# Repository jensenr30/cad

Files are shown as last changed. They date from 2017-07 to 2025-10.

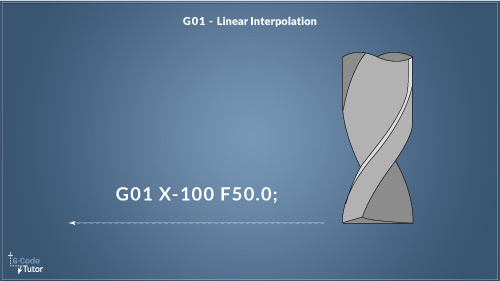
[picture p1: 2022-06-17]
cheatsheets/CNC G Codes_files/g01-gcode.jpg

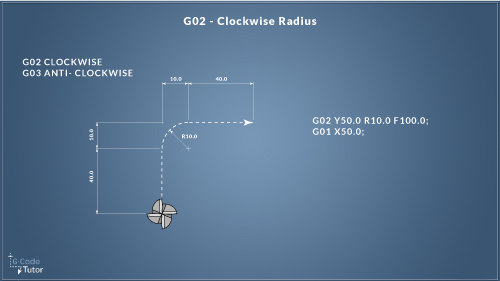
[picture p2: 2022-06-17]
cheatsheets/CNC G Codes_files/g02-g03-gcode.jpg

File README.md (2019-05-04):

# Ryan's CAD Files (Schematics, PCBs, Simulations)

## kicad5
I started using KiCad 5.1.2 to draw schematics and lay out PCBs in May 2019.

## kicad4
I used KiCad 4.0.6 for 3 weeks in September 2017. The two projects I completed are:
* [Shift-Register Break-Out-Board](/kicad4/SRBOB) - A modular daisy-chain-able serial-in-parallel-out 74hc595-based shift register circuit board.
* [XPhone Input Board](/kicad4/XPhone/Input_Board) - A quad transducer amplifier and glockenspiel-key-hit-detection circuit board.

## eagle6
Eagle was the first CAD program I ever used. I started using Eagle (on version 5.11.0) sometime in early 2011. I stopped on version 6.6.0 in mid 2017.  Some of the more interesting projects I completed using Eagle are:
* [Analog Synth](eagle6/Analog%20Synth) - a bunch of analog (and digital) DIY synth modules.  Designed, built, and tested by your truly.  This includes VCOs, VCFs, VCAs, sequencers, front-panel designs, digital delay, manual oscillators, and power-distribution interconnect PCBs.
* [Stroboscope](eagle6/Stroboscope) - a device that can turn on and off LEDs very fast (at audio frequencies) in order to produce interesting/useful/helpful visual effects.  A stroboscope can be used to enable a human to monitor the rotation of things in real time, e.g. fans, drills, wheels, motors, spinning objects, guitar strings, and any other object engaged in cyclic motion.
* [VU Meter](eagle6/VU%20meter) - a circuit that represents audio amplitude vertically on several bargraphs (each bargraph displays the amplitude of a given section of the audio spectrum).  The device can be used to build a real-time visual audio spectrum analyzer.
* [FreqCount84](eagle6/FreqCount84) - Atmel microcontroller-based design for precise measurement of frequency of square waves.  I believe the hwardware & firmware achieved an accuracy of ± a few ppm with the help of a 1.5 pm TCXO.
* [9x9 LED Matrix](eagle6/9x9%20LED%20Matrix) - a 2D array of LEDs (9 LEDs wide, 9 LEDs tall).  I remember wanting to build an array that had an odd number of pixels because it would allow me to make symetric visual displays.  I programmed a game of pong for this 9x9 LED Matrix.  That code exists in [my repo for Arduino programs](https://github.com/jensenr30/Arduino/tree/master/_DISPLAY/9x9_LED_Matrix).
* [Prototype Boards](eagle6/Prototype%20Boards) - three PCBs that enable DIY circuit construction.  0.1"-arrays of SMD pads, 0.1"-arrays of through-holes, SOT-to-DIP break-out-boards, SOIC-to-DIP break-out-boards, etc...

## LTspice IV
I have used [LTspice](https://en.wikipedia.org/wiki/LTspice) version IV to simulate some of my circuits.

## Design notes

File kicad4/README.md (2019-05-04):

# Jensen's KiCAD Projects
I Use KiCad 4 to view/edit my schematics, PCBs, symbols, and footprints.

I Use [gerbv](http://gerbv.geda-project.org/) to view the Gerber files.

I usually generate .pdf files for all my schematics and Gerber files once they are finished, so I can often view my schematics and layouts without having to install KiCad or gerbv.

## library
A collection of KiCad 4 schematic symbols.

## modules
A collection of KiCad 4 PCB footprints.

## XPhone
This is a collection of schematics and PCBs that are used as components of an electric xylophone (technically a glockenspiel).

### Input_Board
This is a module that will do process the input signals. The input signals are transduced by "pickup" coils mounted beneath each xylophone key. The input board:
- Amplifies the signal generated by the xylophone key
- detects the amplitude of the key hit (envelope detector circuit: a "super-diode" and a cap and a bleeder-resistor)
- outputs a pulse when the key is hit (hit detection pulse for a microcontroller to record what is being played by the user)

## SRBOB
This is a shift-register break-out-board. It is a modular, easily expandable shift register board. Each PCB has 4 SRBOB modules that must be cut apart. Each module can be populated with up to 4 74HC595 logic chips. The modules can be "daisy-chained" together to create

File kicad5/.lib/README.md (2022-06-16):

# Ryan Jensen's Custom KiCad 5 Library

Resist the temptation to rename files.

## Directories

| Directory  | Description of Directory |
| --- | --- |
| library | schematic symbols |
| modules | PCB footprints |
| packages3d | 3D models |

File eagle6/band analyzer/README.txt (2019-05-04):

I did not create this schematic, nor do I own this schematic.

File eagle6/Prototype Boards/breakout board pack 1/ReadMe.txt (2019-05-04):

I don't like how I routed the wires on the bottom for the SOIC-16.
That really sucks. I did not look close enough the first time.

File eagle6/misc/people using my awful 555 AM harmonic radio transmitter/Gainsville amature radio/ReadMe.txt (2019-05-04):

holy shit these people actually put my piece of shit circuit into their newsletter.
That is really pathetic.
The circuit was garbage.

But then again, it was fun.

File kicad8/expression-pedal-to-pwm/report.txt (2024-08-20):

Update symbol J5 from 'Connector:Screw_Terminal_01x06' to 'Connector:Screw_Terminal_01x06': OK

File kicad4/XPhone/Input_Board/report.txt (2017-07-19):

Info: Reading netlist file "A:\Engineering\kicad\XPhone\Input_Board\Input Board.net".

Info: Using references to match components and footprints.

Info: Checking netlist component footprint "C1:/5960E627:Capacitors_SMD:C_0603_HandSoldering".

Changing component "C1:/5960E627" pin "2" net name from "+12V" to "-12V".

Info: Checking netlist component footprint "C2:/5960E62D:Capacitors_SMD:C_0603_HandSoldering".

Changing component "C2:/5960E62D" pin "2" net name from "+12V" to "-12V".

Info: Checking netlist component footprint "C3:/593C8C44:Capacitors_SMD:C_0603_HandSoldering".

Info: Checking netlist component footprint "C4:/595F20F1:Capacitors_SMD:C_0603_HandSoldering".

Info: Checking netlist component footprint "C5:/5960E633:Capacitors_SMD:C_0603_HandSoldering".

Changing component "C5:/5960E633" pin "2" net name from "+12V" to "-12V".

Info: Checking netlist component footprint "C6:/5960E639:Capacitors_SMD:C_0603_HandSoldering".

Changing component "C6:/5960E639" pin "2" net name from "+12V" to "-12V".

Info: Checking netlist component footprint "C7:/593C8FC2:Capacitors_SMD:C_0603_HandSoldering".

Info: Checking netlist component footprint "C8:/595F20F7:Capacitors_SMD:C_0603_HandSoldering".

Info: Checking netlist component footprint "C9:/5960E64D:Capacitors_SMD:C_0603_HandSoldering".

Changing component "C9:/5960E64D" pin "2" net name from "+12V" to "-12V".

Info: Checking netlist component footprint "C10:/5960E653:Capacitors_SMD:C_0603_HandSoldering".

Changing component "C10:/5960E653" pin "2" net name from "+12V" to "-12V".

Info: Checking netlist component footprint "C11:/593CE812:Capacitors_SMD:C_0603_HandSoldering".

Info: Checking netlist component footprint "C12:/595F95F5:Capacitors_SMD:C_0603_HandSoldering".

Changing component "C12:/595F95F5" pin "2" net name from "+12V" to "-12V".

Info: Checking netlist component footprint "C13:/593CA10D:Capacitors_SMD:C_0603_HandSoldering".

Info: Checking netlist component footprint "C14:/595F2134:Capacitors_SMD:C_0603_HandSoldering".

Info: Checking netlist component footprint "C15:/593CA537:Capacitors_SMD:C_0603_HandSoldering".

Info: Checking netlist component footprint "C16:/595F2140:Capacitors_SMD:C_0603_HandSoldering".

Info: Checking netlist component footprint "C17:/595F675C:Capacitors_SMD:C_0603_HandSoldering".

Info: Checking netlist component footprint "C18:/595F7369:Capacitors_Tantalum_SMD:CP_Tantalum_Case-B_EIA-3528-21_Wave".

Info: Checking netlist component footprint "C19:/595F1A5B:Capacitors_SMD:C_0603_HandSoldering".

Info: Checking netlist component footprint "C20:/595F3A33:Capacitors_SMD:C_0603_HandSoldering".

Info: Checking netlist component footprint "C21:/595F1A61:Capacitors_SMD:C_0603_HandSoldering".

Info: Checking netlist component footprint "C22:/595F3A39:Capacitors_SMD:C_0603_HandSoldering".

Info: Checking netlist component footprint "C23:/595F1A9E:Capacitors_SMD:C_0603_HandSoldering".

Info: Checking netlist component footprint "C24:/595F3A76:Capacitors_SMD:C_0603_HandSoldering".

Info: Checking netlist component footprint "C25:/595F1AAA:Capacitors_SMD:C_0603_HandSoldering".

Info: Checking netlist component footprint "C26:/595F3A82:Capacitors_SMD:C_0603_HandSoldering".

Info: Checking netlist component footprint "J1:/593CBF86:Pin_Headers:Pin_Header_Straight_1x01_Pitch2.54mm".

Info: Checking netlist component footprint "J2:/595F21A5:Pin_Headers:Pin_Header_Straight_1x01_Pitch2.54mm".

Info: Checking netlist component footprint "J3:/593CC2F3:Pin_Headers:Pin_Header_Straight_1x01_Pitch2.54mm".

Info: Checking netlist component footprint "J4:/595F21B2:Pin_Headers:Pin_Header_Straight_1x01_Pitch2.54mm".

Info: Checking netlist component footprint "J5:/593CC6F7:Pin_Headers:Pin_Header_Straight_1x01_Pitch2.54mm".

Info: Checking netlist component footprint "J6:/595F21B8:Pin_Headers:Pin_Header_Straight_1x01_Pitch2.54mm".

Info: Checking netlist component footprint "J7:/595F1B0F:Pin_Headers:Pin_Header_Straight_1x01_Pitch2.54mm".

Info: Checking netlist component footprint "J8:/595F3AE7:Pin_Headers:Pin_Header_Straight_1x01_Pitch2.54mm".

Info: Checking netlist component footprint "J9:/595F1B1C:Pin_Headers:Pin_Header_Straight_1x01_Pitch2.54mm".

Info: Checking netlist component footprint "J10:/595F3AF4:Pin_Headers:Pin_Header_Straight_1x01_Pitch2.54mm".

Info: Checking netlist component footprint "J11:/595F1B22:Pin_Headers:Pin_Header_Straight_1x01_Pitch2.54mm".

Info: Checking netlist component footprint "J12:/595F3AFA:Pin_Headers:Pin_Header_Straight_1x01_Pitch2.54mm".

Info: Checking netlist component footprint "J13:/5969566C:Pin_Headers:Pin_Header_Straight_1x03_Pitch2.54mm".

Changing component "J13:/5969566C" pin "3" net name from "+12V" to "-12V".

Info: Checking netlist component footprint "J14:/59698210:Pin_Headers:Pin_Header_Straight_1x03_Pitch2.54mm".

Changing component "J14:/59698210" pin "3" net name from "+12V" to "-12V".

Info: Checking netlist component footprint "L1:/593C96E8:Pin_Headers:Pin_Header_Straight_1x02_Pitch2.54mm".

Info: Checking netlist component footprint "L2:/595F210F:Pin_Headers:Pin_Header_Straight_1x02_Pitch2.54mm".

Info: Checking netlist component footprint "L3:/595F1A79:Pin_Headers:Pin_Header_Straight_1x02_Pitch2.54mm".

Info: Checking netlist component footprint "L4:/595F3A51:Pin_Headers:Pin_Header_Straight_1x02_Pitch2.54mm".

Info: Checking netlist component footprint "Q1:/593C7DD5:TO_SOT_Packages_SMD:SOT-323_SC-70_Handsoldering".

Info: Checking netlist component footprint "Q2:/595F20EB:TO_SOT_Packages_SMD:SOT-323_SC-70_Handsoldering".

Info: Checking netlist component footprint "Q3:/593CA6EF:TO_SOT_Packages_SMD:SOT-323_SC-70_Handsoldering".

Info: Checking netlist component footprint "Q4:/595F2152:TO_SOT_Packages_SMD:SOT-323_SC-70_Handsoldering".

Info: Checking netlist component footprint "Q5:/595F1A55:TO_SOT_Packages_SMD:SOT-323_SC-70_Handsoldering".

Info: Checking netlist component footprint "Q6:/595F3A2D:TO_SOT_Packages_SMD:SOT-323_SC-70_Handsoldering".

Info: Checking netlist component footprint "Q7:/595F1ABC:TO_SOT_Packages_SMD:SOT-323_SC-70_Handsoldering".

Info: Checking netlist component footprint "Q8:/595F3A94:TO_SOT_Packages_SMD:SOT-323_SC-70_Handsoldering".

Info: Checking netlist component footprint "R1:/593C94A2:Resistors_SMD:R_0603_HandSoldering".

Info: Checking netlist component footprint "R2:/595F2103:Resistors_SMD:R_0603_HandSoldering".

Info: Checking netlist component footprint "R3:/593CC107:Resistors_SMD:R_0603_HandSoldering".

Info: Checking netlist component footprint "R4:/595F21AB:Resistors_SMD:R_0603_HandSoldering".

Info: Checking netlist component footprint "R5:/593C930A:Resistors_SMD:R_0603_HandSoldering".

Info: Checking netlist component footprint "R6:/595F20FD:Resistors_SMD:R_0603_HandSoldering".

Info: Checking netlist component footprint "R7:/595FC853:Resistors_SMD:R_0603_HandSoldering".

Info: Checking netlist component footprint "R8:/593CA5BF:Resistors_SMD:R_0603_HandSoldering".

Info: Checking netlist component footprint "R9:/595F2146:Resistors_SMD:R_0603_HandSoldering".

Info: Checking netlist component footprint "R10:/593CA779:Resistors_SMD:R_0603_HandSoldering".

Info: Checking netlist component footprint "R11:/593CA670:Resistors_SMD:R_0603_HandSoldering".

Info: Checking netlist component footprint "R12:/595F2158:Resistors_SMD:R_0603_HandSoldering".

Info: Checking netlist component footprint "R13:/595F214C:Resistors_SMD:R_0603_HandSoldering".

Info: Checking netlist component footprint "R14:/593CA7ED:Resistors_SMD:R_0603_HandSoldering".

Info: Checking netlist component footprint "R15:/595F215E:Resistors_SMD:R_0603_HandSoldering".

Info: Checking netlist component footprint "R16:/593CB19A:Resistors_SMD:R_0603_HandSoldering".

Info: Checking netlist component footprint "R17:/595F2196:Resistors_SMD:R_0603_HandSoldering".

Info: Checking netlist component footprint "R18:/595F1A6D:Resistors_SMD:R_0603_HandSoldering".

Info: Checking netlist component footprint "R19:/595F3A45:Resistors_SMD:R_0603_HandSoldering".

Info: Checking netlist component footprint "R20:/595F1B15:Resistors_SMD:R_0603_HandSoldering".

Info: Checking netlist component footprint "R21:/595F3AED:Resistors_SMD:R_0603_HandSoldering".

Info: Checking netlist component footprint "R22:/595F1A67:Resistors_SMD:R_0603_HandSoldering".

Info: Checking netlist component footprint "R23:/595F3A3F:Resistors_SMD:R_0603_HandSoldering".

Info: Checking netlist component footprint "R24:/595F1AB0:Resistors_SMD:R_0603_HandSoldering".

Info: Checking netlist component footprint "R25:/595F3A88:Resistors_SMD:R_0603_HandSoldering".

Info: Checking netlist component footprint "R26:/595F1AC2:Resistors_SMD:R_0603_HandSoldering".

Info: Checking netlist component footprint "R27:/595F1AB6:Resistors_SMD:R_0603_HandSoldering".

Info: Checking netlist component footprint "R28:/595F3A9A:Resistors_SMD:R_0603_HandSoldering".

Info: Checking netlist component footprint "R29:/595F3A8E:Resistors_SMD:R_0603_HandSoldering".

Info: Checking netlist component footprint "R30:/595F1AC8:Resistors_SMD:R_0603_HandSoldering".

Info: Checking netlist component footprint "R31:/595F3AA0:Resistors_SMD:R_0603_HandSoldering".

Info: Checking netlist component footprint "R32:/595F1B00:Resistors_SMD:R_0603_HandSoldering".

Info: Checking netlist component footprint "R33:/595F3AD8:Resistors_SMD:R_0603_HandSoldering".

Info: Checking netlist component footprint "RV1:/593C956D:Potentiometers:Potentiometer_Trimmer_Bourns_3296W".

Info: Checking netlist component footprint "RV2:/595F212D:Potentiometers:Potentiometer_Trimmer_Bourns_3296W".

Info: Checking netlist component footprint "RV3:/595F1A97:Potentiometers:Potentiometer_Trimmer_Bourns_3296W".

Info: Checking netlist component footprint "RV4:/595F3A6F:Potentiometers:Potentiometer_Trimmer_Bourns_3296W".

Info: Checking netlist component footprint "U1:/593C797A:Housings_DIP:DIP-8_W7.62mm".

Changing component "U1:/593C797A" pin "4" net name from "+12V" to "-12V".

Info: Checking netlist component footprint "U2:/59620FB2:TO_SOT_Packages_THT:TO-92_Inline_Narrow_Oval".

Info: Checking netlist component footprint "U3:/593CCBBC:SMD_Packages:SOIC-14_N".

Changing component "U3:/593CCBBC" pin "11" net name from "+12V" to "-12V".

Info: Checking netlist component footprint "U4:/593CBADD:Housings_DIP:DIP-14_W7.62mm".

Info: Checking netlist component footprint "U5:/595F1A4F:Housings_DIP:DIP-8_W7.62mm".

Changing component "U5:/595F1A4F" pin "4" net name from "+12V" to "-12V".

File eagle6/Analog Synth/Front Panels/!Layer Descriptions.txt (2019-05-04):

 44	Drills
 
100	FrontPanel
		This is an outline that shows how large the panel will be
		
101	PartProfile
		This is the layer that shows the size of the components behind the panel.
		It helps to see how close components can be packed together without hitting each other.
		
102	PanelSupportRails
		(the boards that the front panels connect to )
		
103	MiscProfile

104 PanelText
		this has all of the text that will show up on the finished front panel

105 Artwork
		This is the layer that contains all panel artwork

110 hole_size
		This layer contains a bunch of text that indicates what diameter the holes are.

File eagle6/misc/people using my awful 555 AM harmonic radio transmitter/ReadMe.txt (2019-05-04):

2018-06-11
Ryan Jensen

I have so much less respect for these organizations/websites now.
I see they will post articles about articles about electronics radios that are not designed properly.
Just goes to show that the internet is a echo chamber of people reposting other people's bullshit.
You really have to be skeptical.
Because people will write with authority about stuff that doesn't fucking work.

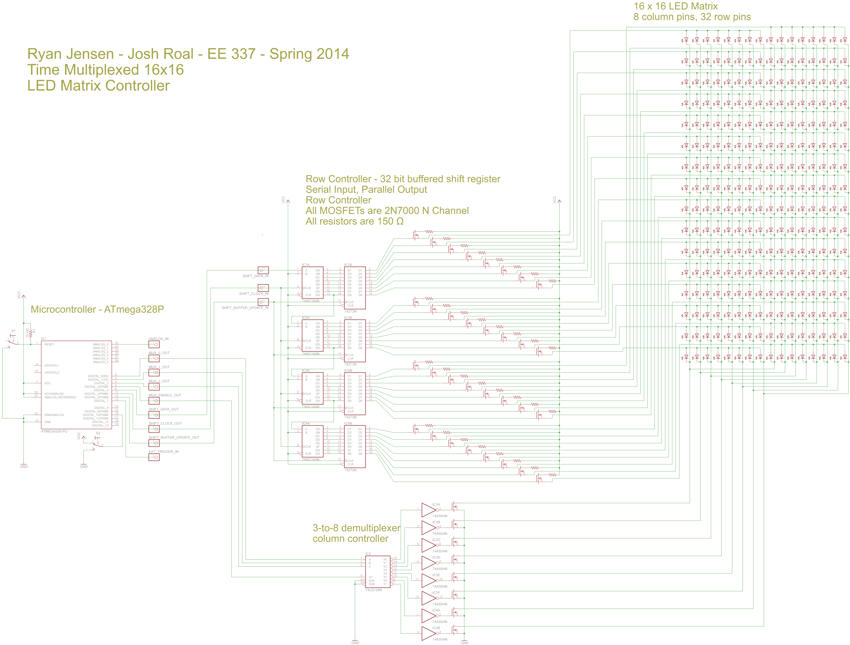
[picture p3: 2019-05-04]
eagle6/Digital Oscilloscope - EE 337 - Junior Design Project/ScreenshotSmall.png

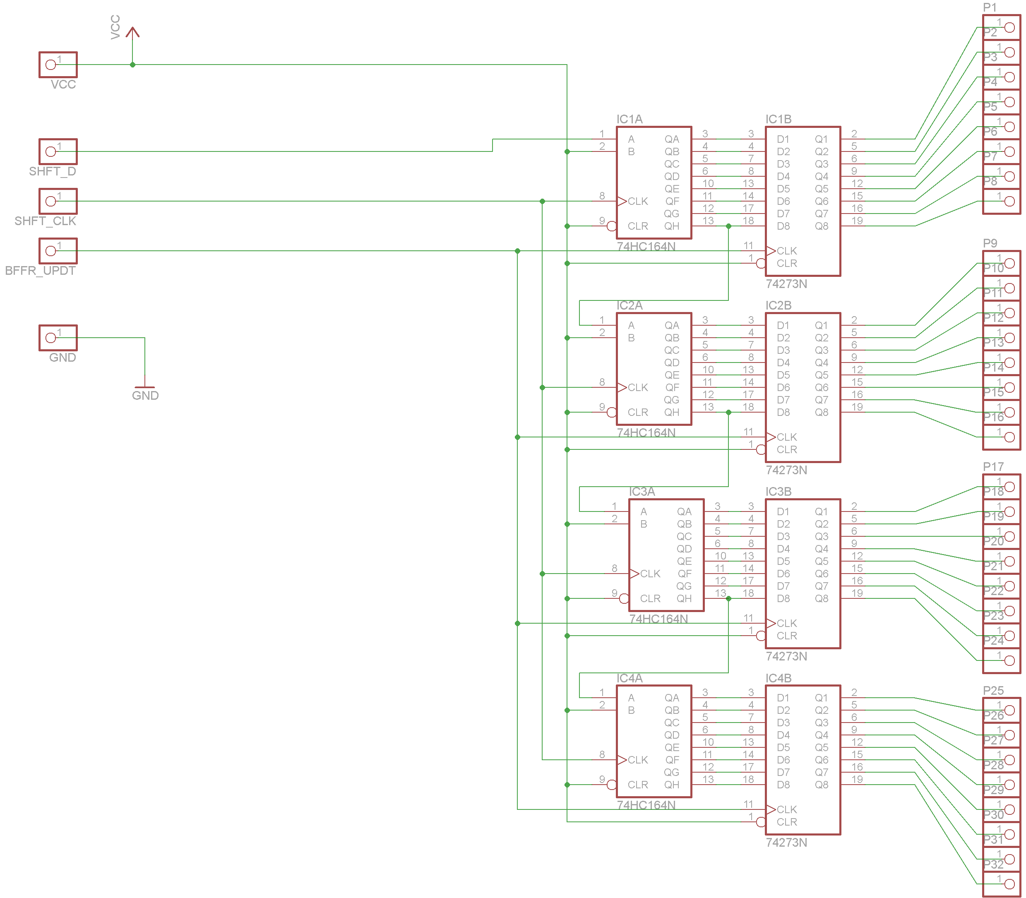
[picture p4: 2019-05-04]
eagle6/32 bit buffered shift register/Schematic.png

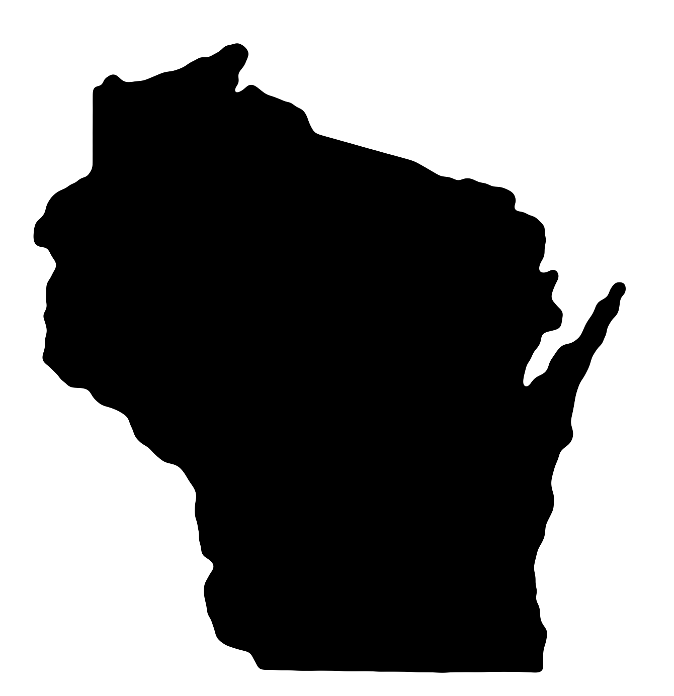
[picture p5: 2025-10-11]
src/geography/u.s. states/wisconsin/wisconsin-silhouette-smooth-2.png

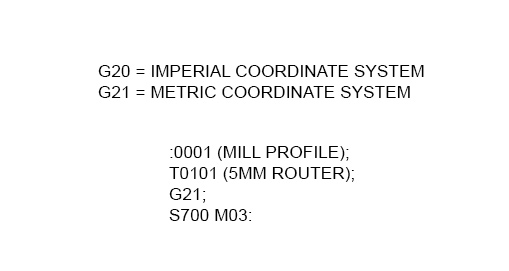
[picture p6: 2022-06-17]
cheatsheets/CNC G Codes_files/g20-g21-gcode.jpg

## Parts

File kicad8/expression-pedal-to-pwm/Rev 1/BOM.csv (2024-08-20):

Reference | Value | Datasheet | Footprint | Qty | DNP
C1 C3 C9 | 10u | ~ | Capacitor_THT:CP_Radial_D5.0mm_P2.50mm | 3
C2 C4 C6 C7 C10 | 100n | ~ | Capacitor_SMD:C_0603_1608Metric_Pad1.08x0.95mm_HandSolder | 5
C5 | 10n | ~ | Capacitor_SMD:C_0603_1608Metric_Pad1.08x0.95mm_HandSolder | 1
C8 | 47n | ~ | Capacitor_SMD:C_0603_1608Metric_Pad1.08x0.95mm_HandSolder | 1
C11 | 1000u | ~ | Capacitor_THT:CP_Radial_D10.0mm_P5.00mm | 1
D1 | RB088LAM-60TR | ~ | Diode_SMD:D_SOD-128 | 1
D2 D3 D4 D5 D6 D7 | SK18 | https://diotec.com/request/datasheet/sk12.pdf | Diode_SMD:D_SMA | 6
D8 D9 | LED | ~ | LED_THT:LED_D3.0mm_Horizontal_O3.81mm_Z6.0mm | 2
HS1 | Heatsink | https://www.mouser.com/datasheet/2/433/board-level-heatsink-wakefield-275537.pdf | Heatsink:Heatsink_Fischer_SK104-STCB_35x13mm__2xDrill3.5mm_ScrewM3 | 1
J4 | NMJ6HHD2 | https://www.neutrik.com/en/product/nmj6hhd2 | Connector_Audio:Jack_6.35mm_Neutrik_NMJ6HHD2_Horizontal | 1
J5 | Screw_Terminal_01x06 | ~ | TerminalBlock_MetzConnect:TerminalBlock_MetzConnect_Type086_RT03406HBLC_1x06_P3.81mm_Horizontal | 1
Q1 | STP100N8F6 | https://www.mouser.com/datasheet/2/389/stp100n8f6-1851325.pdf | Package_TO_SOT_THT:TO-220-3_Vertical | 1
R1 R2 | 100K | ~ | Resistor_SMD:R_0603_1608Metric_Pad0.98x0.95mm_HandSolder | 2
R3 | 1K | ~ | Resistor_SMD:R_0603_1608Metric_Pad0.98x0.95mm_HandSolder | 1
R4 R5 R8 R9 | 1k | ~ | Resistor_SMD:R_0603_1608Metric_Pad0.98x0.95mm_HandSolder | 4
R6 | 100 | ~ | Resistor_SMD:R_0603_1608Metric_Pad0.98x0.95mm_HandSolder | 1
R7 | 1M | ~ | Resistor_SMD:R_0603_1608Metric_Pad0.98x0.95mm_HandSolder | 1
RV1 RV2 RV3 | 100k | ~ | -- mixed values -- | 3
SW1 SW2 | SW_Push_DPDT | ~ | Button_Switch_THT:SW_E-Switch_EG2219_DPDT_Angled | 2
U1 | TLV2374 | ~ | Package_SO:SOIC-14_3.9x8.7mm_P1.27mm | 1
U2 | LM7805_TO220 | https://www.onsemi.cn/PowerSolutions/document/MC7800-D.PDF | Package_TO_SOT_THT:TO-220-3_Vertical | 1

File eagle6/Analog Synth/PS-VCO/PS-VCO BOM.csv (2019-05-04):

Qty | Value | Device | Package | Parts | Description
1 | EURORACK-POWER | EURORACK-POWER | EURORACK-POWER | U$3
1 | I/O | MONO_JACK | MONO_JACK | SQUARE
1 | 180k | R-US_R0603 | R0603 | R8 | RESISTOR, American symbol
1 | 1.8k | R-US_R0603 | R0603 | R7 | RESISTOR, American symbol
5 | 100k | R-US_R0603 | R0603 | R6, R9, R10, R13, R15 | RESISTOR, American symbol
1 | 120k | R-US_R0603 | R0603 | R5 | RESISTOR, American symbol
1 | 27k | R-US_R0603 | R0603 | R4 | RESISTOR, American symbol
1 | 33k | R-US_R0603 | R0603 | R22 | RESISTOR, American symbol
1 | 3.3k | R-US_R0603 | R0603 | R20 | RESISTOR, American symbol
1 | 4.7k | R-US_R0603 | R0603 | R19 | RESISTOR, American symbol
3 | 2.2k | R-US_R0603 | R0603 | R16, R17, R18 | RESISTOR, American symbol
1 | 68k | R-US_R0603 | R0603 | R14 | RESISTOR, American symbol
2 | 4.7 | R-US_R0603 | R0603 | R11, R12 | RESISTOR, American symbol
4 | 47k | R-US_R0603 | R0603 | R1, R2, R3, R21 | RESISTOR, American symbol
1 | 2N7000 | 2N7000 | 2N7000 | Q5
2 | 2N3904 | 2N3904 | TO92 | Q3, Q4 | NPN TRANSISTOR
1 | 2N3906 | 2N3906 | TO92 | Q2 | PNP Transistor
1 | BC847BS | BC847BS | SOT363_PHILIPS | Q1 | NPN general purpose double transistor
2 |  | LED_ELD260 | LED_LD260 | LED1, LED2 | LED
1 |  | PINHD-2X5 | 2X05 | JP2 | PIN HEADER
1 | TL084D | TL084D | SO14 | IC1 | OP AMP
1 | 100k lin | TRIM_US-B64Y | B64Y | FREQ | POTENTIOMETER
1 | CV | MONO_JACK | MONO_JACK | CV
1 | 10n | C-EUC0603 | C0603 | C6 | CAPACITOR, European symbol
2 | 100u | CPOL-USE2.5-7 | E2,5-7 | C4, C7 | POLARIZED CAPACITOR, American symbol
1 | 100p | C-EUC0603 | C0603 | C3 | CAPACITOR, European symbol
5 | 100n | C-EUC0603 | C0603 | C1, C2, C5, C8, C9 | CAPACITOR, European symbol

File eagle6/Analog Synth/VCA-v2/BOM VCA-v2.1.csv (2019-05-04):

Qty | Value | Device | Package | Parts | Description
2 | 0.01µ | C-EUC0603 | C0603 | C6, C7 | CAPACITOR, European symbol
5 | 100k | R-US_R0603 | R0603 | R5, R13, R21, R22, R23 | RESISTOR, American symbol
2 | 100k Log | TRIM_US-B64Y | B64Y | AUDIO-LVL, CV-LVL | POTENTIOMETER
2 | 100µ | C-US025-050X050 | C025-050X050 | C2, C3 | CAPACITOR, American symbol
2 | 10K | R-US_R0603 | R0603 | R17, R19 | RESISTOR, American symbol
2 | 10k | R-US_R0603 | R0603 | R8, R12 | RESISTOR, American symbol
1 | 10k Lin | TRIM_US-B64Y | B64Y | CV-MAN | POTENTIOMETER
1 | 10k TRIM | TRIM_US-B64Y | B64Y | BALANCE | POTENTIOMETER
1 | 10µ | C-US025-050X050 | C025-050X050 | C1 | CAPACITOR, American symbol
2 | 1K | R-US_R0603 | R0603 | R15, R16 | RESISTOR, American symbol
1 | 2.2K | R-US_R0603 | R0603 | R14 | RESISTOR, American symbol
1 | 2.2k | R-US_R0603 | R0603 | R4 | RESISTOR, American symbol
2 | 3.3k | R-US_R0603 | R0603 | R20, R24 | RESISTOR, American symbol
5 | 47k | R-US_R0603 | R0603 | R2, R9, R10, R11, R18 | RESISTOR, American symbol
2 | 6.8k | R-US_R0603 | R0603 | R1, R3 | RESISTOR, American symbol
2 | 7.5 | R-US_R0603 | R0603 | R6, R7 | RESISTOR, American symbol
1 | DMMT3904W | DMMT3904W | SOT363 | T1
1 | EURORACK-POWER | EURORACK-POWER | EURORACK-POWER | U$1
3 | I/O | MONO_JACK | MONO_JACK | AUDIO-IN, AUDIO-OUT, CV-IN
1 | DSC2001 | DSC2001 | SOT23-BEC | T2 | NPN Transistror
1 | TL084D | TL084D | SO14 | IC2 | OP AMP
3 | TLLG4400 | TLLG4400 | LED3MM | LED-AUDIO-IN, LED-AUDIO-OUT, LED-CV | Low Current (2mA) LED 3 mm Tinted Diffused Package color GREEN

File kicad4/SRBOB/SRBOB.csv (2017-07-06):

Reference | Value | Footprint | Datasheet
U1 | 74HC595 | Housings_DIP:DIP-16_W7.62mm
U2 | 74LS595 | Housings_DIP:DIP-16_W7.62mm
U3 | 74LS595 | Housings_DIP:DIP-16_W7.62mm
U4 | 74LS595 | Housings_DIP:DIP-16_W7.62mm
J3 | CONN_01X08 | Pin_Headers:Pin_Header_Straight_1x08_Pitch2.54mm
J4 | CONN_01X08 | Pin_Headers:Pin_Header_Straight_1x08_Pitch2.54mm
J5 | CONN_01X08 | Pin_Headers:Pin_Header_Straight_1x08_Pitch2.54mm
J6 | CONN_01X08 | Pin_Headers:Pin_Header_Straight_1x08_Pitch2.54mm
J1 | CONN_01X08 | Pin_Headers:Pin_Header_Straight_1x08_Pitch2.54mm
J2 | CONN_01X08 | Pin_Headers:Pin_Header_Straight_1x08_Pitch2.54mm

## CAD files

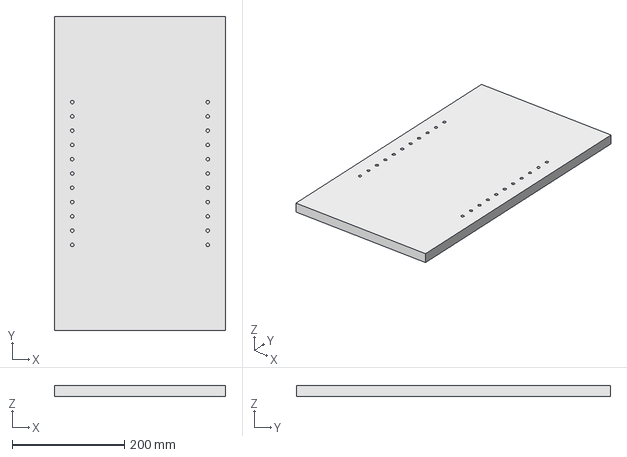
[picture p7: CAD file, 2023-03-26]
FreeCad/woodworking/cabinet-side-holes/cabinet-side-holes.FCStd
304.8 x 558.8 x 19.0 mm

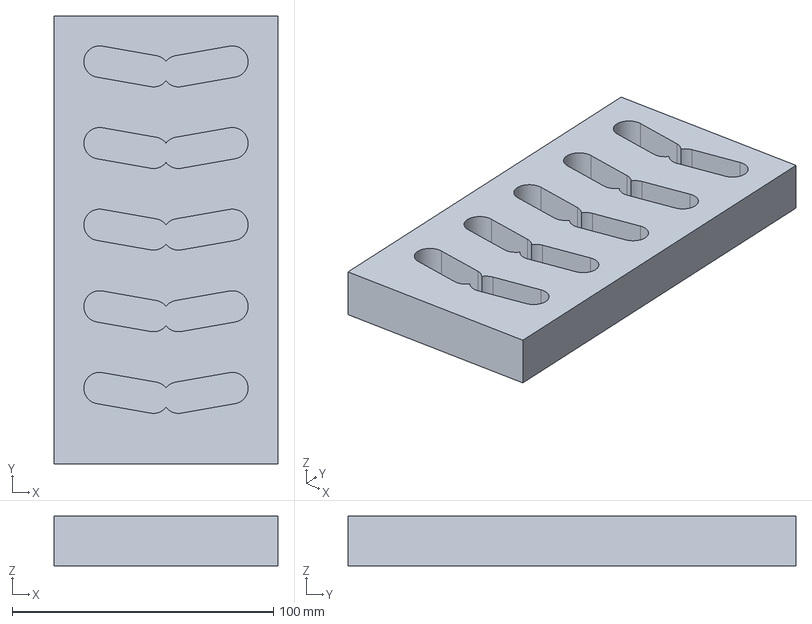
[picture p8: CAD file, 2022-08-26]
FreeCad/woodworking/napkin holder/napkin holder v2.2.FCStd
85.7 x 171.4 x 19.1 mm

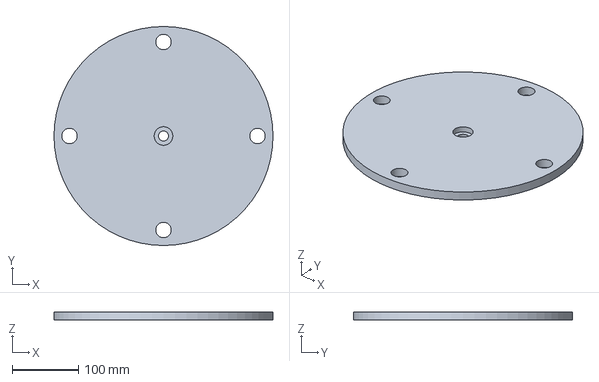
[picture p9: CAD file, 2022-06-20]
FreeCad/woodworking/silent susan/silent susan v6.FCStd
330.2 x 330.2 x 12.7 mm

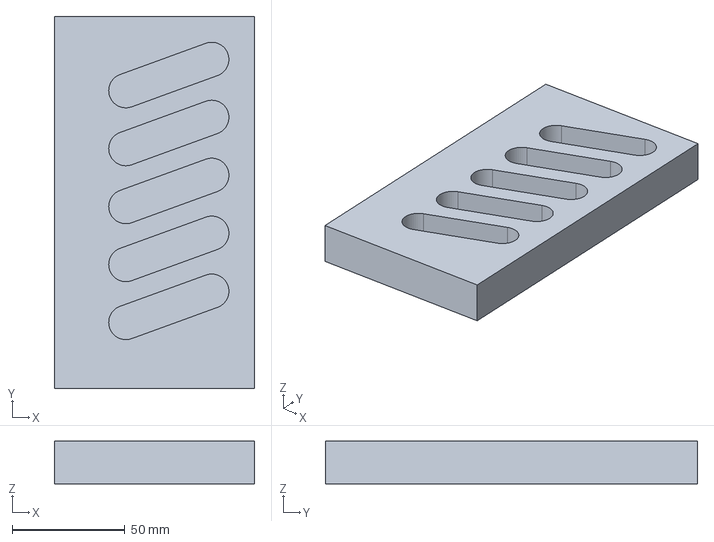
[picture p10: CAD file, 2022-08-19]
FreeCad/woodworking/napkin holder/napkin holder v3 right side.FCStd
88.9 x 165.1 x 19.1 mm

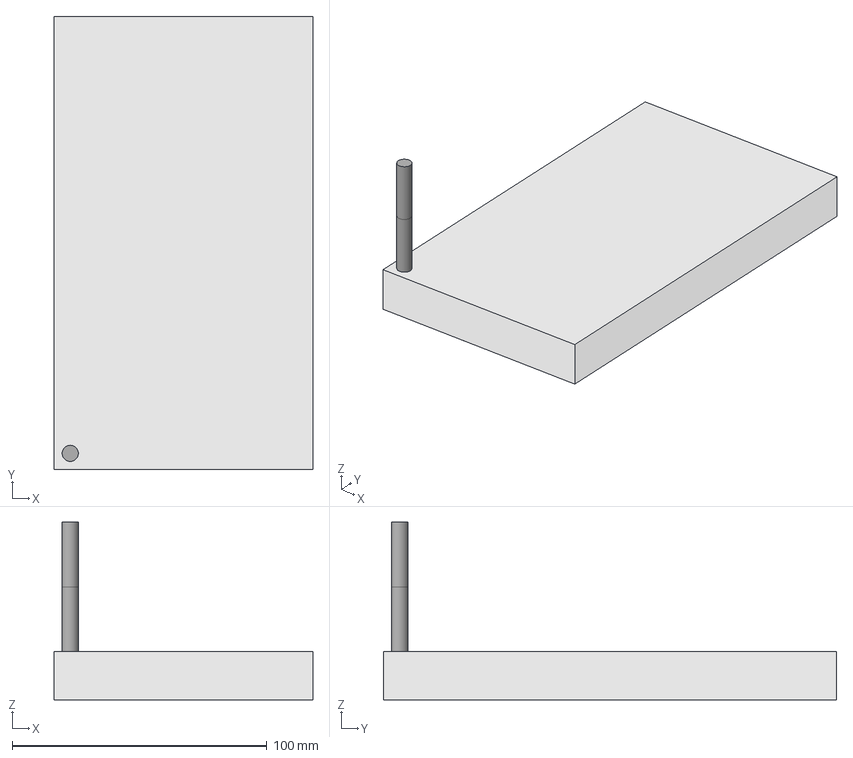
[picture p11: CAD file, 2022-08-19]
FreeCad/woodworking/napkin holder/napkin holder v3 left side.FCStd
101.6 x 177.8 x 69.8 mm
Model-napkin holder
Stock
Endmill
0.250 in Endmill

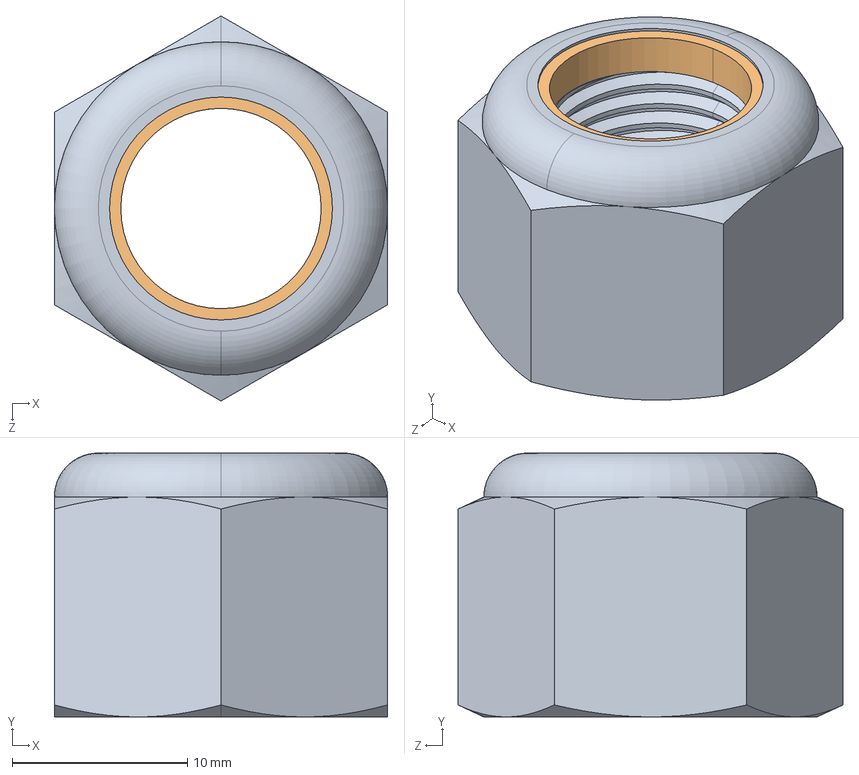
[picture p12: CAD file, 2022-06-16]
FreeCad/woodworking/silent susan/parts/95615A220_Medium-Strength Steel Nylon-Insert Locknut.STEP
19.1 x 15.1 x 22.0 mm

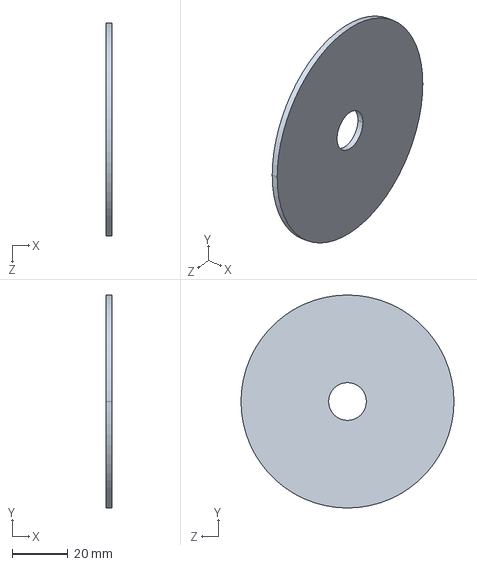
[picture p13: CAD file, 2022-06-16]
FreeCad/woodworking/silent susan/parts/98264A300_Zinc-Plated Steel Oversized Washer.STEP
2.03 x 76.2 x 76.2 mm

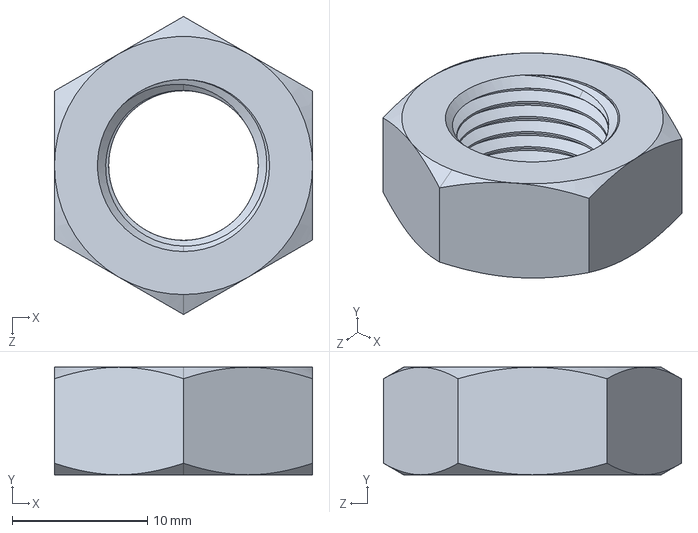
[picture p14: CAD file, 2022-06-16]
FreeCad/woodworking/silent susan/parts/92053A130_High-Strength Steel Thin Hex Nuts--Grade 8.STEP
19.1 x 7.94 x 22.0 mm

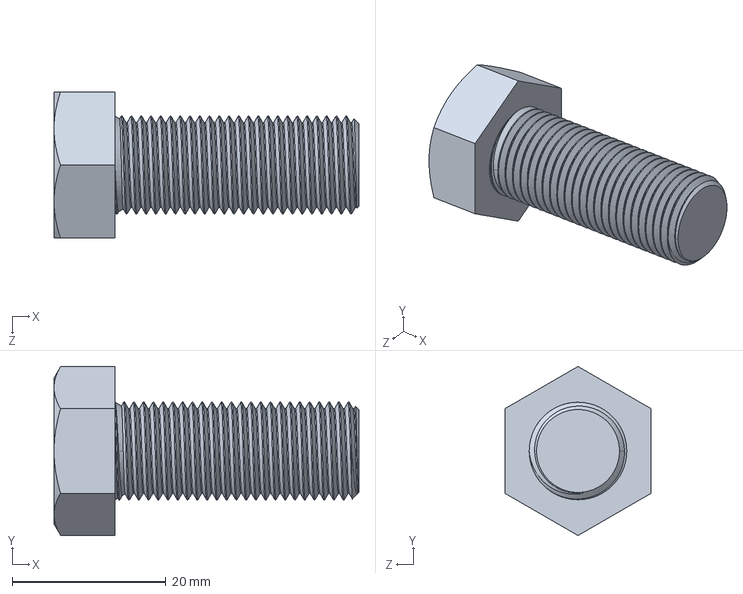
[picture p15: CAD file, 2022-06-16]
FreeCad/woodworking/silent susan/parts/91286A368_High-Strength Grade 8 Steel Hex Head Screw.STEP
39.7 x 22.0 x 19.1 mm

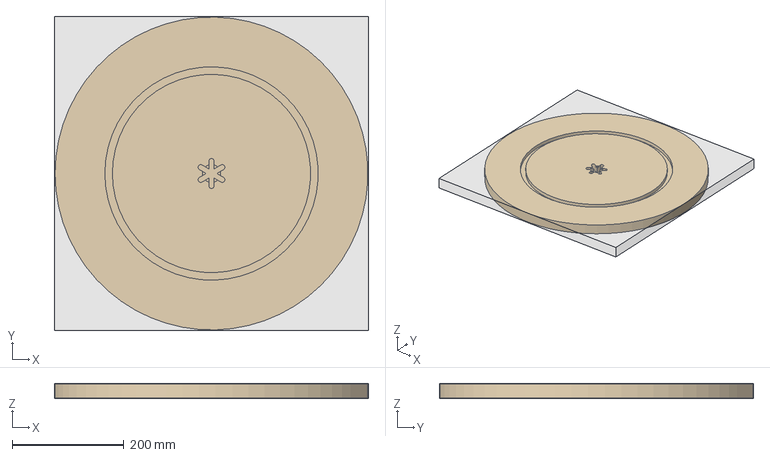
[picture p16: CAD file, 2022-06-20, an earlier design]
FreeCad/woodworking/silent susan/silent susan v5.FCStd
560.8 x 560.8 x 27.4 mm
Model-silent susan top
Stock

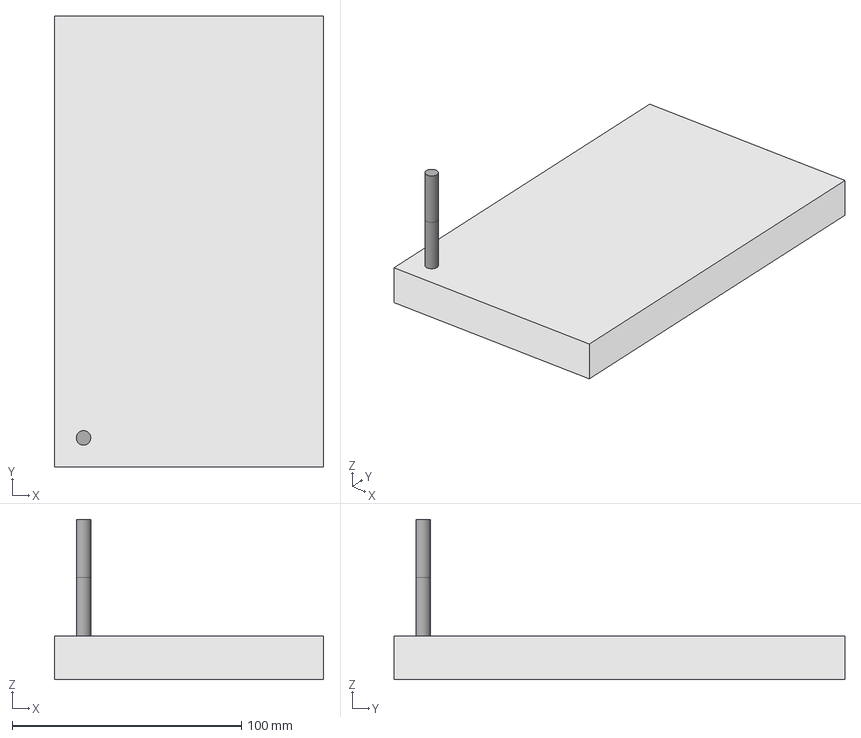
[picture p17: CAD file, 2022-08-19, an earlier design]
FreeCad/woodworking/napkin holder/napkin holder v2.FCStd
117.5 x 196.8 x 69.8 mm
Model-Body
Stock
Endmill
0.250 in Endmill

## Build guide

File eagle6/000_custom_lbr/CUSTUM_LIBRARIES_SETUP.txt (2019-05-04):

Ryan Jensen - 2014

T0 use these custom eagle libraries, just drag and drop them into your eagle libraries directory.

To find this directory,
	open Eagle.exe
	click "Option" at the top of the window
	click "Directories..."
	Then look at the box that says "Libraries"
	If the box has "$EAGLEDIR\lbr" in it, then it will be in your eagle install directory.
	Check C:\Program Files (x86)\EAGLE-x.x.x\lbr\
	
Then just copy the files into this folder.

ALTERNATIVELY,
You can make a shortcut to my 000_custom_lbr folder, and put the schortcut (.lnk) in the libraries folder of Eagle.
Doing this will make it impossible to "Open Symbol" when in schematic view.
Eagle will tell you it cannot find the library for the part you are using, but everything else will work just fine.

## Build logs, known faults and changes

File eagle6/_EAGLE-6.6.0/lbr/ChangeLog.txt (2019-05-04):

EAGLE Library ChangeLog
=======================

2014-05-23
  * microphon.lbr: Eagle 6.5.4
    added:
    TOM-1545P-R.PAC

2014-05-23
  * transistor-power.lbr: Eagle 6.5.4
    added:
    BTS5215L.DEV
    FDS6890A.DEV
    M08A.PAC
    PG-DSO-12-9.PAC

2014-05-23
  * speaker.lbr: Eagle 6.5.4
    added:
    SMS-1308MS-2-R.DEV
    SMS-1308MS-2-R.PAC

2014-05-23
  * pinhead.lbr: Eagle 6.5.4
    added:
    PINHD-1X70.DEV
    PINHD-1X100.DEV
    1X70.PAC
    1X100.PAC
    1_05X2MM.PAC

2014-05-16
  * con-phoenix-3.81.lbr: Eagle 6.5.4
    added:
    1803497.DEV
    1803549.DEV
    1803497.PAC

2013-10-07
  * marks.lbr: Eagle 6.5.1
    deleted:
    PASSER-SMD
    added:
    PASSER-CIRCLE.PAC

2013-09-17
  * memory-micron.lbr: Eagle 6.5.1
    renamed devices:
    MT48LC16M16A2 > MT48LC64M4A2
    MT48LC64M4A2 > MT48LC16M16A2

2013-08-27
  * con-conrad.lbr: Eagle 6.5.1
    package extended: 736880-49.DEV

2013-08-27
  * dc-dc-converter.lbr: Eagle 6.5.1
    corrected pin connection: VA-*D01.DEV

2013-07-02
  * display-lcd.lbr: Eagle 6.4.4
    added:
    EA_DIP.DEV
    EA_DIP.PAC

2013-06-25
  * zetex.lbr: Eagle 6.4.3
    corrected device: PN_MOSFET-.DEV, N-Channel

2013-05-07
  * optocoupler.lbr: Eagle 6.4.2
    corrected web adress of data sheet: MOC30*.DEV

2013-05-06
  * atmel.lbr: Eagle 6.4.2
    deleted: Package variant M at ATMEGA644.DEV, false package dimension.
    The correct package used in ATMEGA644*.DEV variant M.

2013-05-06
  * st-microelectronics.lbr: Eagle 6.4.2
    added:
    LSM303DLHC.DEV
    LGA-14.PAC

2013-04-24
  * aplus.lbr: Eagle 6.4.2
    added:
    APR9600_DIP-28.DEV
    APR9600_SOP-28.DEV
    DIP254P1525X550-28P.PAC
    SOP50P1030X264-28N.PAC

2013-04-23
  * opto-vishay.lbr: Eagle 6.4.2
    added:
    TSSP6P38.DEV
    TSSP6P38.PAC

2013-04-09
  * maxim.lbr: Eagle 6.4.2
    corrected description of devices: TRANSEIVER to TRANSCEIVER

2013-02-22
  * transistor.lbr: Eagle 6.4.1
    description corrected:
    SOT89-ECB.PAC
    SOT89-BCE.PAC

2013-02-05
  * con-ptr500.lbr: Eagle 6.4.1
    corrected package: AK500/6-H.DEV => AK500/-6H.PAC

2013-01-25
  * atmel.lbr: Eagle 6.4.0
    added:
    MLF20-4X4.PAC
    AT90S2313.DEV package variant V (MLF)

2013-01-21
  * frames.lbr: Eagle 6.4.0
    text deleted in packages: "Sheet:" ">SHEET"

2012-12-17
  * rcl.lbr: Eagle 6.3.2
    corrected package outlines:
    RTRIM3296P.PAC
    RTRIM3296W.PAC
    RTRIM3296X.PAC
    RTRIM3296Y.PAC

2012-11-28
  * relay.lbr: Eagle 6.3.2
    package contour corrected: DIL06.PAC

2012-11-28
  * zetex.lbr: Eagle 6.3.2
    changed symbols and corrected connection: *.DEV

2012-11-20
  * jumper.lbr: Eagle 6.3.1
    corrected pad coordinates: JP2Q.PAC

2012-11-12
  * con-coax.lbr: Eagle 6.3.1
    changed all devices with new connect option, multipin any/all: *.DEV

2012-11-08
  * e-schuetze-relais.lbr: Eagle 6.3.1
    corrected pad names:
    RELAIS_2-POL-UM.DEV
    RELAIS_4-POL-UM.DEV

2012-11-05
  * logo.lbr: Eagle 6.3.1
    added:
    CE-4MM.PAC
    C_TICK.PAC
    FCC_6.1X15MM.PAC
    FCC_10X4.175MM.PAC
    FCC_20X8.35MM.PAC

2012-11-05
  * inductors.lbr: Eagle 6.3.1
    renamed: BML15H.DEV to BLM15H.DEV

2012-10-30
  * eagle-ltspice.lbr: Eagle 6.3.1
    added: for beta version ltspice.ulp
    C.DEV
    DIODE_E-.DEV
    L.DEV
    LED_E.DEV
    R.DEV
    SCHOTTKY-DIODE.DEV

2012-10-01
  * texas.lbr: Eagle 6.2.3
    added:
    TLC4501.DEV
    TLC4502.DEV

2012-09-03
  * dc-dc-converter.lbr: Eagle 6.2.2
    added:
    R-78C*-1.0.DEV
    SIP3.PAC

2012-09-03
  * con-lumberg.lbr: Eagle 6.2.2
    corrected pads: KLBR4.PAC

2012-08-29
  * switch.lbr: Eagle 6.2.3
    added:
    3PDT.DEV
    3PDT.PAC

2012-08-28
  * relay.lbr: Eagle 6.2.2
    added:
    APF30212A.DEV
    APF30212C.DEV
    APF30212A.PAC
    APF30212C.PAC

2012-08-21
  * relay.lbr: Eagle 6.2.2
    corrected Set/Reset coil: DS2E-L-*.DEV

2012-08-10
  * switch-alps.lbr: Eagle 6.2.2
    corrected symbol coordinate: EC12E_SW.DEV

2012-08-09
  * allegro.lbr: Eagle 6.2.2
    Pads extended for Version 6:
    ACS75050.PAC
    CB-PFF.PAC
    ACS758*.DEV
    ACS750*CA-050.DEV

2012-07-09
  * 19inch.lbr: Eagle 6.2.2
    corrected package variant : VG96P -> VG64P

2012-07-09
  * ftdichip.lbr: Eagle 6.2.2
    added:
    FT230X.DEV
    QFN16.PAC
    SSOP16.PAC

2012-07-04
  * st-microelectronics.lbr: Eagle 6.2.2
    added:
    STGIPS10K60A.DEV
    SDIP-25L.PAC

2012-06-13
  * relay.lbr: Eagle 6.2.1
    added:
    JV*-KT.DEV
    JV-KT.PAC

2012-06-06
  * intersil-techwell.lbr: Eagle 6.2.1
    added:
    TW9920.DEV
    VFBGA100L-8X8.PAC

2012-06-05
  * relay.lbr: Eagle 6.2.1
    added:
    JW1A.DEV
    JW1C.DEV
    JW2A.DEV
    JW2C.DEV
    JW1A.PAC
    JW1C.PAC
    JW2A.PAC
    JW2C.PAC

2012-06-05
  * texas-sn55-sn75.lbr: Eagle 6.2.1
    added:
    SN75451B.DEV
    SN75452B.DEV
    SN75453B.DEV
    SN75454B.DEV
    DIL08.PAC
    D_R-PDSO-G8.PAC
    PS_R-PDSO-G8.PAC

2012-06-01
  * transistor-power.lbr: Eagle 6.2.1
    added:
    IRF8313P.DEV

2012-05-09
  * con-subd.lbr: Eagle 6.2.1
    added:
    M09SMT.PAC
    M15SMT.PAC
    M25SMT.PAC
    M37SMT.PAC

2012-04-25
  * philips-semiconductors.lbr: Eagle 6.2.1
    added:
    TDA1552Q.DEV
    MULTIWAT-SIL13.PAC

2012-04-19
  * trafo-hammondmfg.lbr: Eagle 6.2.0
    added:
    166.DEV
    C0H.PAC
    C1H.PAC
    C2H.PAC
    C3H.PAC
    C4H.PAC
    C5H.PAC
    C6H.PAC
    C7H.PAC
    C8H.PAC
    C9H.PAC
    C10H.PAC
    C11H.PAC
    C12H.PAC
    C13H.PAC
    C14H.PAC
    C15H.PAC
    C16H.PAC

2012-04-19
  * con-phoenix-350.lbr: Eagle 6.2.0
    added:
    MKKDS1/2-3,5.DEV
    MKKDS1/3-3,5.DEV
    MKKDS1/4-3,5.DEV
    MKKDS1/5-3,5.DEV
    MKKDS1/6-3,5.DEV
    MKKDS1/7-3,5.DEV
    MKKDS1/8-3,5.DEV
    MKKDS1/9-3,5.DEV
    MKKDS1/10-3,5.DEV
    MKKDS1/11-3,5.DEV
    MKKDS1/12-3,5.DEV
    MKKDS1/13-3,5.DEV
    MKKDS1/14-3,5.DEV
    MKKDS1/15-3,5.DEV
    MKKDS1/16-3,5.DEV
    MKKDS1/2-3,5.PAC
    MKKDS1/3-3,5.PAC
    MKKDS1/4-3,5.PAC
    MKKDS1/5-3,5.PAC
    MKKDS1/6-3,5.PAC
    MKKDS1/7-3,5.PAC
    MKKDS1/8-3,5.PAC
    MKKDS1/9-3,5.PAC
    MKKDS1/10-3,5.PAC
    MKKDS1/11-3,5.PAC
    MKKDS1/12-3,5.PAC
    MKKDS1/13-3,5.PAC
    MKKDS1/14-3,5.PAC
    MKKDS1/15-3,5.PAC
    MKKDS1/16-3,5.PAC

2012-04-18
  * microwave.lbr: Eagle 6.2.0
    added:
    HMC641LC4.DEV

2012-04-18
  * con-omron.lbr: Eagle 6.2.0
    added:
    XF3B-0845-31A.DEV
    XF3B-1945-31A.DEV
    XF3B-2545-31A.DEV
    XF3B-3545-31A.DEV
    XF3B-5145-31A.DEV
    XF3B-6745-31A.DEV
    XF3B-8.PAC
    XF3B-19.PAC
    XF3B-25.PAC
    XF3B-35.PAC
    XF3B-51.PAC
    XF3B-67.PAC

2012-04-16
  * lem.lbr: Eagle 6.2.0
    added:
    LA-*.DEV
    LA25P.PAC

2012-04-11
  * maxim.lbr: Eagle 6.1.5
    added:
    MAX8559.DEV
    TDFN8-3X3MM.PAC

2012-04-11
  * transistor-power.lbr: Eagle 6.1.5
    added:
    BSZ105N04NS.DEV

2012-04-04
  * cirrus-logic.lbr: Eagle 6.1.5
    added:
    CD161*-FSZ.DEV
    SOIC16.PAC

2012-04-02
  * con-amp-te.lbr: Eagle 6.1.5
    added:
    5749069-1.DEV
    5749069-2.DEV
    5749069-4.DEV
    5749069-5.DEV
    5749069-7.DEV
    5749069-8.DEV
    5749069-9.DEV
    5749069-1.PAC
    5749069-2.PAC
    5749069-4.PAC
    5749069-5.PAC
    5749069-7.PAC
    5749069-8.PAC
    5749069-9.PAC

2012-03-28
  * led.lbr: Eagle 6.1.5
    delete HOLE: NFSG036BT.PAC

2012-03-21
  * linear-technology.lbr: Eagle 6.1.4
    added:
    LTC2444.DEV
    LTC2445.DEV
    LTC2448.DEV
    LTC2449.DEV
    QFN38-5X7.PAC

2012-03-19
  * transistor.lbr: Eagle 6.1.3
    corrected technologie/package variant TO92-EBC of *-NPN-.PAC / *-PNP.PAC:
    MPSA04
    MPSA13
    MPSA14
    MPSA18
    MPSA28
    MPSA29
    MPSA42
    MPSA44
    MPSA92
    MPSA92

2012-03-16
  * optocoupler.lbr: Eagle 6.1.3
    added:
    PLT133/T9.DEV
    PLT133/T9.PAC

2012-03-16
  * con-amphenol.lbr: Eagle 6.1.3
    added:
    RCA-4-117-01.DEV
    RCA-4-117-01.PAC

2012-03-16
  * con-conrad.lbr: Eagle 6.1.3
    added:
    RCA-4-117-01.DEV
    RCA-4-117-01.PAC

2012-03-16
  * con-lumberg.lbr: Eagle 6.1.3
    added:
    RC-5231.DEV
    RC-5231.PAC

2012-03-15
  * transformer-pulse.lbr: Eagle 6.1.3
    added:
    PE-65612.DEV
    PE-65612.PAC

2012-03-14
  * micro-philips.lbr: Eagle 6.1.3
    added:
    LPC1102.DEV
    WLCSP16.PAC

2012-03-12
  * holes.lbr: Eagle 6.1.3
    deleted: circle and wire in layer t/bRestrict of PAD-packages

2012-03-12
  * texas.lbr: Eagle 6.1.3
    corrected: set device value on.
    BQ20*
    TLV*
    UC1*

2012-02-23
  * allegro.lbr: Eagle 6.1.3
    added:
    A3946.DEV
    TSSOP16E.PAC

2012-02-16
  * relay.lbr: Eagle 6.1.2
    added:
    FTR-B4.DEV
    FTR-B4C.PAC
    FTR-B4G.PAC
    FTR-B4S.PAC

2012-02-07
  * 74xx-little-de.lbr: Eagle 6.1.2
    added: 74*1G79.DEV finished

2012-01-25
  * relay.lbr: Eagle 6.1.1
    pad coordinate corrected:
    SF2D.PAC
    SF4D.PAC

2012-01-17
  * optocoupler.lbr: Eagle 6.1.0
    package corrected in Variant:
    SFH6186-2
    SFH6186-3
    SFH6186-4
    SFH6186-5

2012-01-17
  * avago.lbr: Eagle 6.1.0
    added:
    HCNR20*.DEV
    DIL08-400.PAC
    DIP8-400.PAC

2012-01-11
  * transistor.lbr: Eagle 6.0.2
    removed:
    *-NPN-2C-.DEV
    *-PNP-2C-.DEV
    PNP2.SYM

2011-12-28
  * microchip.lbr: Eagle 6.0.2
    added:
    PIC16*F1516/18.DEV
    PIC16*F1517/19.DEV
    UQFN28_4X4MM.PAC
    UQFN40ML5X5MM.PAC
    PIC16*F1826/27.DEV

2011-12-28
  * plcc-socket.lbr: Eagle 6.0.2
    added:
    PLCC86_635.PAC
    W9322.PAC
    W9323.PAC
    W9324.PAC
    W9325.PAC
    W9326.PAC
    W9327.PAC
    W9328.PAC

2011-12-27
  * con-harting.lbr: Eagle 6.0.2
    added:
    60010685132.PAC
    60010685232.PAC

2011-12-20
  * micro-philips.lbr: Eagle 6.0.1
    corrected package: HVQFN28.PAC

2011-12-19
  * con-garry.lbr: Eagle 6.0.1
    added:
    332-02.DEV
    332-04.DEV
    332-06.DEV
    332-08.DEV
    332-10.DEV
    332-12.DEV
    332-14.DEV
    332-16.DEV
    332-18.DEV
    332-20.DEV
    332-22.DEV
    332-24.DEV
    332-26.DEV
    332-28.DEV
    332-30.DEV
    332-32.DEV
    332-34.DEV
    332-36.DEV
    332-38.DEV
    332-42.DEV
    332-44.DEV
    332-46.DEV
    332-48.DEV
    332-50.DEV
    332-02.PAC
    332-04.PAC
    332-06.PAC
    332-08.PAC
    332-10.PAC
    332-12.PAC
    332-14.PAC
    332-16.PAC
    332-18.PAC
    332-20.PAC
    332-22.PAC
    332-24.PAC
    332-26.PAC
    332-28.PAC
    332-30.PAC
    332-32.PAC
    332-34.PAC
    332-36.PAC
    332-38.PAC
    332-42.PAC
    332-44.PAC
    332-46.PAC
    332-48.PAC
    332-50.PAC

2011-12-15
  * con-tyco.lbr: Eagle 6.0.1
    added:
    D1200D-4.DEV
    D1200D-6.DEV
    D1200D-8.DEV
    D1200D-10.DEV
    D1200D-12.DEV
    D1200D-16.DEV
    D1200D-20.DEV
    D1200D-4.PAC
    D1200D-6.PAC
    D1200D-8.PAC
    D1200D-10.PAC
    D1200D-12.PAC
    D1200D-16.PAC
    D1200D-20.PAC

2011-12-05
  * diode.lbr: Eagle 5.91.5
    changed: all devices and symbols with multi connection pins and extended pattern

2011-12-01
  * quantum-research-group.lbr: Eagle 5.91.4
    packages with extended pad:
    ROTOR-QUANTUM-20MM.PAC
    ROTOR_E1106_40MM.PAC

2011-12-01
  * lumiled.lbr: Eagle 5.91.4
    changed: all devices and symbols with multi connection pins

2011-12-01
  * led.lbr: Eagle 5.91.4
    changed: all devices and symbols with multi connection pins

2011-11-25
  * con-faston.lbr: Eagle 5.91.2
    changed: all devices and symbols with multi connection pins

2011-11-25
  * led-lumiled.lbr: Eagle 5.91.2
    changed: all devices and symbols with multi connection pins

2011-11-25
  * con-pulse.lbr: Eagle 5.91.2
    moved text >NAME in JP011.SYM on (-500 -2300) mil

2011-11-25
  * con-molex.lbr: Eagle 5.91.2
    changed: pin name in symbol AGND.SYM from A-GND@1 to AGND

2011-11-25
  * con-hirschmann.lbr: Eagle 5.91.2
    changed: all devices and symbols with multi connection pins

2011-11-25
  * chipcard-siemens.lbr: Eagle 5.91.2
    changed: all devices and symbols with multi connection pins

2011-11-23
  * transistor-small-signal.lbr: Eagle 5.91.2
    changed: all devices and symbols with multi connection pins

2011-11-23
  * transistor-power.lbr: Eagle 5.91.2
    changed: all devices and symbols with multi connection pins

2011-11-23
  * transistor-pnp.lbr: Eagle 5.91.2
    changed: all devices and symbols with multi connection pins

2011-11-23
  * transistor-npn.lbr: Eagle 5.91.2
     changed: all devices and symbols with multi connection pins

2011-11-22
  * transistor-fet.lbr: Eagle 5.91.2
    changed: all devices and symbols with multi connection pins

2011-11-22
  * transistor.lbr: Eagle 5.91.2
    changed: all devices and symbols with multi connection pins

2011-11-16
  * transistor-fet.lbr: Eagle 5.91.1
    added:
    2N4416.DEV

2011-11-16
  * transistor.lbr: Eagle 5.91.1
    deleted: 2N4416.DEV

2011-11-10
  * texas.lbr: Eagle 5.91.1
    added:
    TPS62120.DEV
    DCN-R-PDSO-G8.PAC
    BQ24022.DEV
    changed package (pad extension): DRC-S-PVSON-N10.PAC

2011-11-02
  * microchip.lbr: Eagle 5.11.2
    renamed: TQFP100.PAC to TQFP100-14X14.PAC
    added:
    DSPIC33FJ256GP710.DEV
    TQFP100-12X12.PAC

2011-11-02
  * trimble.lbr: Eagle 5.11.2
    added:
    A1919_AARDVARK.DEV
    B1919_BUFFALO.DEV
    C1011_CONDOR.DEV
    C1216_CONDOR.DEV
    C1722_CONDOR.DEV
    C1919A_CONDOR.DEV
    C1919B_CONDOR.DEV
    C1919C_CONDOR.DEV

2011-10-21
  * atmel.lbr: Eagle 5.11.2
    corrected pin direction: 250X0.SYM

2011-10-06
  * switch-reed.lbr: Eagle 5.11.2
    added:
    REED-SWITCH-NO-NC.DEV
    REED-SWITCH-.DEV
    CT10-A2.PAC
    CT10-G1.PAC
    CT10-G4.PAC
    MK6-4.PAC
    MK6-5.PAC
    MK6-6.PAC
    MK6-7.PAC
    MK6-8-A.PAC
    MK6-8-C.PAC
    MK6-10.PAC
    MK15.PAC

2011-10-05
  * transistor-power.lbr: Eagle 5.11.2
    added:
    BSC340N08NS3G.DEV
    PG-TDSON-8.PAC

2011-10-04
  * linear.lbr: Eagle 5.11.2
    corrected connection: TL331.DEV

2011-09-30
  * led.lbr: Eagle 5.11.2
    added:
    ML-E.DEV
    ML-E.PAC

2011-09-30
  * transistor-fet.lbr: Eagle 5.11.2
    corrected: FDD4141.DEV connection Drain, Source

2011-09-28
  * texas.lbr: Eagle 5.11.2
    added:
    SWRA092B.DEV
    SWRA092B.PAC

2011-09-28
  * inductors.lbr: Eagle 5.11.2
    added:
    BML15H.DEV
    0402.PAC

2011-09-28
  * crystal.lbr: Eagle 5.11.2
    added:
    FA-.DEV
    FC-12M.DEV
    FA-20H.PAC
    FA-128.PAC
    FC-12M.PAC

2011-09-27
  * lem.lbr: Eagle 5.11.2
    added:
    LA-100P.DEV
    LA100P.PAC

2011-09-27
  * johanson-technology.lbr: Eagle 5.11.2
    added:
    2450BM15A0002.DEV
    2450BM15A0002.PAC

2011-09-26
  * linear.lbr: Eagle 5.11.2
    added: LM2902.DEV Variant PT
    SSOP14.PAC

2011-09-26
  * con-amp.lbr: Eagle 5.11.2
    added:
    966140-5F.DEV
    966140-5F.PAC

2011-09-23
  * con-lumberg.lbr: Eagle 5.11.2
    corrected pad 1 and 3 (swaped): 1503_02.PAC

2011-09-20
  * texas.lbr: Eagle 5.11.2
    added:
    CC2540.DEV

2011-09-16
  * belton-engineering.lbr: Eagle 5.11.2
    added:
    VT9.DEV
    VT9-PT.PAC
    VT9-PT-C.PAC

2011-09-15
  * led.lbr: Eagle 5.11.2
    added:
    SPHWHTHAD605S0W0U4.DEV
    SPHWHTHAD605S0W0U4.PAC

2011-09-15
  * national-semiconductor.lbr: Eagle 5.11.2
    added:
    LM13600.DEV
    DIL16.PAC
    SO16.PAC
    SO16DW.PAC

2011-09-15
  * mitsubishi-semiconductor.lbr: Eagle 5.11.2
    added:
    M5218.DEV
    SOP8.PAC

2011-09-15
  * toshiba.lbr: Eagle 5.11.2
    added:
    TA7136AP.DEV
    SIP7-P-2.54.PAC

2011-09-08
  * traco-electronic.lbr: Eagle 5.11.2
    added:
    TES3.DEV
    TES3-.DEV
    TES3.PAC

2011-09-01
  * national-semiconductor.lbr: Eagle 5.11.1
    added:
    LM391.DEV
    DIL18.PAC
    PLCC20S.PAC

2011-09-01
  * st-microelectronics.lbr: Eagle 5.11.1
    added:
    L5973D.DEV
    HSOP8.PAC

2011-08-22
  * con-lumberg.lbr: Eagle 5.11.1
    corrected pad and hole position: 1501_06.PAC

2011-06-15
  * e-schuetze-relais.lbr: Eagle 5.11.1
    added:
    RELAIS_2-POL-UM.DEV
    RELAIS_4-POL-UM.DEV
    RELAIS_2-POL-UM.PAC
    RELAIS_4-POL-UM.PAC

2011-06-10
  * cirrus-logic.lbr: Eagle 5.11.1
    corrected library description: Digital Audio Receiver

2011-06-08
  * allegro.lbr: Eagle 5.11.1
    added:
    A3906.DEV
    QFN20.PAC

2011-06-01
  * e-schalter.lbr: Eagle 5.11.1
    added:
    LASTTRENNSCHALTER_4-POL.DEV
    LEISTUNGSSCHALTER_4-POL.DEV
    LASTTRENNSCHALTER_4-POL.PAC
    LEISTUNGSSCHALTER_4-POL.PAC

2011-05-31
  * inductor-nkl.lbr: Eagle 5.11.1
    renamed packages:
    B5�.PAC to B5O.PAC
    B6�-PAC to B6O.PAC

2011-05-26
  * texas.lbr: Eagle 5.11.1
    added:
    TMS320C5515.DEV
    UC*84.DEV
    UC*84?.DEV
    ZCH(S-PBGA-N196).PAC

2011-05-13
  * con-phoenix-500.lbr: Eagle 5.11.1
    corrected grid of all packages 5.08mm

2011-05-11
  * crystal.lbr: Eagle 5.11.1
    added:
    RV-3029-C2.DEV
    2450BL15B100.PAC
    SON-10.PAC

2011-05-04
  * diode.lbr: Eagle 5.11.1
    connection corrected: BAT54S.DEV

2011-05-04
  * microchip.lbr: Eagle 5.11.1
    added:
    PIC18F2*J53.DEV
    PIC18F4*J53ML.DEV
    PIC18F47J53PT.DEV

2011-05-02
  * wuerth-elektronik.lbr: Eagle 5.11.1
    deleted: please use actual library from www.cadsoft.de - download - libraries

2011-05-02
  * led.lbr: Eagle 5.11.1
    added:
    MX6-ALU.DEV
    MX6-ALU.PAC

2011-04-06
  * led.lbr: Eagle 5.11.1
    added:
    MX3.DEV
    MX6.DEV
    PB3XX301V050A.DEV
    MX6.PAC
    PB3XX301V050A.PAC

2011-04-05
  * st-microelectronics.lbr: Eagle 5.11.1
    added:
    L293DD.DEV

2011-03-21
  * maxim.lbr: Eagle 5.11.1
    corrected pin direction: MAX6520.SYM

2011-03-17
  * avago.lbr: Eagle 5.11.1
    added:
    ACPL-790.DEV

2011-03-16
  * pot.lbr: Eagle 5.11.1
    added:
    EVU.DEV
    US-EVU.DEV
    EVUE.PAC
    EVUEXK.PAC
    EVUEXXJ.PAC
    EVUF.PAC
    EVUFXJ.PAC
    EVUFXK.PAC
    EVUFXL.PAC
    EVUFXM.PAC

2011-03-15
  * con-kycon.lbr: Eagle 5.11.1
    added:
    KUSBVX-BS1N.DEV
    KUSBVX-BS1N.PAC

2011-03-15
  * con-fci.lbr: Eagle 5.11.1
    added:
    FSE310074.DEV
    FSE310074.PAC

2011-03-11
  * linear-technology.lbr: Eagle 5.11.1
    corrected pad coordinats: SSOP16.PAC

2011-03-09
  * 40xx.lbr: Eagle 5.11.1
    added:
    HEF40098B.DEV

2011-03-09
  * infineon.lbr: Eagle 5.11.1
    corrected package: P-TO220-7-11.PAC

2011-03-07
  * microchip.lbr: Eagle 5.11.1
    corrected package:
    PIC17C75XPT.DEV
    PIC32MX420F032H.DEV

2011-03-07
  * microchip.lbr: Eagle 5.11.1
    added:
    TQFP64-10X10X1MM.PAC

2011-03-01
  * relay.lbr: Eagle 5.11.1
    added:
    AQW27.DEV
    AQZ26.DEV
    CPC1708J.DEV
    I4-PAC.PAC

2011-02-28
  * con-wago.lbr: Eagle 5.11.1
    added:
    236.DEV
    236-4XX.PAC
    236-5XX.PAC
    236-6XX.PAC
    236-ABSCHLUSSPLATTE.PAC

2011-02-28
  * national-semiconductor.lbr: Eagle 5.11.1
    added:
    LME49600.DEV
    TS5B.PAC

2011-02-25
  * con-shallin.lbr: Eagle 5.11.1
    added:
    K375M.DEV
    K375M.PAC

2011-02-24
  * con-kycon.lbr: Eagle 5.11.1
    added:
    KUSBVX.DEV
    KUSBVX.PAC

2011-02-24
  * on-semiconductor.lbr: Eagle 5.11.1
    added:
    NCP2820.DEV
    FLIP-CHIP9.PAC

2011-02-15
  * led.lbr: Eagle 5.11.0
    added:
    Z-POWER-LED.DEV

2011-02-15
  * relay.lbr: Eagle 5.11.0
    corrcted: pin pad connection
    FTR-K1C.DEV

2011-01-31
  * led.lbr: Eagle 5.11.0
    added:
    CLN6A.DEV
    CLN6A.PAC
    CP41B.PAC

2011-01-26
  * rcl.lbr: Eagle 5.11.0
    corrected: pad names
    RTRIM3314J.PAC
    added:
    RTRIM3314G.PAC

2011-01-18
  * e-klemmen.lbr: Eagle 5.11.0
    added:
    KLEMME-2_50-BRUECKE.DEV
    KLEMME-2_50-BRUECKE.PAC

2011-01-17
  * trimble.lbr: Eagle 5.11.0
    added / created by: Trimble Germany GmbH - Christian Voit
    C1011.DEV
    C1216.DEV
    C1722.DEV
    C1919A.DEV
    C1919B.DEV
    C1919C.DEV
    COPERNICUS.DEV
    COPERNICUS-II.DEV
    ICM-SMT_10MHZ.DEV
    ICM-SMT_40MHZ.DEV
    RESOLUTION-SMT.DEV
    TRIMBLE-LOGO.DEV
    1011.PAC
    1216.PAC
    1722.PAC
    1919.PAC
    TRIMBLE-LOGO.PAC

2011-01-05
  * infineon.lbr: Eagle 5.11.0
    pin offgrtid corrected:
    TLE5205-2.SYM

2010-12-23
  * zetex.lbr: Eagle 5.11.0
    added:
    ZXLD1350.DEV
    DMN3024LSD.DEV
    ZXMD63N03X.DEV
    renamed:
    PMOS2MSOP8.DEV to PMOS2.DEV
    NMOS2MSOP8.DEV to NMOS2.DEV
    pin connection corrected:
    NMOS2.DEV (NMOS2MSOP8.DEV)

2010-12-22
  * ftdichip.lbr: Eagle 5.11.0
    added:
    FT232B.DEV
    LQFP32-7X7.PAC

2010-12-15
  * con-kycon.lbr: Eagle 5.11.0
    added:
    GLX-S-88M.DEV
    GLX-S-88M.PAC

2010-12-08
  * atmel.lbr: Eagle 5.10.3
    move pins in default grid:
    XMEGA16A4.SYM
    XMEGA128A1.SYM

2010-12-02
  * altera.lbr: Eagle 5.10.3
    added:
    EPM240F100.DEV
    EPM240M100.DEV
    EPM240T100C4.DEV
    FBGA100.PAC
    MBGA100.PAC

2010-12-02
  * con-coax.lbr: Eagle 5.10.3
    added:
    MC-921.DEV
    MC-921.PAC
    SMA-142-0701-871.PAC

2010-12-02
  * crystal.lbr: Eagle 5.10.3
    added:
    ASE.DEV
    ASE.PAC

2010-12-02
  * national-semiconductor.lbr: Eagle 5.10.3
    added:
    LM2936?*.DEV
    LM2936M?*.DEV
    LM2936MP?*.DEV
    MINI-SO8.PAC
    SOT223.PAC

2010-12-01
  * altera-cyclone-II.lbr: Eagle 5.10.2
  * con-amp-champ.lbr: Eagle 5.10.2
  * con-amp-micromatch.lbr: Eagle 5.10.2
  * con-amp-mt.lbr: Eagle 5.10.2
  * con-amp-mt6.lbr: Eagle 5.10.2
  * con-amp-quick.lbr: Eagle 5.10.2
  * con-amp.lbr: Eagle 5.10.2
  * con-amphenol.lbr: Eagle 5.10.2
  * con-avx.lbr: Eagle 5.10.2
  * con-weidmueller-sl35.lbr: Eagle 5.10.2
    added Farnell and Newark order codes

2010-11-30
  * con-wago.lbr: Eagle 5.10.3
    added Farnell and Newark order codes

2010-11-30
  * microchip.lbr: Eagle 5.10.3
    added Farnell and Newark order codes

2010-11-30
  * con-kyocera-elco.lbr: Eagle 5.10.3
    added Farnell and Newark order codes

2010-11-30
  * con-wago255.lbr: Eagle 5.10.3
    added Farnell and Newark order codes

2010-11-25
  * crystal.lbr: Eagle 5.10.3
    added Farnell and Newark order codes

2010-11-25
  * switch-misc.lbr: Eagle 5.10.3
    9077-1.DEV
    9077-2.DEV
    added: Distributor

2010-11-25
  * con-4ucon.lbr: Eagle 5.10.3
  * con-3m.lbr: Eagle 5.10.3
    added Farnell and Newark order codes

2010-11-24
  * con-berg.lbr: Eagle 5.10.2
  * con-bosch.lbr: Eagle 5.10.2
  * con-chipcard-iso7816.lbr: Eagle 5.10.2
  * con-coax.lbr: Eagle 5.10.2
  * con-commcon.lbr: Eagle 5.10.2
  * con-cpci.lbr: Eagle 5.10.2
  * con-cui.lbr: Eagle 5.10.2
  * con-cypressindustries.lbr: Eagle 5.10.2
  * con-deutsch.lbr: Eagle 5.10.2
  * con-ebyelectro.lbr: Eagle 5.10.2
  * con-elco.lbr: Eagle 5.10.2
  * con-erni.lbr: Eagle 5.10.2
  * con-faston.lbr: Eagle 5.10.2
  * con-fci.lbr: Eagle 5.10.2
  * con-friwo.lbr: Eagle 5.10.2
  * con-harting-h.lbr: Eagle 5.10.2
  * con-harting-ml.lbr: Eagle 5.10.2
  * con-harting-v.lbr: Eagle 5.10.2
  * con-harting.lbr: Eagle 5.10.2
  * con-hirose.lbr: Eagle 5.10.2
  * con-hirschmann.lbr: Eagle 5.10.2
  * con-jack.lbr: Eagle 5.10.2
  * con-jae.lbr: Eagle 5.10.2
  * con-jst.lbr: Eagle 5.10.2
  * con-kycon.lbr: Eagle 5.10.2
  * con-lemo.lbr: Eagle 5.10.2
  * con-leotronics.lbr: Eagle 5.10.2
  * con-lsta.lbr: Eagle 5.10.2
  * con-lstb.lbr: Eagle 5.10.2
  * con-lumberg.lbr: Eagle 5.10.2
  * con-ml.lbr: Eagle 5.10.2
  * con-molex.lbr: Eagle 5.10.2
  * con-neutrik_ag.lbr: Eagle 5.10.2
  * con-omron.lbr: Eagle 5.10.2
  * con-panasonic.lbr: Eagle 5.10.2
  * con-panduit.lbr: Eagle 5.10.2
  * con-phoenix-254.lbr: Eagle 5.10.2
  * con-phoenix-3.81.lbr: Eagle 5.10.2
  * con-phoenix-350.lbr: Eagle 5.10.2
  * con-phoenix-500.lbr: Eagle 5.10.2
  * con-phoenix-508.lbr: Eagle 5.10.2
  * con-phoenix-762.lbr: Eagle 5.10.2
  * con-phoenix-me_max.lbr: Eagle 5.10.2
  * con-phoenix-mkds_5.lbr: Eagle 5.10.2
  * con-phoenix-smkdsp.lbr: Eagle 5.10.2
  * con-ptr500.lbr: Eagle 5.10.2
  * con-pulse.lbr: Eagle 5.10.2
  * con-rib.lbr: Eagle 5.10.2
  * con-samtec.lbr: Eagle 5.10.2
  * con-shiua-chyuan.lbr: Eagle 5.10.2
  * con-stewart.lbr: Eagle 5.10.2
  * con-stocko.lbr: Eagle 5.10.2
  * con-subd.lbr: Eagle 5.10.2
  * con-sullinselectronics.lbr: Eagle 5.10.2
  * con-thomas-betts.lbr: Eagle 5.10.2
  * con-tyco.lbr: Eagle 5.10.2
  * con-tycoelectronics.lbr: Eagle 5.10.2
  * con-wago-500.lbr: Eagle 5.10.2
  * con-wago-508.lbr: Eagle 5.10.2
  * con-weidmueller-sl35.lbr: Eagle 5.10.2
  * con-wenzhou-yihua.lbr: Eagle 5.10.2
  * con-yamaichi.lbr: Eagle 5.10.2
    added Farnell and Newark order codes

2010-11-16
  * texas.lbr: Eagle 5.10.3
    added Farnell and Newark order codes

2010-11-16
  * relay.lbr: Eagle 5.10.3
    added Farnell and Newark order codes

2010-11-16
  * philips-semiconductors.lbr: Eagle 5.10.3
    added Farnell and Newark order codes

2010-11-16
  * on-semiconductor.lbr: Eagle 5.10.3
    added Farnell and Newark order codes

2010-11-16
  * linear-technology.lbr: Eagle 5.10.3
    added Farnell and Newark order codes

2010-11-16
  * maxim.lbr: Eagle 5.10.3
    added Farnell and Newark order codes

2010-11-12
  * crystal.lbr: Eagle 5.10.3
    added Farnell and Newark order codes

2010-11-12
  * atmel.lbr: Eagle 5.10.3
    added Farnell and Newark order codes:
    AT45DB161D.DEV

2010-11-12
  * altera-stratix-iv.lbr: Eagle 5.10.2
  * analog-devices.lbr: Eagle 5.10.2
  * burr-brown.lbr: Eagle 5.10.2
  * buzzer.lbr: Eagle 5.10.2
  * display-lcd.lbr: Eagle 5.10.2
  * exar.lbr: Eagle 5.10.2
  * inductor-nkl.lbr: Eagle 5.10.2
  * memory-idt.lbr: Eagle 5.10.2
  * micro-fujitsu.lbr: Eagle 5.10.2
  * microchip.lbr: Eagle 5.10.2
  * opto-transmittter-hp.lbr: Eagle 5.10.2
  * optocoupler.lbr: Eagle 5.10.2
  * resistor-power.lbr: Eagle 5.10.2
  * resistor-sil.lbr: Eagle 5.10.2
  * sipex.lbr: Eagle 5.10.2
  * switch-dil.lbr: Eagle 5.10.2
  * traco-electronic.lbr: Eagle 5.10.2
  * trafo-xicon.lbr: Eagle 5.10.2
    added Farnell and Newark order codes

2010-11-11
  * sim-technology.lbr: Eagle 5.10.3
    added:
    SIM340DZ.DEV
    SIM340DZ.PAC

2010-11-11
  * optocoupler.lbr: Eagle 5.10.3
    renamed package: DIL16/4-1\7.PAC -> DIL16-4_1_7_10_16.PAC

2010-11-10
  * rcl.lbr: Eagle 5.10.3
    added:
    C1808.PAC
    C3640.PAC

2010-11-10
  * halo-electronics.lbr: Eagle 5.10.3
    added:
    TG110-E*N5.DEV
    TG110-E050N5.DEV
    N5.PAC

2010-11-10
  * linear-technology.lbr: Eagle 5.10.3
    added:
    LT3434.DEV

2010-11-10
  * con-kyocera-elco.lbr: Eagle 5.10.3
    renamed:
    5036-008-210-862.DEV
    5036_006_2?_862.DEV
    5036_006_223_862.DEV
    5036_006_200_862.PAC
    5036_006_201_862.PAC
    5036_006_223_862.PAC
    5036_006_299_862.PAC
    5036_008_210_862.PAC

2010-11-05
  * con-kyocera-elco.lbr: Eagle 5.10.2
    added:
    5035_006_2?_862.DEV
    5035_006_223_862.DEV
    5036-008-210-862.DEV
    5035_006_200_862.PAC
    5035_006_201_862.PAC
    5035_006_223_862.PAC
    5035_006_299_862.PAC
    5035_008_210_862.PAC

2010-11-05
  * advanced-test-technologies.lbr: Eagle 5.10.2
  * agilent-technologies.lbr: Eagle 5.10.2
  * allegro.lbr: Eagle 5.10.2
  * altera-cyclone-II.lbr: Eagle 5.10.2
  * altera-cyclone-III.lbr: Eagle 5.10.2
  * altera-stratix-iv.lbr: Eagle 5.10.2
  * altera.lbr: Eagle 5.10.2
  * amd-mach.lbr: Eagle 5.10.2
  * amis.lbr: Eagle 5.10.2
  * austriamicrosystems.lbr: Eagle 5.10.2
  * avago.lbr: Eagle 5.10.2
  * c-trimm.lbr: Eagle 5.10.2
  * california-micro-devices.lbr: Eagle 5.10.2
  * chipcard-siemens.lbr: Eagle 5.10.2
  * cirrus-logic.lbr: Eagle 5.10.2
  * csr.lbr: Eagle 5.10.2
  * cypress.lbr: Eagle 5.10.2
  * davicom.lbr: Eagle 5.10.2
  * dc-dc-converter.lbr: Eagle 5.10.2
  * display-hp.lbr: Eagle 5.10.2
  * display-kingbright.lbr: Eagle 5.10.2
  * fairchild-semic.lbr: Eagle 5.10.2
  * fiber-optic-hp.lbr: Eagle 5.10.2
  * fiber-optic-siemens.lbr: Eagle 5.10.2
  * fifo.lbr: Eagle 5.10.2
  * flexipanel.lbr: Eagle 5.10.2
  * fox-electronics.lbr: Eagle 5.10.2
  * freescale.lbr: Eagle 5.10.2
  * ftdichip.lbr: Eagle 5.10.2
  * fujitsu.lbr: Eagle 5.10.2
  * fuse.lbr: Eagle 5.10.2
  * gennum.lbr: Eagle 5.10.2
  * holtek.lbr: Eagle 5.10.2
  * inductor-coilcraft.lbr: Eagle 5.10.2
  * inductor-neosid.lbr: Eagle 5.10.2
  * infineon-tricore.lbr: Eagle 5.10.2
  * infineon.lbr: Eagle 5.10.2
  * intersil.lbr: Eagle 5.10.2
  * ir.lbr: Eagle 5.10.2
  * isd.lbr: Eagle 5.10.2
  * lantronix.lbr: Eagle 5.10.2
  * lattice.lbr: Eagle 5.10.2
  * lc-filter.lbr: Eagle 5.10.2
  * led-7-segment.lbr: Eagle 5.10.2
  * led-citizen-electronics.lbr: Eagle 5.10.2
  * led-lumiled.lbr: Eagle 5.10.2
  * lem.lbr: Eagle 5.10.2
  * linx.lbr: Eagle 5.10.2
  * lprs.lbr: Eagle 5.10.2
  * lumiled.lbr: Eagle 5.10.2
  * maxstream.lbr: Eagle 5.10.2
  * melexis.lbr: Eagle 5.10.2
  * memory-hitachi.lbr: Eagle 5.10.2
  * memory-micron.lbr: Eagle 5.10.2
  * memory-motorola-dram.lbr: Eagle 5.10.2
  * memory-nec.lbr: Eagle 5.10.2
  * memory-samsung.lbr: Eagle 5.10.2
  * micrel.lbr: Eagle 5.10.2
  * micro-cyrod.lbr: Eagle 5.10.2
  * micro-harris.lbr: Eagle 5.10.2
  * micro-hitachi.lbr: Eagle 5.10.2
  * micro-infineon.lbr: Eagle 5.10.2
  * micro-intel.lbr: Eagle 5.10.2
  * micro-mc68000.lbr: Eagle 5.10.2
  * micro-motorola.lbr: Eagle 5.10.2
  * micro-philips.lbr: Eagle 5.10.2
  * micro-renesas.lbr: Eagle 5.10.2
  * micro-samsung.lbr: Eagle 5.10.2
  * micro-siemens.lbr: Eagle 5.10.2
  * micron.lbr: Eagle 5.10.2
  * micronas.lbr: Eagle 5.10.2
  * microwave.lbr: Eagle 5.10.2
  * midori-sensor.lbr: Eagle 5.10.2
  * minicircuits.lbr: Eagle 5.10.2
  * motorola-sensor-driver.lbr: Eagle 5.10.2
  * murata-filter.lbr: Eagle 5.10.2
  * murata-sensor.lbr: Eagle 5.10.2
  * nanotec.lbr: Eagle 5.10.2
  * national-instruments.lbr: Eagle 5.10.2
  * national-semiconductor.lbr: Eagle 5.10.2
  * nec.lbr: Eagle 5.10.2
  * nrj-semiconductor.lbr: Eagle 5.10.2
  * omnivision.lbr: Eagle 5.10.2
  * opto-honeywell-3000.lbr: Eagle 5.10.2
  * opto-honeywell-4000.lbr: Eagle 5.10.2
  * opto-honeywell.lbr: Eagle 5.10.2
  * opto-micro-linear.lbr: Eagle 5.10.2
  * opto-trans-siemens.lbr: Eagle 5.10.2
  * opto-vishay.lbr: Eagle 5.10.2
  * pal.lbr: Eagle 5.10.2
  * piher.lbr: Eagle 5.10.2
  * pld-intel.lbr: Eagle 5.10.2
  * plxtech.lbr: Eagle 5.10.2
  * pot-vitrohm.lbr: Eagle 5.10.2
  * pot-xicor.lbr: Eagle 5.10.2
  * ptc-ntc.lbr: Eagle 5.10.2
  * quantum-research-group.lbr: Eagle 5.10.2
  * recom-international.lbr: Eagle 5.10.2
  * renesas.lbr: Eagle 5.10.2
  * resistor-bourns.lbr: Eagle 5.10.2
  * resistor-dil.lbr: Eagle 5.10.2
  * resistor-net.lbr: Eagle 5.10.2
  * resistor-ruf.lbr: Eagle 5.10.2
  * resistor-shunt.lbr: Eagle 5.10.2
  * rf-micro-devices.lbr: Eagle 5.10.2
  * rf-solutions.lbr: Eagle 5.10.2
  * rohm.lbr: Eagle 5.10.2
  * sensor-comus-group.lbr: Eagle 5.10.2
  * sensor-heraeus.lbr: Eagle 5.10.2
  * sensor-infratec.lbr: Eagle 5.10.2
  * sharp.lbr: Eagle 5.10.2
  * silabs.lbr: Eagle 5.10.2
  * solomon-systech.lbr: Eagle 5.10.2
  * st-microelectronics.lbr: Eagle 5.10.2
  * supertex.lbr: Eagle 5.10.2
  * switch-alps.lbr: Eagle 5.10.2
  * switch-omron.lbr: Eagle 5.10.2
  * telcom.lbr: Eagle 5.10.2
  * telecontrolli.lbr: Eagle 5.10.2
  * telefunken.lbr: Eagle 5.10.2
  * toshiba.lbr: Eagle 5.10.2
  * trafo-bei.lbr: Eagle 5.10.2
  * trafo-siemens.lbr: Eagle 5.10.2
  * tripas.lbr: Eagle 5.10.2
  * u-blox.lbr: Eagle 5.10.2
  * v-reg-micrel.lbr: Eagle 5.10.2
  * wafer-scale-psd.lbr: Eagle 5.10.2
  * xicor.lbr: Eagle 5.10.2
  * xilinx-virtex-v5.lbr: Eagle 5.10.2
  * xilinx-xc18v.lbr: Eagle 5.10.2
  * xilinx-xc9.lbr: Eagle 5.10.2
  * xilinx-xcv.lbr: Eagle 5.10.2
  * zetex.lbr: Eagle 5.10.2
    added Farnell and Newark order codes

2010-11-04
  * rectifier.lbr: Eagle 5.10.2
    added:
    LC03-6.DEV
    SO08.PAC

2010-11-04
  * rcl.lbr: Eagle 5.10.2
    added:
    1812X7R.PAC

2010-11-04
  * discrete.lbr: Eagle 5.10.2
    added:
    T23-A230X.DEV
    T23-A230X.PAC

2010-11-04
  * linear.lbr: Eagle 5.10.2
    added:
    OP1177.DEV
    OP1277.DEV
    OP1477.DEV
    TSSOP14-RU.PAC

2010-10-29
  * mitsubishi-semiconductor.lbr: Eagle 5.10.2
    added:
    PS21962-ST.DEV
    PS21962-ST.PAC

2010-10-27
  * philips-semiconductors.lbr: Eagle 5.10.2
    added:
    TDA8029.DEV
    LQFP32-7X7MM.PAC

2010-10-27
  * linear.lbr: Eagle 5.10.2
    added:
    MC79M.DEV
    MC78M.DEV
    NCV78M.DEV

2010-10-27
  * diode.lbr: Eagle 5.10.2
    added:
    SMF5.0AT1.DEV
    SOD123FL.PAC

2010-10-27
  * switch-raychem.lbr: Eagle 5.10.2
    added:
    SMD*F.DEV
    SMDH120.DEV
    SMD050F.PAC

2010-10-12
  * inductors.lbr: Eagle 5.10.2
    added:
    P0762.*NL.DEV
    P0762NL.PAC

2010-10-12
  * lsi-computer-systems.lbr: Eagle 5.10.2
    added:
    LS7766DH.DEV
    LS7766DO.DEV
    LS7766SH.DEV
    LS7766SO.DEV
    DIL48.PAC
    SOIC16LWB.PAC
    SOIC18L.PAC
    SOIC20L.PAC
    SOIC24L.PAC
    SOIC28L.PAC
    TSSOP14.PAC
    TSSOP20.PAC
    TSSOP24.PAC
    TSSOP28.PAC
    TSSOP38.PAC
    TSSOP48.PAC

2010-10-11
  * em-microelectronic.lbr: Eagle 5.10.2
    added:
    EM4095.DEV
    SO16.PAC

2010-10-11
  * crystal.lbr: Eagle 5.10.2
    added:
    8M10AHC49T.DEV
    10.DEV
    10G.DEV
    10M*A.DEV
    10M*B.DEV
    10M*C.DEV
    10M?D.DEV
    12M10AHC49HT.DEV
    12M10BHC49T.DEV
    14M20BHC49T.DEV
    16M20AUM1.DEV
    17M15AUM1.DEV
    21M*A.DEV
    21M*B.DEV
    21M*C.DEV
    21M15D.DEV
    45M*A.DEV
    45M*B.DEV
    46M15AUM1.DEV
    46M15BUM5.DEV
    49M8AHC49T.DEV
    54M10AUM1.DEV
    54M10AUM5.DEV
    64M10AUM1.DEV
    64M10AUM5.DEV
    69M7AUM1.DEV
    70M*.DEV
    90M15A.DEV
    ECS.DEV
    ECS-.DEV
    F90M.DEV
    IXF.DEV
    MF_.DEV
    F11/8A.PAC
    F13/8A.PAC
    F15/12B.PAC
    F18/12P.PAC
    HC49U.PAC
    M-1.PAC
    M-2.PAC
    M-3.PAC
    M-4.PAC
    M-5.PAC
    M-6.PAC
    M-A.PAC
    SC-1.PAC
    SC-2.PAC
    SC-3.PAC
    SC-4.PAC
    SC-5.PAC
    UM-1S.PAC
    UM-4S.PAC
    UM-5S.PAC
    UM1.PAC
    UM4.PAC
    UM5.PAC

2010-10-07
  * atmel.lbr: Eagle 5.10.2
    added:
    AT45DB161D.DEV
    VDFN-8.PAC

2010-10-06
  * linear-technology.lbr: Eagle 5.10.2
    corrected package: LGA50.PAC

2010-10-04
  * texas.lbr: Eagle 5.10.2
    added:
    BQ78PL114.DEV
    P-QFP48-7X7MM.PAC

2010-09-30
  * maxim.lbr: Eagle 5.10.2
    added:
    MAX618.DEV

2010-09-30
  * transistor-power.lbr: Eagle 5.10.2
    added:
    IRF4905.DEV
    IRFP25*.DEV
    IRFZ48.DEV
    IRLZ44Z.DEV
    RD06HVF1.DEV
    RD15HVF1.DEV
    ST*60N10.DEV
    ISOWATT218.PAC
    RD06HVF1.PAC

2010-09-29
  * con-wago.lbr: Eagle 5.10.2
    added:
    254-84*.DEV
    254-200.PAC
    254-842.PAC

2010-09-29
  * con-wago255.lbr: Eagle 5.10.2
    added:
    255-401-5.DEV
    255-402-5.DEV
    255-403-5.DEV
    255-404-5.DEV
    255-405-5.DEV
    255-406-5.DEV
    255-407-5.DEV
    255-408-5.DEV
    255-409-5.DEV
    255-410-5.DEV
    255-412-5.DEV
    255-416-5.DEV
    255-424-5.DEV
    255-436-5.DEV
    255-448-5.DEV

2010-09-24
  * diode.lbr: Eagle 5.10.2
    added:
    MBRS3*0T3.DEV

2010-09-24
  * inductors.lbr: Eagle 5.10.2
    renamed :
    DR1010.DEV to DR1030.DEV
    DR1010.PAC to DR1030.PAC

2010-09-23
  * relay.lbr: Eagle 5.10.2
    renamed AQZ10OD.DEV  to AQZ10*D.DEV and add technoligies
    renamed AQZ20OD.DEV to AQZ20*D.DEV and add technoligies
   corrected Package AQZ-SIL04 with photomos_sil4.dxf from Panasonic

2010-09-23
  * optocoupler.lbr: Eagle 5.10.2
    added:
    MOCD20*M.DEV
    SOIC08-FAIRCHILD.PAC

2010-09-20
  * inductors.lbr: Eagle 5.10.2
    added:
    DR1010.DEV
    DR1010.PAC

2010-09-17
  * logo.lbr: Eagle 5.10.2
    added:
    CS-EAGLE-HOLE-LOGO-43MM.PAC
    CS-LOGO-41MM.PAC
    CS-LOGO-43MM.PAC
    CS-LOGO-45MM.PAC
    CS-LOGO-TOP-43MM.PAC
    EAGLE-CS-LOGO-43.PAC
    EAGLE-PLC-30MM.PAC

2010-09-16
  * on-semiconductor.lbr: Eagle 5.10.2
    added:
    A5191HRT.DEV
    A5191HRTI.DEV
    A5191HRTI.PAC
    LQFP32-7X7MM.PAC
    PLCC28.PAC

2010-09-16
  * led.lbr: Eagle 5.10.1
    added:
    L-59EGW-CA.DEV
    TLLG4400.DEV
    TLLR4400.DEV
    TLLY4400.DEV
    L-59EGW-CA.PAC

2010-09-14
  * con-wago-508.lbr: Eagle 5.10.1
    added:
    236-412.DEV
    236-412.PAC

2010-09-07
  * on-semiconductor.lbr: Eagle 5.10.1
    added:
    MDC3105DMT1.DEV
    MDC3105LT1.DEV
    MDC3105XV6T1.DEV
    SC-74.PAC
    SOT-563.PAC
    SOT23.PAC

2010-09-07
  * texas.lbr: Eagle 5.10.1
    added:
    TPS5410.DEV

2010-09-07
  * micro-philips.lbr: Eagle 5.10.1
    added:
    PCA9534.DEV
    HVQFN16_3X3.PAC
    HVQFN16_4X4.PAC
    TSSOP16.PAC

2010-09-07
  * crystal.lbr: Eagle 5.10.1
    added:
    CSM-7X-DU.DEV
    MC-306.DEV
    MC-405.DEV
    MC-406.DEV
    CSM-7X-DU.PAC
    MC-306.PAC
    MC-405.PAC
    MC-406.PAC

2010-09-07
  * linear.lbr: Eagle 5.10.1
    added:
    OPA333.DEV
    OPA2333.DEV

2010-09-07
  * switch-coto.lbr: Eagle 5.10.1
    added:
    CT10-XXXX-.DEV
    CT10-XXXX-A2.PAC
    CT10-XXXX-G1.PAC
    CT10-XXXX-G4.PAC

2010-08-30
  * optocoupler.lbr: Eagle 5.10.1
    connected variant 'T' 'S': MOC30*.DEV

2010-08-27
  * battery.lbr: Eagle 5.10.1
    corrected symbol and connection: CR2/3.DEV

2010-08-18
  * 74xx-us.lbr: Eagle 5.10.0
    corrected name: 74671.SYM Pin 'CASC'

2010-08-18
  * 74xx-eu.lbr: Eagle 5.10.0
    corrected name: 74671.SYM Pin 'CASC'

2010-08-13
  * con-vg.lbr: Eagle 5.10.0
    corrected misspelled word in description: FAE32E.PAC

2010-07-29
  * 74xx-eu.lbr: Eagle 5.10.0
    changed description: internal link add "DEVICE:"
    74*51.DEV
    74S51.DEV

2010-07-29
  * 74xx-us.lbr: Eagle 5.10.0
    changed description: internal link add "DEVICE:"
    74*51.DEV
    74S51.DEV

2010-07-29
  * microchip.lbr: Eagle 5.10.0
    changed description: internal link add "DEVICE:"
    PIC16C*.DEV
    PIC16F8*.DEV

2010-07-09
  * linear.lbr: Eagle 5.10.0
    corrected symbol: ERA-*.DEV

2010-07-08
  * con-lumberg.lbr: Eagle 5.10.0
    changed: CINCH_4.SYM moved pins '2@1' '2@2' '2@3'

2010-07-08
  * exar.lbr: Eagle 5.10.0
    changed: XR-2100.SY; Pin name 'uC/!STD' to 'UC/!STD'

2010-07-08
  * con-hirschmann.lbr: Eagle 5.10.0
    changed: 1O.SYM rename PIN 'ö' to 'O'

2010-06-14
  * transistor.lbr: Eagle 5.10.0
    corrected: all technologies of variant TO92-EBC

2010-06-09
  * texas.lbr: Eagle 5.10.0
    added:
    DS1232LP.DEV

2010-06-09
  * micro-cyrod.lbr: Eagle 5.10.0
    added:
    CRD89C51RD.DEV
    CRD89C51RD-DIL40.DEV
    CRD89C51RD-QFP44.DEV
    DIL40.PAC
    PLCC44.PAC
    SQFP-S-10X10-44.PAC

2010-06-09
  * relay.lbr: Eagle 5.10.0
    added:
    6561-0300.DEV
    6561-0300.PAC

2010-05-26
  * telefunken.lbr: Eagle 5.9.3
    added:
    U893BSE.DEV
    SO08.PAC

2010-05-26
  * philips-semiconductors.lbr: Eagle 5.9.3
    added:
    SAB6456.DEV
    DIL08.PAC
    SO08.PAC

2010-05-26
  * on-semiconductor.lbr: Eagle 5.9.3
    added:
    MC12052A.DEV
    MC12080.DEV
    SO08.PAC

2010-05-26
  * fujitsu.lbr: Eagle 5.9.3
    added:
    MB50.DEV
    SO08.PAC

2010-05-26
  * national-semiconductor.lbr: Eagle 5.9.3
    added:
    LMX2322.DEV
    TSSOP16.PAC

2010-05-26
  * nec.lbr: Eagle 5.9.3
    added:
    UPB1505.DEV
    SO08.PAC

2010-05-26
  * texas.lbr: Eagle 5.9.3
    added:
    ISO1176.DEV

2010-05-26
  * st-microelectronics.lbr: Eagle 5.9.3
    added:
    STM8S105C.DEV
    STM8S105K.DEV
    STM8S105K*B.DEV
    STM8S105S.DEV
    LQFP32-7X7.PAC
    LQFP44-10X10.PAC
    LQFP48-7X7.PAC
    SPDIP32.PAC
    UFQFPN32.PAC
    VFQFPN32.PAC

2010-05-21
  * con-amphenol.lbr: Eagle 5.9.3
    added:
    SIMLOCK-C707_10M006_512_2.DEV
    C707_10M006_512_2.PAC

2010-05-20
  * analog-devices.lbr: Eagle 5.9.3
    added:
    ADUC84*-52.DEV
    ADUC84*-56.DEV
    LFCSP56.PAC
    MQFP52.PAC

2010-05-20
  * fuse.lbr: Eagle 5.9.3
    added:
    QPL.DEV
    QPL.PAC

2010-05-20
  * con-phoenix-3.81.lbr: Eagle 5.9.3
    added:
    1727036.DEV
    1727036.PAC

2010-05-20
  * con-hirose.lbr: Eagle 5.9.3
    added:
    FH12-08S-1S.DEV
    FH12-10S-0.5S.DEV
    FH12-11S-0.5S.DEV
    FH12-12S-0.5S.DEV
    FH12-13S-0.5S.DEV
    FH12-14S-0.5S.DEV
    FH12-15S-0.5S.DEV
    FH12-16S-0.5S.DEV
    FH12-16S-1S.DEV
    FH12-17S-0.5S.DEV
    FH12-18S-0.5S.DEV
    FH12-19S-0.5S.DEV
    FH12-20S-0.5S.DEV
    FH12-20S-1S.DEV
    FH12-22S-0.5S.DEV
    FH12-24S-0.5S.DEV
    FH12-25S-0.5S.DEV
    FH12-26S-0.5S.DEV
    FH12-28S-0.5S.DEV
    FH12-30S-0.5S.DEV
    FH12-32S-0.5S.DEV
    FH12-33S-0.5S.DEV
    FH12-34S-0.5S.DEV
    FH12-35S-0.5S.DEV
    FH12-36S-0.5S.DEV
    FH12-40S-0.5S.DEV
    FH12-45S-0.5S.DEV
    FH12-50S-0.5S.DEV
    FH12-53S-0.5S.DEV
    FH12-60S-0.5SV.DEV
    FH12-6S-0.5SH.PAC
    FH12-08S-1SH.PAC
    FH12-8S-0.5SH.PAC
    FH12-10S-0.5SH.PAC
    FH12-11S-0.5SH.PAC
    FH12-12S-0.5SH.PAC
    FH12-13S-0.5SH.PAC
    FH12-14S-0.5SH.PAC
    FH12-15S-0.5SH.PAC
    FH12-15S-0.5SV.PAC
    FH12-16S-0.5SH.PAC
    FH12-16S-1SH.PAC
    FH12-16S-1SV.PAC
    FH12-17S-0.5SH.PAC
    FH12-18S-0.5SH.PAC
    FH12-19S-0.5SH.PAC
    FH12-20S-0.5SH.PAC
    FH12-20S-1SV.PAC
    FH12-22S-0.5SH.PAC
    FH12-24S-0.5SH.PAC
    FH12-25S-0.5SH.PAC
    FH12-26S-0.5SH.PAC
    FH12-28S-0.5SH.PAC
    FH12-30S-0.5SH.PAC
    FH12-32S-0.5SH.PAC
    FH12-33S-0.5SH.PAC
    FH12-34S-0.5SH.PAC
    FH12-35S-0.5SH.PAC
    FH12-36S-0.5SH.PAC
    FH12-40S-0.5SH.PAC
    FH12-45S-0.5SH.PAC
    FH12-50S-0.5SH.PAC
    FH12-53S-0.5SH.PAC
    FH12-60S-0.5SV.PAC

2010-05-19
  * maxim.lbr: Eagle 5.9.3
    added:
    DS8500.DEV
    TQFN20-5X5.PAC

2010-05-18
  * led.lbr: Eagle 5.9.2
    added:
    *P4.DEV
    P47F-BOTTOM.PAC
    P47F-TOP.PAC

2010-05-18
  * con-samtec.lbr: Eagle 5.9.2
    added:
    SSW-101-02-S-D.DEV
    SSW-101-02-S-Q.DEV
    SSW-101-02-S-S.DEV
    SSW-101-02-S-T.DEV
    SSW-102-02-S-D.DEV
    SSW-102-02-S-Q.DEV
    SSW-102-02-S-S.DEV
    SSW-102-02-S-T.DEV
    SSW-103-02-S-D.DEV
    SSW-103-02-S-Q.DEV
    SSW-103-02-S-S.DEV
    SSW-103-02-S-T.DEV
    SSW-104-02-S-D.DEV
    SSW-104-02-S-Q.DEV
    SSW-104-02-S-S.DEV
    SSW-104-02-S-T.DEV
    SSW-105-02-S-D.DEV
    SSW-105-02-S-Q.DEV
    SSW-105-02-S-S.DEV
    SSW-105-02-S-T.DEV
    SSW-106-02-S-D.DEV
    SSW-106-02-S-Q.DEV
    SSW-106-02-S-S.DEV
    SSW-106-02-S-T.DEV
    SSW-107-02-S-D.DEV
    SSW-107-02-S-Q.DEV
    SSW-107-02-S-S.DEV
    SSW-107-02-S-T.DEV
    SSW-108-02-S-D.DEV
    SSW-108-02-S-Q.DEV
    SSW-108-02-S-S.DEV
    SSW-108-02-S-T.DEV
    SSW-109-02-S-D.DEV
    SSW-109-02-S-Q.DEV
    SSW-109-02-S-S.DEV
    SSW-109-02-S-T.DEV
    SSW-110-02-S-D.DEV
    SSW-110-02-S-Q.DEV
    SSW-110-02-S-S.DEV
    SSW-110-02-S-T.DEV
    SSW-111-02-S-D.DEV
    SSW-111-02-S-Q.DEV
    SSW-111-02-S-S.DEV
    SSW-111-02-S-T.DEV
    SSW-112-02-S-D.DEV
    SSW-112-02-S-Q.DEV
    SSW-112-02-S-S.DEV
    SSW-112-02-S-T.DEV
    SSW-113-02-S-D.DEV
    SSW-113-02-S-Q.DEV
    SSW-113-02-S-S.DEV
    SSW-113-02-S-T.DEV
    SSW-114-02-S-D.DEV
    SSW-114-02-S-Q.DEV
    SSW-114-02-S-S.DEV
    SSW-114-02-S-T.DEV
    SSW-115-02-S-D.DEV
    SSW-115-02-S-Q.DEV
    SSW-115-02-S-S.DEV
    SSW-115-02-S-T.DEV
    SSW-116-02-S-D.DEV
    SSW-116-02-S-Q.DEV
    SSW-116-02-S-S.DEV
    SSW-116-02-S-T.DEV
    SSW-117-02-S-D.DEV
    SSW-117-02-S-Q.DEV
    SSW-117-02-S-S.DEV
    SSW-117-02-S-T.DEV
    SSW-118-02-S-D.DEV
    SSW-118-02-S-Q.DEV
    SSW-118-02-S-S.DEV
    SSW-118-02-S-T.DEV
    SSW-119-02-S-D.DEV
    SSW-119-02-S-Q.DEV
    SSW-119-02-S-S.DEV
    SSW-119-02-S-T.DEV
    SSW-120-02-S-D.DEV
    SSW-120-02-S-Q.DEV
    SSW-120-02-S-S.DEV
    SSW-120-02-S-T.DEV
    SSW-121-02-S-D.DEV
    SSW-121-02-S-Q.DEV
    SSW-121-02-S-S.DEV
    SSW-121-02-S-T.DEV
    SSW-122-02-S-D.DEV
    SSW-122-02-S-Q.DEV
    SSW-122-02-S-S.DEV
    SSW-122-02-S-T.DEV
    SSW-123-02-S-D.DEV
    SSW-123-02-S-Q.DEV
    SSW-123-02-S-S.DEV
    SSW-123-02-S-T.DEV
    SSW-124-02-S-D.DEV
    SSW-124-02-S-Q.DEV
    SSW-124-02-S-S.DEV
    SSW-124-02-S-T.DEV
    SSW-125-02-S-D.DEV
    SSW-125-02-S-Q.DEV
    SSW-125-02-S-S.DEV
    SSW-125-02-S-T.DEV
    SSW-126-02-S-D.DEV
    SSW-126-02-S-Q.DEV
    SSW-126-02-S-S.DEV
    SSW-126-02-S-T.DEV
    SSW-127-02-S-D.DEV
    SSW-127-02-S-Q.DEV
    SSW-127-02-S-S.DEV
    SSW-127-02-S-T.DEV
    SSW-128-02-S-D.DEV
    SSW-128-02-S-Q.DEV
    SSW-128-02-S-S.DEV
    SSW-128-02-S-T.DEV
    SSW-129-02-S-D.DEV
    SSW-129-02-S-Q.DEV
    SSW-129-02-S-S.DEV
    SSW-129-02-S-T.DEV
    SSW-130-02-S-D.DEV
    SSW-130-02-S-Q.DEV
    SSW-130-02-S-S.DEV
    SSW-130-02-S-T.DEV
    SSW-131-02-S-D.DEV
    SSW-131-02-S-Q.DEV
    SSW-131-02-S-S.DEV
    SSW-131-02-S-T.DEV
    SSW-132-02-S-D.DEV
    SSW-132-02-S-Q.DEV
    SSW-132-02-S-S.DEV
    SSW-132-02-S-T.DEV
    SSW-133-02-S-D.DEV
    SSW-133-02-S-Q.DEV
    SSW-133-02-S-S.DEV
    SSW-133-02-S-T.DEV
    SSW-134-02-S-D.DEV
    SSW-134-02-S-Q.DEV
    SSW-134-02-S-S.DEV
    SSW-134-02-S-T.DEV
    SSW-135-02-S-D.DEV
    SSW-135-02-S-Q.DEV
    SSW-135-02-S-S.DEV
    SSW-135-02-S-T.DEV
    SSW-136-02-S-D.DEV
    SSW-136-02-S-Q.DEV
    SSW-136-02-S-S.DEV
    SSW-136-02-S-T.DEV
    SSW-137-02-S-D.DEV
    SSW-137-02-S-Q.DEV
    SSW-137-02-S-S.DEV
    SSW-137-02-S-T.DEV
    SSW-138-02-S-D.DEV
    SSW-138-02-S-Q.DEV
    SSW-138-02-S-S.DEV
    SSW-138-02-S-T.DEV
    SSW-139-02-S-D.DEV
    SSW-139-02-S-Q.DEV
    SSW-139-02-S-S.DEV
    SSW-139-02-S-T.DEV
    SSW-140-02-S-D.DEV
    SSW-140-02-S-Q.DEV
    SSW-140-02-S-S.DEV
    SSW-140-02-S-T.DEV
    SSW-141-02-S-D.DEV
    SSW-141-02-S-Q.DEV
    SSW-141-02-S-S.DEV
    SSW-141-02-S-T.DEV
    SSW-142-02-S-D.DEV
    SSW-142-02-S-Q.DEV
    SSW-142-02-S-S.DEV
    SSW-142-02-S-T.DEV
    SSW-143-02-S-D.DEV
    SSW-143-02-S-Q.DEV
    SSW-143-02-S-S.DEV
    SSW-143-02-S-T.DEV
    SSW-144-02-S-D.DEV
    SSW-144-02-S-Q.DEV
    SSW-144-02-S-S.DEV
    SSW-144-02-S-T.DEV
    SSW-145-02-S-D.DEV
    SSW-145-02-S-Q.DEV
    SSW-145-02-S-S.DEV
    SSW-145-02-S-T.DEV
    SSW-146-02-S-D.DEV
    SSW-146-02-S-Q.DEV
    SSW-146-02-S-S.DEV
    SSW-146-02-S-T.DEV
    SSW-147-02-S-D.DEV
    SSW-147-02-S-Q.DEV
    SSW-147-02-S-S.DEV
    SSW-147-02-S-T.DEV
    SSW-148-02-S-D.DEV
    SSW-148-02-S-Q.DEV
    SSW-148-02-S-S.DEV
    SSW-148-02-S-T.DEV
    SSW-149-02-S-D.DEV
    SSW-149-02-S-Q.DEV
    SSW-149-02-S-S.DEV
    SSW-149-02-S-T.DEV
    SSW-150-02-S-D.DEV
    SSW-150-02-S-Q.DEV
    SSW-150-02-S-S.DEV
    SSW-150-02-S-T.DEV
    TSW-101-02-S-D.DEV
    TSW-101-02-S-Q.DEV
    TSW-101-02-S-S.DEV
    TSW-102-02-S-D.DEV
    TSW-102-02-S-Q.DEV
    TSW-102-02-S-S.DEV
    TSW-103-02-S-D.DEV
    TSW-103-02-S-Q.DEV
    TSW-103-02-S-S.DEV
    TSW-104-02-S-D.DEV
    TSW-104-02-S-Q.DEV
    TSW-104-02-S-S.DEV
    TSW-105-02-S-D.DEV
    TSW-105-02-S-Q.DEV
    TSW-105-02-S-S.DEV
    TSW-106-02-S-D.DEV
    TSW-106-02-S-Q.DEV
    TSW-106-02-S-S.DEV
    TSW-107-02-S-D.DEV
    TSW-107-02-S-Q.DEV
    TSW-107-02-S-S.DEV
    TSW-108-02-S-D.DEV
    TSW-108-02-S-Q.DEV
    TSW-108-02-S-S.DEV
    TSW-109-02-S-D.DEV
    TSW-109-02-S-Q.DEV
    TSW-109-02-S-S.DEV
    TSW-110-02-S-D.DEV
    TSW-110-02-S-Q.DEV
    TSW-110-02-S-S.DEV
    TSW-111-02-S-D.DEV
    TSW-111-02-S-Q.DEV
    TSW-111-02-S-S.DEV
    TSW-112-02-S-D.DEV
    TSW-112-02-S-Q.DEV
    TSW-112-02-S-S.DEV
    TSW-113-02-S-D.DEV
    TSW-113-02-S-Q.DEV
    TSW-113-02-S-S.DEV
    TSW-114-02-S-D.DEV
    TSW-114-02-S-Q.DEV
    TSW-114-02-S-S.DEV
    TSW-115-02-S-D.DEV
    TSW-115-02-S-Q.DEV
    TSW-115-02-S-S.DEV
    TSW-116-02-S-D.DEV
    TSW-116-02-S-Q.DEV
    TSW-116-02-S-S.DEV
    TSW-117-02-S-D.DEV
    TSW-117-02-S-Q.DEV
    TSW-117-02-S-S.DEV
    TSW-118-02-S-D.DEV
    TSW-118-02-S-Q.DEV
    TSW-118-02-S-S.DEV
    TSW-119-02-S-D.DEV
    TSW-119-02-S-Q.DEV
    TSW-119-02-S-S.DEV
    TSW-120-02-S-D.DEV
    TSW-120-02-S-Q.DEV
    TSW-120-02-S-S.DEV
    TSW-121-02-S-D.DEV
    TSW-121-02-S-Q.DEV
    TSW-121-02-S-S.DEV
    TSW-122-02-S-D.DEV
    TSW-122-02-S-Q.DEV
    TSW-122-02-S-S.DEV
    TSW-123-02-S-D.DEV
    TSW-123-02-S-Q.DEV
    TSW-123-02-S-S.DEV
    TSW-124-02-S-D.DEV
    TSW-124-02-S-Q.DEV
    TSW-124-02-S-S.DEV
    TSW-125-02-S-D.DEV
    TSW-125-02-S-Q.DEV
    TSW-125-02-S-S.DEV
    TSW-126-02-S-D.DEV
    TSW-126-02-S-Q.DEV
    TSW-126-02-S-S.DEV
    TSW-127-02-S-D.DEV
    TSW-127-02-S-Q.DEV
    TSW-127-02-S-S.DEV
    TSW-128-02-S-D.DEV
    TSW-128-02-S-Q.DEV
    TSW-128-02-S-S.DEV
    TSW-129-02-S-D.DEV
    TSW-129-02-S-Q.DEV
    TSW-129-02-S-S.DEV
    TSW-130-02-S-D.DEV
    TSW-130-02-S-Q.DEV
    TSW-130-02-S-S.DEV
    TSW-131-02-S-D.DEV
    TSW-131-02-S-Q.DEV
    TSW-131-02-S-S.DEV
    TSW-132-02-S-D.DEV
    TSW-132-02-S-Q.DEV
    TSW-132-02-S-S.DEV
    TSW-133-02-S-D.DEV
    TSW-133-02-S-Q.DEV
    TSW-133-02-S-S.DEV
    TSW-134-02-S-D.DEV
    TSW-134-02-S-Q.DEV
    TSW-134-02-S-S.DEV
    TSW-135-02-S-D.DEV
    TSW-135-02-S-Q.DEV
    TSW-135-02-S-S.DEV
    TSW-136-02-S-D.DEV
    TSW-136-02-S-Q.DEV
    TSW-136-02-S-S.DEV
    TSW-137-02-S-D.DEV
    TSW-137-02-S-Q.DEV
    TSW-137-02-S-S.DEV
    TSW-138-02-S-D.DEV
    TSW-138-02-S-Q.DEV
    TSW-138-02-S-S.DEV
    TSW-139-02-S-D.DEV
    TSW-139-02-S-Q.DEV
    TSW-139-02-S-S.DEV
    TSW-140-02-S-D.DEV
    TSW-140-02-S-Q.DEV
    TSW-140-02-S-S.DEV
    TSW-141-02-S-D.DEV
    TSW-141-02-S-Q.DEV
    TSW-141-02-S-S.DEV
    TSW-142-02-S-D.DEV
    TSW-142-02-S-Q.DEV
    TSW-142-02-S-S.DEV
    TSW-143-02-S-D.DEV
    TSW-143-02-S-Q.DEV
    TSW-143-02-S-S.DEV
    TSW-144-02-S-D.DEV
    TSW-144-02-S-Q.DEV
    TSW-144-02-S-S.DEV
    TSW-145-02-S-D.DEV
    TSW-145-02-S-Q.DEV
    TSW-145-02-S-S.DEV
    TSW-146-02-S-D.DEV
    TSW-146-02-S-Q.DEV
    TSW-146-02-S-S.DEV
    TSW-147-02-S-D.DEV
    TSW-147-02-S-Q.DEV
    TSW-147-02-S-S.DEV
    TSW-148-02-S-D.DEV
    TSW-148-02-S-Q.DEV
    TSW-148-02-S-S.DEV
    TSW-149-02-S-D.DEV
    TSW-149-02-S-Q.DEV
    TSW-149-02-S-S.DEV
    TSW-150-02-S-D.DEV
    TSW-150-02-S-Q.DEV
    TSW-150-02-S-S.DEV
    TSW-150-02-S-T.DEV
    SSW-101-02-S-D.PAC
    SSW-101-02-S-D-RA.PAC
    SSW-101-02-S-Q.PAC
    SSW-101-02-S-Q-RA.PAC
    SSW-101-02-S-S.PAC
    SSW-101-02-S-S-RA.PAC
    SSW-101-02-S-T.PAC
    SSW-101-02-S-T-RA.PAC
    SSW-102-02-S-D.PAC
    SSW-102-02-S-D-RA.PAC
    SSW-102-02-S-Q.PAC
    SSW-102-02-S-Q-RA.PAC
    SSW-102-02-S-S.PAC
    SSW-102-02-S-S-RA.PAC
    SSW-102-02-S-T.PAC
    SSW-102-02-S-T-RA.PAC
    SSW-103-02-S-D.PAC
    SSW-103-02-S-D-RA.PAC
    SSW-103-02-S-Q.PAC
    SSW-103-02-S-Q-RA.PAC
    SSW-103-02-S-S.PAC
    SSW-103-02-S-S-RA.PAC
    SSW-103-02-S-T.PAC
    SSW-103-02-S-T-RA.PAC
    SSW-104-02-S-D.PAC
    SSW-104-02-S-D-RA.PAC
    SSW-104-02-S-Q.PAC
    SSW-104-02-S-Q-RA.PAC
    SSW-104-02-S-S.PAC
    SSW-104-02-S-S-RA.PAC
    SSW-104-02-S-T.PAC
    SSW-104-02-S-T-RA.PAC
    SSW-105-02-S-D.PAC
    SSW-105-02-S-D-RA.PAC
    SSW-105-02-S-Q.PAC
    SSW-105-02-S-Q-RA.PAC
    SSW-105-02-S-S.PAC
    SSW-105-02-S-S-RA.PAC
    SSW-105-02-S-T.PAC
    SSW-105-02-S-T-RA.PAC
    SSW-106-02-S-D.PAC
    SSW-106-02-S-D-RA.PAC
    SSW-106-02-S-Q.PAC
    SSW-106-02-S-Q-RA.PAC
    SSW-106-02-S-S.PAC
    SSW-106-02-S-S-RA.PAC
    SSW-106-02-S-T.PAC
    SSW-106-02-S-T-RA.PAC
    SSW-107-02-S-D.PAC
    SSW-107-02-S-D-RA.PAC
    SSW-107-02-S-Q.PAC
    SSW-107-02-S-Q-RA.PAC
    SSW-107-02-S-S.PAC
    SSW-107-02-S-S-RA.PAC
    SSW-107-02-S-T.PAC
    SSW-107-02-S-T-RA.PAC
    SSW-108-02-S-D.PAC
    SSW-108-02-S-D-RA.PAC
    SSW-108-02-S-Q.PAC
    SSW-108-02-S-Q-RA.PAC
    SSW-108-02-S-S.PAC
    SSW-108-02-S-S-RA.PAC
    SSW-108-02-S-T.PAC
    SSW-108-02-S-T-RA.PAC
    SSW-109-02-S-D.PAC
    SSW-109-02-S-D-RA.PAC
    SSW-109-02-S-Q.PAC
    SSW-109-02-S-Q-RA.PAC
    SSW-109-02-S-S.PAC
    SSW-109-02-S-S-RA.PAC
    SSW-109-02-S-T.PAC
    SSW-109-02-S-T-RA.PAC
    SSW-110-02-S-D.PAC
    SSW-110-02-S-D-RA.PAC
    SSW-110-02-S-Q.PAC
    SSW-110-02-S-Q-RA.PAC
    SSW-110-02-S-S.PAC
    SSW-110-02-S-S-RA.PAC
    SSW-110-02-S-T.PAC
    SSW-110-02-S-T-RA.PAC
    SSW-111-02-S-D.PAC
    SSW-111-02-S-D-RA.PAC
    SSW-111-02-S-Q.PAC
    SSW-111-02-S-Q-RA.PAC
    SSW-111-02-S-S.PAC
    SSW-111-02-S-S-RA.PAC
    SSW-111-02-S-T.PAC
    SSW-111-02-S-T-RA.PAC
    SSW-112-02-S-D.PAC
    SSW-112-02-S-D-RA.PAC
    SSW-112-02-S-Q.PAC
    SSW-112-02-S-Q-RA.PAC
    SSW-112-02-S-S.PAC
    SSW-112-02-S-S-RA.PAC
    SSW-112-02-S-T.PAC
    SSW-112-02-S-T-RA.PAC
    SSW-113-02-S-D.PAC
    SSW-113-02-S-D-RA.PAC
    SSW-113-02-S-Q.PAC
    SSW-113-02-S-Q-RA.PAC
    SSW-113-02-S-S.PAC
    SSW-113-02-S-S-RA.PAC
    SSW-113-02-S-T.PAC
    SSW-113-02-S-T-RA.PAC
    SSW-114-02-S-D.PAC
    SSW-114-02-S-D-RA.PAC
    SSW-114-02-S-Q.PAC
    SSW-114-02-S-Q-RA.PAC
    SSW-114-02-S-S.PAC
    SSW-114-02-S-S-RA.PAC
    SSW-114-02-S-T.PAC
    SSW-114-02-S-T-RA.PAC
    SSW-115-02-S-D.PAC
    SSW-115-02-S-D-RA.PAC
    SSW-115-02-S-Q.PAC
    SSW-115-02-S-Q-RA.PAC
    SSW-115-02-S-S.PAC
    SSW-115-02-S-S-RA.PAC
    SSW-115-02-S-T.PAC
    SSW-115-02-S-T-RA.PAC
    SSW-116-02-S-D.PAC
    SSW-116-02-S-D-RA.PAC
    SSW-116-02-S-Q.PAC
    SSW-116-02-S-Q-RA.PAC
    SSW-116-02-S-S.PAC
    SSW-116-02-S-S-RA.PAC
    SSW-116-02-S-T.PAC
    SSW-116-02-S-T-RA.PAC
    SSW-117-02-S-D.PAC
    SSW-117-02-S-D-RA.PAC
    SSW-117-02-S-Q.PAC
    SSW-117-02-S-Q-RA.PAC
    SSW-117-02-S-S.PAC
    SSW-117-02-S-S-RA.PAC
    SSW-117-02-S-T.PAC
    SSW-117-02-S-T-RA.PAC
    SSW-118-02-S-D.PAC
    SSW-118-02-S-D-RA.PAC
    SSW-118-02-S-Q.PAC
    SSW-118-02-S-Q-RA.PAC
    SSW-118-02-S-S.PAC
    SSW-118-02-S-S-RA.PAC
    SSW-118-02-S-T.PAC
    SSW-118-02-S-T-RA.PAC
    SSW-119-02-S-D.PAC
    SSW-119-02-S-D-RA.PAC
    SSW-119-02-S-Q.PAC
    SSW-119-02-S-Q-RA.PAC
    SSW-119-02-S-S.PAC
    SSW-119-02-S-S-RA.PAC
    SSW-119-02-S-T.PAC
    SSW-119-02-S-T-RA.PAC
    SSW-120-02-S-D.PAC
    SSW-120-02-S-D-RA.PAC
    SSW-120-02-S-Q.PAC
    SSW-120-02-S-Q-RA.PAC
    SSW-120-02-S-S.PAC
    SSW-120-02-S-S-RA.PAC
    SSW-120-02-S-T.PAC
    SSW-120-02-S-T-RA.PAC
    SSW-121-02-S-D.PAC
    SSW-121-02-S-D-RA.PAC
    SSW-121-02-S-Q.PAC
    SSW-121-02-S-Q-RA.PAC
    SSW-121-02-S-S.PAC
    SSW-121-02-S-S-RA.PAC
    SSW-121-02-S-T.PAC
    SSW-121-02-S-T-RA.PAC
    SSW-122-02-S-D.PAC
    SSW-122-02-S-D-RA.PAC
    SSW-122-02-S-Q.PAC
    SSW-122-02-S-Q-RA.PAC
    SSW-122-02-S-S.PAC
    SSW-122-02-S-S-RA.PAC
    SSW-122-02-S-T.PAC
    SSW-122-02-S-T-RA.PAC
    SSW-123-02-S-D.PAC
    SSW-123-02-S-D-RA.PAC
    SSW-123-02-S-Q.PAC
    SSW-123-02-S-Q-RA.PAC
    SSW-123-02-S-S.PAC
    SSW-123-02-S-S-RA.PAC
    SSW-123-02-S-T.PAC
    SSW-123-02-S-T-RA.PAC
    SSW-124-02-S-D.PAC
    SSW-124-02-S-D-RA.PAC
    SSW-124-02-S-Q.PAC
    SSW-124-02-S-Q-RA.PAC
    SSW-124-02-S-S.PAC
    SSW-124-02-S-S-RA.PAC
    SSW-124-02-S-T.PAC
    SSW-124-02-S-T-RA.PAC
    SSW-125-02-S-D.PAC
    SSW-125-02-S-D-RA.PAC
    SSW-125-02-S-Q.PAC
    SSW-125-02-S-Q-RA.PAC
    SSW-125-02-S-S.PAC
    SSW-125-02-S-S-RA.PAC
    SSW-125-02-S-T.PAC
    SSW-125-02-S-T-RA.PAC
    SSW-126-02-S-D.PAC
    SSW-126-02-S-D-RA.PAC
    SSW-126-02-S-Q.PAC
    SSW-126-02-S-Q-RA.PAC
    SSW-126-02-S-S.PAC
    SSW-126-02-S-S-RA.PAC
    SSW-126-02-S-T.PAC
    SSW-126-02-S-T-RA.PAC
    SSW-127-02-S-D.PAC
    SSW-127-02-S-D-RA.PAC
    SSW-127-02-S-Q.PAC
    SSW-127-02-S-Q-RA.PAC
    SSW-127-02-S-S.PAC
    SSW-127-02-S-S-RA.PAC
    SSW-127-02-S-T.PAC
    SSW-127-02-S-T-RA.PAC
    SSW-128-02-S-D.PAC
    SSW-128-02-S-D-RA.PAC
    SSW-128-02-S-Q.PAC
    SSW-128-02-S-Q-RA.PAC
    SSW-128-02-S-S.PAC
    SSW-128-02-S-S-RA.PAC
    SSW-128-02-S-T.PAC
    SSW-128-02-S-T-RA.PAC
    SSW-129-02-S-D.PAC
    SSW-129-02-S-D-RA.PAC
    SSW-129-02-S-Q.PAC
    SSW-129-02-S-Q-RA.PAC
    SSW-129-02-S-S.PAC
    SSW-129-02-S-S-RA.PAC
    SSW-129-02-S-T.PAC
    SSW-129-02-S-T-RA.PAC
    SSW-130-02-S-D.PAC
    SSW-130-02-S-D-RA.PAC
    SSW-130-02-S-Q.PAC
    SSW-130-02-S-Q-RA.PAC
    SSW-130-02-S-S.PAC
    SSW-130-02-S-S-RA.PAC
    SSW-130-02-S-T.PAC
    SSW-130-02-S-T-RA.PAC
    SSW-131-02-S-D.PAC
    SSW-131-02-S-D-RA.PAC
    SSW-131-02-S-Q.PAC
    SSW-131-02-S-Q-RA.PAC
    SSW-131-02-S-S.PAC
    SSW-131-02-S-S-RA.PAC
    SSW-131-02-S-T.PAC
    SSW-131-02-S-T-RA.PAC
    SSW-132-02-S-D.PAC
    SSW-132-02-S-D-RA.PAC
    SSW-132-02-S-Q.PAC
    SSW-132-02-S-Q-RA.PAC
    SSW-132-02-S-S.PAC
    SSW-132-02-S-S-RA.PAC
    SSW-132-02-S-T.PAC
    SSW-132-02-S-T-RA.PAC
    SSW-133-02-S-D.PAC
    SSW-133-02-S-D-RA.PAC
    SSW-133-02-S-Q.PAC
    SSW-133-02-S-Q-RA.PAC
    SSW-133-02-S-S.PAC
    SSW-133-02-S-S-RA.PAC
    SSW-133-02-S-T.PAC
    SSW-133-02-S-T-RA.PAC
    SSW-134-02-S-D.PAC
    SSW-134-02-S-D-RA.PAC
    SSW-134-02-S-Q.PAC
    SSW-134-02-S-Q-RA.PAC
    SSW-134-02-S-S.PAC
    SSW-134-02-S-S-RA.PAC
    SSW-134-02-S-T.PAC
    SSW-134-02-S-T-RA.PAC
    SSW-135-02-S-D.PAC
    SSW-135-02-S-D-RA.PAC
    SSW-135-02-S-Q.PAC
    SSW-135-02-S-Q-RA.PAC
    SSW-135-02-S-S.PAC
    SSW-135-02-S-S-RA.PAC
    SSW-135-02-S-T.PAC
    SSW-135-02-S-T-RA.PAC
    SSW-136-02-S-D.PAC
    SSW-136-02-S-D-RA.PAC
    SSW-136-02-S-Q.PAC
    SSW-136-02-S-Q-RA.PAC
    SSW-136-02-S-S.PAC
    SSW-136-02-S-S-RA.PAC
    SSW-136-02-S-T.PAC
    SSW-136-02-S-T-RA.PAC
    SSW-137-02-S-D.PAC
    SSW-137-02-S-D-RA.PAC
    SSW-137-02-S-Q.PAC
    SSW-137-02-S-Q-RA.PAC
    SSW-137-02-S-S.PAC
    SSW-137-02-S-S-RA.PAC
    SSW-137-02-S-T.PAC
    SSW-137-02-S-T-RA.PAC
    SSW-138-02-S-D.PAC
    SSW-138-02-S-D-RA.PAC
    SSW-138-02-S-Q.PAC
    SSW-138-02-S-Q-RA.PAC
    SSW-138-02-S-S.PAC
    SSW-138-02-S-S-RA.PAC
    SSW-138-02-S-T.PAC
    SSW-138-02-S-T-RA.PAC
    SSW-139-02-S-D.PAC
    SSW-139-02-S-D-RA.PAC
    SSW-139-02-S-Q.PAC
    SSW-139-02-S-Q-RA.PAC
    SSW-139-02-S-S.PAC
    SSW-139-02-S-S-RA.PAC
    SSW-139-02-S-T.PAC
    SSW-139-02-S-T-RA.PAC
    SSW-140-02-S-D.PAC
    SSW-140-02-S-D-RA.PAC
    SSW-140-02-S-Q.PAC
    SSW-140-02-S-Q-RA.PAC
    SSW-140-02-S-S.PAC
    SSW-140-02-S-S-RA.PAC
    SSW-140-02-S-T.PAC
    SSW-140-02-S-T-RA.PAC
    SSW-141-02-S-D.PAC
    SSW-141-02-S-D-RA.PAC
    SSW-141-02-S-Q.PAC
    SSW-141-02-S-Q-RA.PAC
    SSW-141-02-S-S.PAC
    SSW-141-02-S-S-RA.PAC
    SSW-141-02-S-T.PAC
    SSW-141-02-S-T-RA.PAC
    SSW-142-02-S-D.PAC
    SSW-142-02-S-D-RA.PAC
    SSW-142-02-S-Q.PAC
    SSW-142-02-S-Q-RA.PAC
    SSW-142-02-S-S.PAC
    SSW-142-02-S-S-RA.PAC
    SSW-142-02-S-T.PAC
    SSW-142-02-S-T-RA.PAC
    SSW-143-02-S-D.PAC
    SSW-143-02-S-D-RA.PAC
    SSW-143-02-S-Q.PAC
    SSW-143-02-S-Q-RA.PAC
    SSW-143-02-S-S.PAC
    SSW-143-02-S-S-RA.PAC
    SSW-143-02-S-T.PAC
    SSW-143-02-S-T-RA.PAC
    SSW-144-02-S-D.PAC
    SSW-144-02-S-D-RA.PAC
    SSW-144-02-S-Q.PAC
    SSW-144-02-S-Q-RA.PAC
    SSW-144-02-S-S.PAC
    SSW-144-02-S-S-RA.PAC
    SSW-144-02-S-T.PAC
    SSW-144-02-S-T-RA.PAC
    SSW-145-02-S-D.PAC
    SSW-145-02-S-D-RA.PAC
    SSW-145-02-S-Q.PAC
    SSW-145-02-S-Q-RA.PAC
    SSW-145-02-S-S.PAC
    SSW-145-02-S-S-RA.PAC
    SSW-145-02-S-T.PAC
    SSW-145-02-S-T-RA.PAC
    SSW-146-02-S-D.PAC
    SSW-146-02-S-D-RA.PAC
    SSW-146-02-S-Q.PAC
    SSW-146-02-S-Q-RA.PAC
    SSW-146-02-S-S.PAC
    SSW-146-02-S-S-RA.PAC
    SSW-146-02-S-T.PAC
    SSW-146-02-S-T-RA.PAC
    SSW-147-02-S-D.PAC
    SSW-147-02-S-D-RA.PAC
    SSW-147-02-S-Q.PAC
    SSW-147-02-S-Q-RA.PAC
    SSW-147-02-S-S.PAC
    SSW-147-02-S-S-RA.PAC
    SSW-147-02-S-T.PAC
    SSW-147-02-S-T-RA.PAC
    SSW-148-02-S-D.PAC
    SSW-148-02-S-D-RA.PAC
    SSW-148-02-S-Q.PAC
    SSW-148-02-S-Q-RA.PAC
    SSW-148-02-S-S.PAC
    SSW-148-02-S-S-RA.PAC
    SSW-148-02-S-T.PAC
    SSW-148-02-S-T-RA.PAC
    SSW-149-02-S-D.PAC
    SSW-149-02-S-D-RA.PAC
    SSW-149-02-S-Q.PAC
    SSW-149-02-S-Q-RA.PAC
    SSW-149-02-S-S.PAC
    SSW-149-02-S-S-RA.PAC
    SSW-149-02-S-T.PAC
    SSW-149-02-S-T-RA.PAC
    SSW-150-02-S-D.PAC
    SSW-150-02-S-D-RA.PAC
    SSW-150-02-S-Q.PAC
    SSW-150-02-S-Q-RA.PAC
    SSW-150-02-S-S.PAC
    SSW-150-02-S-S-RA.PAC
    SSW-150-02-S-T.PAC
    SSW-150-02-S-T-RA.PAC
    TSW-101-02-S-D.PAC
    TSW-101-02-S-D-RA.PAC
    TSW-101-02-S-Q.PAC
    TSW-101-02-S-Q-RA.PAC
    TSW-101-02-S-S.PAC
    TSW-101-02-S-S-RA.PAC
    TSW-101-02-S-T.PAC
    TSW-101-02-S-T-RA.PAC
    TSW-102-02-S-D.PAC
    TSW-102-02-S-D-RA.PAC
    TSW-102-02-S-Q.PAC
    TSW-102-02-S-Q-RA.PAC
    TSW-102-02-S-S.PAC
    TSW-102-02-S-S-RA.PAC
    TSW-102-02-S-T.PAC
    TSW-102-02-S-T-RA.PAC
    TSW-103-02-S-D.PAC
    TSW-103-02-S-D-RA.PAC
    TSW-103-02-S-Q.PAC
    TSW-103-02-S-Q-RA.PAC
    TSW-103-02-S-S.PAC
    TSW-103-02-S-S-RA.PAC
    TSW-103-02-S-T.PAC
    TSW-103-02-S-T-RA.PAC
    TSW-104-02-S-D.PAC
    TSW-104-02-S-D-RA.PAC
    TSW-104-02-S-Q.PAC
    TSW-104-02-S-Q-RA.PAC
    TSW-104-02-S-S.PAC
    TSW-104-02-S-S-RA.PAC
    TSW-104-02-S-T.PAC
    TSW-104-02-S-T-RA.PAC
    TSW-105-02-S-D.PAC
    TSW-105-02-S-D-RA.PAC
    TSW-105-02-S-Q.PAC
    TSW-105-02-S-Q-RA.PAC
    TSW-105-02-S-S.PAC
    TSW-105-02-S-S-RA.PAC
    TSW-105-02-S-T.PAC
    TSW-105-02-S-T-RA.PAC
    TSW-106-02-S-D.PAC
    TSW-106-02-S-D-RA.PAC
    TSW-106-02-S-Q.PAC
    TSW-106-02-S-Q-RA.PAC
    TSW-106-02-S-S.PAC
    TSW-106-02-S-S-RA.PAC
    TSW-106-02-S-T.PAC
    TSW-106-02-S-T-RA.PAC
    TSW-107-02-S-D.PAC
    TSW-107-02-S-D-RA.PAC
    TSW-107-02-S-Q.PAC
    TSW-107-02-S-Q-RA.PAC
    TSW-107-02-S-S.PAC
    TSW-107-02-S-S-RA.PAC
    TSW-107-02-S-T.PAC
    TSW-107-02-S-T-RA.PAC
    TSW-108-02-S-D.PAC
    TSW-108-02-S-D-RA.PAC
    TSW-108-02-S-Q.PAC
    TSW-108-02-S-Q-RA.PAC
    TSW-108-02-S-S.PAC
    TSW-108-02-S-S-RA.PAC
    TSW-108-02-S-T.PAC
    TSW-108-02-S-T-RA.PAC
    TSW-109-02-S-D.PAC
    TSW-109-02-S-D-RA.PAC
    TSW-109-02-S-Q.PAC
    TSW-109-02-S-Q-RA.PAC
    TSW-109-02-S-S.PAC
    TSW-109-02-S-S-RA.PAC
    TSW-109-02-S-T.PAC
    TSW-109-02-S-T-RA.PAC
    TSW-110-02-S-D.PAC
    TSW-110-02-S-D-RA.PAC
    TSW-110-02-S-Q.PAC
    TSW-110-02-S-Q-RA.PAC
    TSW-110-02-S-S.PAC
    TSW-110-02-S-S-RA.PAC
    TSW-110-02-S-T.PAC
    TSW-110-02-S-T-RA.PAC
    TSW-111-02-S-D.PAC
    TSW-111-02-S-D-RA.PAC
    TSW-111-02-S-Q.PAC
    TSW-111-02-S-Q-RA.PAC
    TSW-111-02-S-S.PAC
    TSW-111-02-S-S-RA.PAC
    TSW-111-02-S-T.PAC
    TSW-111-02-S-T-RA.PAC
    TSW-112-02-S-D.PAC
    TSW-112-02-S-D-RA.PAC
    TSW-112-02-S-Q.PAC
    TSW-112-02-S-Q-RA.PAC
    TSW-112-02-S-S.PAC
    TSW-112-02-S-S-RA.PAC
    TSW-112-02-S-T.PAC
    TSW-112-02-S-T-RA.PAC
    TSW-113-02-S-D.PAC
    TSW-113-02-S-D-RA.PAC
    TSW-113-02-S-Q.PAC
    TSW-113-02-S-Q-RA.PAC
    TSW-113-02-S-S.PAC
    TSW-113-02-S-S-RA.PAC
    TSW-113-02-S-T.PAC
    TSW-113-02-S-T-RA.PAC
    TSW-114-02-S-D.PAC
    TSW-114-02-S-D-RA.PAC
    TSW-114-02-S-Q.PAC
    TSW-114-02-S-Q-RA.PAC
    TSW-114-02-S-S.PAC
    TSW-114-02-S-S-RA.PAC
    TSW-114-02-S-T.PAC
    TSW-114-02-S-T-RA.PAC
    TSW-115-02-S-D.PAC
    TSW-115-02-S-D-RA.PAC
    TSW-115-02-S-Q.PAC
    TSW-115-02-S-Q-RA.PAC
    TSW-115-02-S-S.PAC
    TSW-115-02-S-S-RA.PAC
    TSW-115-02-S-T.PAC
    TSW-115-02-S-T-RA.PAC
    TSW-116-02-S-D.PAC
    TSW-116-02-S-D-RA.PAC
    TSW-116-02-S-Q.PAC
    TSW-116-02-S-Q-RA.PAC
    TSW-116-02-S-S.PAC
    TSW-116-02-S-S-RA.PAC
    TSW-116-02-S-T.PAC
    TSW-116-02-S-T-RA.PAC
    TSW-117-02-S-D.PAC
    TSW-117-02-S-D-RA.PAC
    TSW-117-02-S-Q.PAC
    TSW-117-02-S-Q-RA.PAC
    TSW-117-02-S-S.PAC
    TSW-117-02-S-S-RA.PAC
    TSW-117-02-S-T.PAC
    TSW-117-02-S-T-RA.PAC
    TSW-118-02-S-D.PAC
    TSW-118-02-S-D-RA.PAC
    TSW-118-02-S-Q.PAC
    TSW-118-02-S-Q-RA.PAC
    TSW-118-02-S-S.PAC
    TSW-118-02-S-S-RA.PAC
    TSW-118-02-S-T.PAC
    TSW-118-02-S-T-RA.PAC
    TSW-119-02-S-D.PAC
    TSW-119-02-S-D-RA.PAC
    TSW-119-02-S-Q.PAC
    TSW-119-02-S-Q-RA.PAC
    TSW-119-02-S-S.PAC
    TSW-119-02-S-S-RA.PAC
    TSW-119-02-S-T.PAC
    TSW-119-02-S-T-RA.PAC
    TSW-120-02-S-D.PAC
    TSW-120-02-S-D-RA.PAC
    TSW-120-02-S-Q.PAC
    TSW-120-02-S-Q-RA.PAC
    TSW-120-02-S-S.PAC
    TSW-120-02-S-S-RA.PAC
    TSW-120-02-S-T.PAC
    TSW-120-02-S-T-RA.PAC
    TSW-121-02-S-D.PAC
    TSW-121-02-S-D-RA.PAC
    TSW-121-02-S-Q.PAC
    TSW-121-02-S-Q-RA.PAC
    TSW-121-02-S-S.PAC
    TSW-121-02-S-S-RA.PAC
    TSW-121-02-S-T.PAC
    TSW-121-02-S-T-RA.PAC
    TSW-122-02-S-D.PAC
    TSW-122-02-S-D-RA.PAC
    TSW-122-02-S-Q.PAC
    TSW-122-02-S-Q-RA.PAC
    TSW-122-02-S-S.PAC
    TSW-122-02-S-S-RA.PAC
    TSW-122-02-S-T.PAC
    TSW-122-02-S-T-RA.PAC
    TSW-123-02-S-D.PAC
    TSW-123-02-S-D-RA.PAC
    TSW-123-02-S-Q.PAC
    TSW-123-02-S-Q-RA.PAC
    TSW-123-02-S-S.PAC
    TSW-123-02-S-S-RA.PAC
    TSW-123-02-S-T.PAC
    TSW-123-02-S-T-RA.PAC
    TSW-124-02-S-D.PAC
    TSW-124-02-S-D-RA.PAC
    TSW-124-02-S-Q.PAC
    TSW-124-02-S-Q-RA.PAC
    TSW-124-02-S-S.PAC
    TSW-124-02-S-S-RA.PAC
    TSW-124-02-S-T.PAC
    TSW-124-02-S-T-RA.PAC
    TSW-125-02-S-D.PAC
    TSW-125-02-S-D-RA.PAC
    TSW-125-02-S-Q.PAC
    TSW-125-02-S-Q-RA.PAC
    TSW-125-02-S-S.PAC
    TSW-125-02-S-S-RA.PAC
    TSW-125-02-S-T.PAC
    TSW-125-02-S-T-RA.PAC
    TSW-126-02-S-D.PAC
    TSW-126-02-S-D-RA.PAC
    TSW-126-02-S-Q.PAC
    TSW-126-02-S-Q-RA.PAC
    TSW-126-02-S-S.PAC
    TSW-126-02-S-S-RA.PAC
    TSW-126-02-S-T.PAC
    TSW-126-02-S-T-RA.PAC
    TSW-127-02-S-D.PAC
    TSW-127-02-S-D-RA.PAC
    TSW-127-02-S-Q.PAC
    TSW-127-02-S-Q-RA.PAC
    TSW-127-02-S-S.PAC
    TSW-127-02-S-S-RA.PAC
    TSW-127-02-S-T.PAC
    TSW-127-02-S-T-RA.PAC
    TSW-128-02-S-D.PAC
    TSW-128-02-S-D-RA.PAC
    TSW-128-02-S-Q.PAC
    TSW-128-02-S-Q-RA.PAC
    TSW-128-02-S-S.PAC
    TSW-128-02-S-S-RA.PAC
    TSW-128-02-S-T.PAC
    TSW-128-02-S-T-RA.PAC
    TSW-129-02-S-D.PAC
    TSW-129-02-S-D-RA.PAC
    TSW-129-02-S-Q.PAC
    TSW-129-02-S-Q-RA.PAC
    TSW-129-02-S-S.PAC
    TSW-129-02-S-S-RA.PAC
    TSW-129-02-S-T.PAC
    TSW-129-02-S-T-RA.PAC
    TSW-130-02-S-D.PAC
    TSW-130-02-S-D-RA.PAC
    TSW-130-02-S-Q.PAC
    TSW-130-02-S-Q-RA.PAC
    TSW-130-02-S-S.PAC
    TSW-130-02-S-S-RA.PAC
    TSW-130-02-S-T.PAC
    TSW-130-02-S-T-RA.PAC
    TSW-131-02-S-D.PAC
    TSW-131-02-S-D-RA.PAC
    TSW-131-02-S-Q.PAC
    TSW-131-02-S-Q-RA.PAC
    TSW-131-02-S-S.PAC
    TSW-131-02-S-S-RA.PAC
    TSW-131-02-S-T.PAC
    TSW-131-02-S-T-RA.PAC
    TSW-132-02-S-D.PAC
    TSW-132-02-S-D-RA.PAC
    TSW-132-02-S-Q.PAC
    TSW-132-02-S-Q-RA.PAC
    TSW-132-02-S-S.PAC
    TSW-132-02-S-S-RA.PAC
    TSW-132-02-S-T.PAC
    TSW-132-02-S-T-RA.PAC
    TSW-133-02-S-D.PAC
    TSW-133-02-S-D-RA.PAC
    TSW-133-02-S-Q.PAC
    TSW-133-02-S-Q-RA.PAC
    TSW-133-02-S-S.PAC
    TSW-133-02-S-S-RA.PAC
    TSW-133-02-S-T.PAC
    TSW-133-02-S-T-RA.PAC
    TSW-134-02-S-D.PAC
    TSW-134-02-S-D-RA.PAC
    TSW-134-02-S-Q.PAC
    TSW-134-02-S-Q-RA.PAC
    TSW-134-02-S-S.PAC
    TSW-134-02-S-S-RA.PAC
    TSW-134-02-S-T.PAC
    TSW-134-02-S-T-RA.PAC
    TSW-135-02-S-D.PAC
    TSW-135-02-S-D-RA.PAC
    TSW-135-02-S-Q.PAC
    TSW-135-02-S-Q-RA.PAC
    TSW-135-02-S-S.PAC
    TSW-135-02-S-S-RA.PAC
    TSW-135-02-S-T.PAC
    TSW-135-02-S-T-RA.PAC
    TSW-136-02-S-D.PAC
    TSW-136-02-S-D-RA.PAC
    TSW-136-02-S-Q.PAC
    TSW-136-02-S-Q-RA.PAC
    TSW-136-02-S-S.PAC
    TSW-136-02-S-S-RA.PAC
    TSW-136-02-S-T.PAC
    TSW-136-02-S-T-RA.PAC
    TSW-137-02-S-D.PAC
    TSW-137-02-S-D-RA.PAC
    TSW-137-02-S-Q.PAC
    TSW-137-02-S-Q-RA.PAC
    TSW-137-02-S-S.PAC
    TSW-137-02-S-S-RA.PAC
    TSW-137-02-S-T.PAC
    TSW-137-02-S-T-RA.PAC
    TSW-138-02-S-D.PAC
    TSW-138-02-S-D-RA.PAC
    TSW-138-02-S-Q.PAC
    TSW-138-02-S-Q-RA.PAC
    TSW-138-02-S-S.PAC
    TSW-138-02-S-S-RA.PAC
    TSW-138-02-S-T.PAC
    TSW-138-02-S-T-RA.PAC
    TSW-139-02-S-D.PAC
    TSW-139-02-S-D-RA.PAC
    TSW-139-02-S-Q.PAC
    TSW-139-02-S-Q-RA.PAC
    TSW-139-02-S-S.PAC
    TSW-139-02-S-S-RA.PAC
    TSW-139-02-S-T.PAC
    TSW-139-02-S-T-RA.PAC
    TSW-140-02-S-D.PAC
    TSW-140-02-S-D-RA.PAC
    TSW-140-02-S-Q.PAC
    TSW-140-02-S-Q-RA.PAC
    TSW-140-02-S-S.PAC
    TSW-140-02-S-S-RA.PAC
    TSW-140-02-S-T.PAC
    TSW-140-02-S-T-RA.PAC
    TSW-141-02-S-D.PAC
    TSW-141-02-S-D-RA.PAC
    TSW-141-02-S-Q.PAC
    TSW-141-02-S-Q-RA.PAC
    TSW-141-02-S-S.PAC
    TSW-141-02-S-S-RA.PAC
    TSW-141-02-S-T.PAC
    TSW-141-02-S-T-RA.PAC
    TSW-142-02-S-D.PAC
    TSW-142-02-S-D-RA.PAC
    TSW-142-02-S-Q.PAC
    TSW-142-02-S-Q-RA.PAC
    TSW-142-02-S-S.PAC
    TSW-142-02-S-S-RA.PAC
    TSW-142-02-S-T.PAC
    TSW-142-02-S-T-RA.PAC
    TSW-143-02-S-D.PAC
    TSW-143-02-S-D-RA.PAC
    TSW-143-02-S-Q.PAC
    TSW-143-02-S-Q-RA.PAC
    TSW-143-02-S-S.PAC
    TSW-143-02-S-S-RA.PAC
    TSW-143-02-S-T.PAC
    TSW-143-02-S-T-RA.PAC
    TSW-144-02-S-D.PAC
    TSW-144-02-S-D-RA.PAC
    TSW-144-02-S-Q.PAC
    TSW-144-02-S-Q-RA.PAC
    TSW-144-02-S-S.PAC
    TSW-144-02-S-S-RA.PAC
    TSW-144-02-S-T.PAC
    TSW-144-02-S-T-RA.PAC
    TSW-145-02-S-D.PAC
    TSW-145-02-S-D-RA.PAC
    TSW-145-02-S-Q.PAC
    TSW-145-02-S-Q-RA.PAC
    TSW-145-02-S-S.PAC
    TSW-145-02-S-S-RA.PAC
    TSW-145-02-S-T.PAC
    TSW-145-02-S-T-RA.PAC
    TSW-146-02-S-D.PAC
    TSW-146-02-S-D-RA.PAC
    TSW-146-02-S-Q.PAC
    TSW-146-02-S-Q-RA.PAC
    TSW-146-02-S-S.PAC
    TSW-146-02-S-S-RA.PAC
    TSW-146-02-S-T.PAC
    TSW-146-02-S-T-RA.PAC
    TSW-147-02-S-D.PAC
    TSW-147-02-S-D-RA.PAC
    TSW-147-02-S-Q.PAC
    TSW-147-02-S-Q-RA.PAC
    TSW-147-02-S-S.PAC
    TSW-147-02-S-S-RA.PAC
    TSW-147-02-S-T.PAC
    TSW-147-02-S-T-RA.PAC
    TSW-148-02-S-D.PAC
    TSW-148-02-S-D-RA.PAC
    TSW-148-02-S-Q.PAC
    TSW-148-02-S-Q-RA.PAC
    TSW-148-02-S-S.PAC
    TSW-148-02-S-S-RA.PAC
    TSW-148-02-S-T.PAC
    TSW-148-02-S-T-RA.PAC
    TSW-149-02-S-D.PAC
    TSW-149-02-S-D-RA.PAC
    TSW-149-02-S-Q.PAC
    TSW-149-02-S-Q-RA.PAC
    TSW-149-02-S-S.PAC
    TSW-149-02-S-S-RA.PAC
    TSW-149-02-S-T.PAC
    TSW-149-02-S-T-RA.PAC
    TSW-150-02-S-D.PAC
    TSW-150-02-S-D-RA.PAC
    TSW-150-02-S-Q.PAC
    TSW-150-02-S-Q-RA.PAC
    TSW-150-02-S-S.PAC
    TSW-150-02-S-S-RA.PAC
    TSW-150-02-S-T.PAC
    TSW-150-02-S-T-RA.PAC

2010-05-17
  * con-tycoelectronics.lbr: Eagle 5.9.2
    finished: RJ11.DEV connected

2010-05-17
  * rcl.lbr: Eagle 5.9.2
    corrected PAD names: TSM53YJ.PAC

2010-05-10
  * display-kingbright.lbr: Eagle 5.9.1
    added:
    TC20-11HWA.DEV

2010-05-05
  * diode.lbr: Eagle 5.9.1
    added:
    MBRA340T3.DEV
    SMA.PAC

2010-05-05
  * national-semiconductor.lbr: Eagle 5.9.1
    added:
    LM2596.DEV
    LP2950.DEV
    LP2951.DEV
    DIL08.PAC
    H08C.PAC
    LLP8.PAC
    SO08.PAC
    T05A.PAC
    T05D.PAC
    TO92.PAC
    TO252.PAC
    TO263-5.PAC
    WG10A.PAC

2010-05-05
  * holtek.lbr: Eagle 5.9.1
    added:
    HT9170.DEV
    SO18L.PAC

2010-05-04
  * display-kingbright.lbr: Eagle 5.9.1
    added:
    TA20-11HWA.DEV
    TA20-11HWA.PAC

2010-05-04
  * freescale.lbr: Eagle 5.9.1
    added:
    MC9S08GT*A-32.DEV
    MC9S08GT*A-42.DEV
    MC9S08GT*A-44.DEV
    MC9S08GT*A-48.DEV
    QFN32.PAC
    QFN48.PAC

2010-05-03
  * 751xx.lbr: Eagle 5.9.1
    added:
    75176A.DEV
    DIL08.PAC
    D_R-PDSO-G8.PAC

2010-05-03
  * atmel.lbr: Eagle 5.9.1
    added:
    ATMEGA644-*PU.DEV

2010-05-03
  * memory.lbr: Eagle 5.9.1
    added:
    FM93C66.DEV
    DIL08.PAC
    M8.PAC
    TSSOP8.PAC

2010-05-03
  * st-microelectronics.lbr: Eagle 5.9.1
    added:
    FDIP32.PAC

2010-04-30
  * st-microelectronics.lbr: Eagle 5.9.0
    added:
    M27C4001.DEV
    DIL32.PAC
    LCC32.PAC
    TSOP32.PAC

2010-04-30
  * micro-cyrod.lbr: Eagle 5.9.0
    added:
    CRD89C51RD1T.DEV
    TQFP64L-10X10X2.0MM.PAC

2010-04-29
  * trafo.lbr: Eagle 5.9.0
    added:
    CTX02-14659.DEV
    SP-67.DEV
    CTX02-14659.PAC
    SP-67.PAC

2010-04-29
  * rohm.lbr: Eagle 5.9.0
    added:
    EMX1.DEV
    IMX1.DEV
    UMX1N.DEV
    EMT6.PAC
    SMT6.PAC
    UMT6.PAC

2010-04-22
  * diode.lbr: Eagle 5.8.1
    added:
    BAT54.DEV
    BAT54A.DEV
    BAT54C.DEV
    BAT54S.DEV

2010-04-13
  * sensor-infratec.lbr: Eagle 5.8.0
    added:
    LME-346-F.DEV
    TO39.PAC

2010-04-12
  * led.lbr: Eagle 5.8.0
    added:
    TLUV5300.DEV
    TLUV5300.PAC

2010-04-08
  * con-faston.lbr: Eagle 5.8.0
    added:
    PIN1-2.DEV
    62221.PAC

2010-04-06
  * xilinx-xc9.lbr: Eagle 5.8.0
    added:
    XC9536_44VQ.DEV
    XC9536_44PLCC.DEV
    PLCC44.PAC
    SQFP-S-10X10-44.PAC

2010-04-01
  * infineon.lbr: Eagle 5.8.0
    added:
    BSP613P.DEV
    BTS716G.DEV
    PG-DSO-20.PAC
    PG-SOT-223.PAC

2010-03-31
  * rectifier.lbr: Eagle 5.8.0
    added:
    B*S.DEV
    DF*S.DEV
    DFS.PAC
    MBS.PAC

2010-03-30
  * silabs.lbr: Eagle 5.8.0
    added:
    SI570.DEV
    SI571.DEV
    8-PIN.PAC

2010-03-29
  * analog-devices.lbr: Eagle 5.8.0
    added:
    AD9854.DEV
    AD9912.DEV

2010-03-29
  * inductors.lbr: Eagle 5.8.0
    added:
    CPH-E13/7/4-1S-6P.DEV
    CPH-E13/7/4-1S-6P.PAC

2010-03-29
  * con-molex.lbr: Eagle 5.8.0
    corrected: 679105700.PAC pins 18-52 moved X -0.3mm

2010-03-10
  * sensor-comus-group.lbr: Eagle 5.8.0
    added:
    CM4400.DEV
    CM4400.PAC

2010-03-10
  * buzzer.lbr: Eagle 5.8.0
    added:
    BMT1205XH7.5.DEV
    BPT-24X.DEV
    BMT1205XH7.5.PAC
    BPT-24X.PAC

2010-03-09
  * memory.lbr: Eagle 5.8.0
    added:
    SST39LF200A.DEV
    SST39LF400A.DEV
    SST39LF800A.DEV
    TSOP48.PAC
    WFBGA48.PAC
    XFBGA48.PAC

2010-03-05
  * con-yamaichi.lbr: Eagle 5.8.0
    added:
    IC51-0644-692.DEV
    IC51-0644-692.PAC

2010-03-04
  * led.lbr: Eagle 5.8.0
    added:
    L-115WEGW-CA.DEV
    DUOLED-A-3MM.PAC

2010-03-04
  * switch.lbr: Eagle 5.8.0
    added:
    2P2T.DEV
    2P2T.PAC

2010-03-04
  * memory.lbr: Eagle 5.8.0
    added:
    IS42S16100B.DEV
    IS42S16100T.DEV
    MBGA60.PAC
    TSOP50-II.PAC

2010-03-03
  * memory.lbr: Eagle 5.8.0
    added:
    SST39VF010.DEV
    SST39VF010B3.DEV
    SST39VF020.DEV
    SST39VF020B3.DEV
    SST39VF040.DEV
    SST39VF040B3.DEV
    SST39VF512.DEV
    PLCC32R.PAC
    TFBGA48.PAC

2010-03-03
  * national-semiconductor.lbr: Eagle 5.8.0
    added:
    DP83848.DEV
    LQFP48.PAC

2010-02-25
  * 74xx-us.lbr: Eagle 5.8.0
    added:
    DHVQFN14.PAC
    SSOP14.PAC
    TSSOP14.PAC

2010-02-25
  * 74xx-eu.lbr: Eagle 5.8.0
    added:
    DHVQFN14.PAC
    SSOP14.PAC
    TSSOP14.PAC

2010-02-22
  * analog-devices.lbr: Eagle 5.7.2
    added:
    AD5280.DEV
    AD5282.DEV

2010-02-18
  * texas.lbr: Eagle 5.7.2
    added:
    CC2531.DEV
    RHA_S-PVQFN-N40.PAC

2010-02-17
  * con-coax.lbr: Eagle 5.7.2
    added:
    PE44121.DEV
    PE44121.PAC

2010-02-15
  * texas.lbr: Eagle 5.7.2
    added:
    MSP430F23.DEV
    MSP430F24*.DEV
    MSP430F24*1.DEV
    RGC_S-PVQFV-N64.PAC

2010-02-12
  * display-kingbright.lbr: Eagle 5.7.1
    added:
    B?56-11*WA.DEV
    B?56-12*WA.DEV
    B?56-13*WA.DEV
    DA56-11.DEV
    DC56-11.DEV
    BX56-12.PAC
    DA56.PAC

2010-02-12
  * transistor-pnp.lbr: Eagle 5.7.1
    added:
    SOT54.PAC
    SOT323-BEC.PAC

2010-02-10
  * microchip.lbr: Eagle 5.7.1
    added:
    PIC16F19*.DEV
    PIC16F193*.DEV
    PIC16F193*?.DEV
    PIC16F193*ML.DEV

2010-02-08
  * con-wenzhou-yihua.lbr: Eagle 5.7.1
    added:
    YH-55-10.DEV
    YH-55-10.PAC

2010-02-04
  * linear-technology.lbr: Eagle 5.7.1
    added:
    LT5598.DEV
    LT6230.DEV
    LT6231.DEV
    LT6232.DEV
    DFN8-3X3.PAC
    QFN24-4X4.PAC
    S8.PAC
    SSOP16.PAC
    TSOT23-6.PAC

2010-02-04
  * fox-electronics.lbr: Eagle 5.7.1
    renamed: RTC72412.SYM to RTC72421.SYM

2010-02-03
  * freescale.lbr: Eagle 5.7.0
    changed: library description

2010-02-03
  * con-jack.lbr: Eagle 5.7.0
    changed description: SPC4077.PAC, SPC4078.PAC

2010-02-02
  * rcl.lbr: Eagle 5.7.0
    added:
    6000-XXXX-RC.PAC

2010-02-02
  * con-leotronics.lbr: Eagle 5.7.0
    corrected: all female connectors mirrored.

2010-02-02
  * con-xmultiple.lbr: Eagle 5.7.0
    added:
    XRJF.DEV
    XRJK*4.DEV
    XRJK*6.DEV
    XRJF-01A-0-D2A-010.PAC
    XRJK-S-01-6-4-0-9M2.PAC
    XRJK-S-01-6-6-0-2G2-NO.PAC

2010-02-01
  * con-tycoelectronics.lbr: Eagle 5.7.0
    added:
    2RJ11-6L-B.DEV
    4RJ11-6L-B.DEV
    6RJ11-6LB.DEV
    RJ11.DEV
    RJ11*2.DEV
    RJ45.DEV
    RJ45*2.DEV
    2RJ11.PAC
    4RJ11.PAC
    6RJ11.PAC
    RJ11-NO_SHIELD.PAC
    RJ11-SHIELD1.PAC
    RJ11-SHIELD2.PAC
    RJ45-NO-SHIELD.PAC
    RJ45-SHIELD1.PAC
    RJ45-SHIELD2.PAC

2010-02-01
  * con-4ucon.lbr: Eagle 5.7.0
    added:
    14867.DEV
    14867.PAC

2010-01-29
  * pot.lbr: Eagle 5.7.0
    added:
    3RP/1610G.DEV
    3RP/1610N.DEV
    3RP/1610G.PAC
    3RP/1610N.PAC

2010-01-27
  * led.lbr: Eagle 5.7.0
    added:
    XPEWHT-.DEV
    CREE_XLAMP.PAC

2010-01-21
  * freescale.lbr: Eagle 5.7.0
    added:
    MC33932.DEV

2010-01-21
  * freescale.lbr: Eagle 5.7.0
    added:
    HSOP44.PAC

2010-01-19
  * recom-international.lbr: Eagle 5.7.0
    added:
    RCD-24*/W.DEV
    RCD-24*/W/X1.DEV
    RCD-24*/W/X2.DEV
    RCD-24*/W/X3.DEV
    RCD-24B.DEV
    RCD-24/W.PAC
    RCD-24/W/X1.PAC
    RCD-24/W/X2.PAC
    RCD-24/W/X3.PAC
    RCD-24B-DIL.PAC
    RCD-24B-SMD.PAC

2010-01-11
  * analog-devices.lbr: Eagle 5.6.4
    added:
    AD8235.DEV
    AD8603.DEV
    AD8607.DEV
    AD8609.DEV
    BGA_CB11.PAC

2010-01-07
  * texas.lbr: Eagle 5.6.4
    corrected connection:
    MSP430F5*.DEV

2010-01-07
  * con-phoenix-smkdsp.lbr: Eagle 5.6.4
    changed pads to drill 1.6mm; diameter 1.8mm:
    SMKDSP_1,5/2.PAC
    SMKDSP_1,5/3.PAC
    SMKDSP_1,5/4.PAC
    SMKDSP_1,5/5.PAC
    SMKDSP_1,5/6.PAC
    SMKDSP_1,5/7.PAC
    SMKDSP_1,5/8.PAC
    SMKDSP_1,5/9.PAC
    SMKDSP_1,5/10.PAC
    SMKDSP_1,5/11.PAC
    SMKDSP_1,5/12.PAC
    SMKDSP_1,5/13.PAC
    SMKDSP_1,5/14.PAC
    SMKDSP_1,5/12.PAC

2010-01-07
  * microchip.lbr: Eagle 5.6.4
    changed smd size to 0.65  1.7 mm at package:
    SO28W.PAC

2009-12-22
  * logo.lbr: Eagle 5.6.3
    added:
    EAGLE-PLC-8MM.PAC
    EAGLE-PLC-10MM.PAC
    EAGLE-PLC-12MM.PAC
    EAGLE-PLC-15MM.PAC
    EAGLE-TOP-8MM.PAC
    EAGLE-TOP-10MM.PAC
    EAGLE-TOP-12MM.PAC
    EAGLE-TOP-15MM.PAC

2009-12-22
  * analog-devices.lbr: Eagle 5.6.3
    added:
    AD210.DEV
    AD215.DEV
    AD526.DEV
    AD623.DEV
    AD625.DEV
    AD627.DEV
    AD711.DEV
    AD712.DEV
    AD744.DEV
    AD745.DEV
    AD746.DEV
    AD797.DEV
    AD807*.DEV
    AD811.DEV
    AD817.DEV
    AD818.DEV
    AD820.DEV
    AD820N.DEV
    AD822.DEV
    AD825.DEV
    AD826.DEV
    AD845.DEV
    AD1985.DEV
    AD7676.DEV
    AD7730.DEV
    AD8001.DEV
    AD8015.DEV
    AD8031.DEV
    AD8033.DEV
    AD8041.DEV
    AD8042.DEV
    AD8065.DEV
    AD8066.DEV
    AD8079.DEV
    AD8519.DEV
    AD8529.DEV
    AD8541.DEV
    AD8542.DEV
    AD8544.DEV
    AD8597.DEV
    AD8599.DEV
    AD8610.DEV
    AD8614.DEV
    AD8620.DEV
    AD8644.DEV
    AD8655.DEV
    AD8656.DEV
    ADA4075-2.DEV
    ADA4627-1CP.DEV
    ADA4627-1R.DEV
    ADA4692-2.DEV
    ADA4692-4.DEV
    ADA4853-1.DEV
    ADA4853-2.DEV
    ADA4853-3RU.DEV
    ADA4853-3VQ.DEV
    ADAU1592.DEV
    ADAV801.DEV
    ADAV803.DEV
    ADAV804.DEV
    ADG411.DEV
    ADG412.DEV
    ADG413.DEV
    ADSP_21368.DEV
    ADSP_21369.DEV
    ADSP_21375.DEV
    ADSP_21462W.DEV
    ADSP_21467.DEV
    ADV7184.DEV
    ADV7194.DEV
    BUF04.DEV
    MAT04.DEV
    AD210.PAC
    AD215.PAC
    BGA_256.PAC
    BGA_324_CSP.PAC
    H08.PAC
    LFCSP8.PAC
    LFCSP8_CP.PAC
    SC70-5.PAC
    SC70-6.PAC
    SOIC16R.PAC
    SOIC20R.PAC
    TSSOP8.PAC

2009-12-22
  * linear.lbr: Eagle 5.6.3
    added:
    OP97.DEV
    OP183.DEV
    OP249.DEV
    OP270.DEV
    OP275.DEV
    HA5024.DEV

2009-12-21
  * supply-dummy.lbr: Eagle 5.6.3
  * special-pad.lbr: Eagle 5.6.3
  * ground-junctions.lbr: Eagle 5.6.3
    deleted: (used layer 53/54)

2009-12-21
  * supply1.lbr: Eagle 5.6.3
    deleted:
    GND-GNDA.DEV
    GND-GNDA.PAC
    Layer 53
    Layer 54

2009-12-14
  * resistor-power.lbr: Eagle 5.6.3
    added:
    AC01.PAC
    AC03.PAC
    AC04.PAC
    AC05.PAC
    AC07.PAC
    AC10.PAC
    CA0001.PAC
    CA0002.PAC
    CA4050.PAC
    CA4055.PAC
    CA4060.PAC
    CA4070.PAC
    CA4080.PAC
    CA4090.PAC
    CA4100.PAC
    CA4150.PAC
    CA4200.PAC
    CA4220.PAC
    CA5050.PAC
    CA5055.PAC
    CA5060.PAC
    CA5070.PAC
    CA5080.PAC
    CA5090.PAC
    CA5100.PAC
    CA5150.PAC
    CA5200.PAC
    CA5220.PAC
    HPS58.PAC
    HPS63.PAC
    HPS68.PAC
    HPS523.PAC
    HPS923.PAC
    HPS932.PAC
    HPS947.PAC
    RS01A.PAC
    RS01M.PAC
    RS1/2.PAC
    RS1/4.PAC
    RS1/8.PAC
    RS002.PAC
    RS02B.PAC
    RS02C.PAC
    RS02C_17-23.PAC
    RS02M.PAC
    RS05_69-70.PAC
    RS007.PAC
    RS10_38-39.PAC
    RWM4X10.PAC
    RWM4X22.PAC
    RWM5X26.PAC
    RWM6X22.PAC
    RWM6X34.PAC
    RWM8X26.PAC
    RWM8X34.PAC
    RWM8X45.PAC
    RWM10X45.PAC
    RWM10X64.PAC
    RWM10X65.PAC

2009-12-11
  * e-sps.lbr: Eagle 5.6.3
    added:
    NS-80.DEV
    NS-80.PAC

2009-12-10
  * e-sps.lbr: Eagle 5.6.3
    added:
    AL2-2DA.DEV
    AL2-2PT-ADP.DEV
    AL2-4EX.DEV
    AL2-4EX-A2.DEV
    AL2-4EYR.DEV
    AL2-4EYT.DEV
    AL2-14MR-D.DEV
    AL2-24MR-A.DEV
    AL2-24MR-D.DEV
    AL2-2DA.PAC
    AL2-2PT-ADP.PAC
    AL2-4EX.PAC
    AL2-4EX-A2.PAC
    AL2-4EYR.PAC
    AL2-4EYT.PAC
    AL2-14MR-D.PAC
    AL2-24MR-A.PAC
    AL2-24MR-D.PAC

2009-12-10
  * linear-technology.lbr: Eagle 5.6.3
    added:
    LT1763.DEV
    LT1763CS8.DEV
    DFN12.PAC
    LT1963EFE.DEV
    TSSOP16.PAC
    TSSOP16EXP.PAC

2009-12-09
  * micro-philips.lbr: Eagle 5.6.3
    added: package variant SO8
    PCA82C250.DEV

2009-12-08
  * u-blox.lbr: Eagle 5.6.3
    added:
    LEON-G100/G200.DEV
    LEON-G100/G200.PAC

2009-12-04
  * analog-devices.lbr: Eagle 5.6.2
    added:
    AD1877.DEV
    AD1890.DEV
    AD1891.DEV
    AD1892.DEV
    AD1953.DEV
    AD1954.DEV
    AD1983.DEV
    DIL28-6.PAC
    SO-28R.PAC

2009-12-04
  * con-phoenix-762.lbr: Eagle 5.6.2
    transferred from con-phoenix-508.lbr:
    GMSTBA2.DEV
    GMSTBA3.DEV
    GMSTBA4.DEV
    GMSTBA6.DEV
    GMSTBA7.DEV
    GMSTBA8.DEV
    GMSTBA9.DEV
    GMSTBA10.DEV
    GMSTBA12.DEV
    GMSTBV2.DEV
    GMSTBV3.DEV
    GMSTBV4.DEV
    GMSTBV5.DEV
    GMSTBV6.DEV
    GMSTBV7.DEV
    GMSTBV8.DEV
    GMSTBV9.DEV
    GMSTBV10.DEV
    GMSTBV12.DEV
    GMSTBA2.PAC
    GMSTBA3.PAC
    GMSTBA4.PAC
    GMSTBA6.PAC
    GMSTBA7.PAC
    GMSTBA8.PAC
    GMSTBA9.PAC
    GMSTBA10.PAC
    GMSTBA12.PAC
    GMSTBV2.PAC
    GMSTBV3.PAC
    GMSTBV4.PAC
    GMSTBV5.PAC
    GMSTBV6.PAC
    GMSTBV7.PAC
    GMSTBV8.PAC
    GMSTBV9.PAC
    GMSTBV10.PAC
    GMSTBV12.PAC
    GMST2H.PAC
    GMST2V.PAC
    GMST3H.PAC
    GMST3V.PAC
    GMST4H.PAC
    GMST4V.PAC
    GMST5H.PAC
    GMST5V.PAC

2009-12-04
  * con-phoenix-508.lbr: Eagle 5.6.2
    transferred to con-phoenix-762.lbr:
    GMSTBA2.DEV
    GMSTBA3.DEV
    GMSTBA4.DEV
    GMSTBA6.DEV
    GMSTBA7.DEV
    GMSTBA8.DEV
    GMSTBA9.DEV
    GMSTBA10.DEV
    GMSTBA12.DEV
    GMSTBV2.DEV
    GMSTBV3.DEV
    GMSTBV4.DEV
    GMSTBV5.DEV
    GMSTBV6.DEV
    GMSTBV7.DEV
    GMSTBV8.DEV
    GMSTBV9.DEV
    GMSTBV10.DEV
    GMSTBV12.DEV
    GMSTBA2.PAC
    GMSTBA3.PAC
    GMSTBA4.PAC
    GMSTBA6.PAC
    GMSTBA7.PAC
    GMSTBA8.PAC
    GMSTBA9.PAC
    GMSTBA10.PAC
    GMSTBA12.PAC
    GMSTBV2.PAC
    GMSTBV3.PAC
    GMSTBV4.PAC
    GMSTBV5.PAC
    GMSTBV6.PAC
    GMSTBV7.PAC
    GMSTBV8.PAC
    GMSTBV9.PAC
    GMSTBV10.PAC
    GMSTBV12.PAC
    GMST2H.PAC
    GMST2V.PAC
    GMST3H.PAC
    GMST3V.PAC
    GMST4H.PAC
    GMST4V.PAC
    GMST5H.PAC
    GMST5V.PAC

2009-12-03
  * special-drill.lbr: Eagle 5.6.2
    added:
    PAD_0.1800.PAC

2009-12-02
  * linx.lbr: Eagle 5.6.2
    added:
    TRM-*-LT.DEV
    TRM-XXX-LT.PAC

2009-12-02
  * linear.lbr: Eagle 5.6.2
    added:
    TL331.DEV
    DBV-R-PDSO-G5.PAC

2009-12-02
  * diode.lbr: Eagle 5.6.2
    added:
    1N581*.DEV
    DO41-7.6.PAC

2009-12-01
  * eib-busch-jaeger.lbr: Eagle 5.6.2
    added:
    6010-25.DEV
    6020-XX.DEV
    6021-XX.DEV
    6108-U.DEV
    6109-U.DEV
    6110-U-101.DEV
    6114-U.DEV
    6115-XX-101.DEV
    6116-XX-101.DEV
    6117-XX-101.DEV
    6119/20.DEV
    6119/40.DEV
    6122-XX.DEV
    6123-XX.DEV
    6123USB-XX.DEV
    6124-XX.DEV
    6125-XX.DEV
    6126-XX.DEV
    6127-XX.DEV
    6127MF-XX.DEV
    6128-XX.DEV
    6129-XX.DEV
    6131-XX-102.DEV
    6132-XX-102.DEV
    6132-XX-102M.DEV
    6133-XX-101.DEV
    6133USB-XX.DEV
    6134-XX-102.DEV
    6134/10.DEV
    6135-XX-102.DEV
    6136-XX.DEV
    6136/30M.DEV
    6136/40-101.DEV
    6136/100C.DEV
    6136/100CB.DEV
    6136/100M.DEV
    6140-101.DEV
    6144/10-101.DEV
    6146.DEV
    6146-101.DEV
    6151EB.DEV
    6152EB-101.DEV
    6153EB.DEV
    6155EB-101.DEV
    6156EB.DEV
    6157EB.DEV
    6158EB.DEV
    6164/40.DEV
    6164U.DEV
    6172AG-101.DEV
    6173AG-101.DEV
    6174/10.DEV
    6174/11.DEV
    6174/12.DEV
    6174/13.DEV
    6174/14.DEV
    6174/15.DEV
    6174/16.DEV
    6174/17.DEV
    6174/18.DEV
    6174/19.DEV
    6174/20.DEV
    6174/21.DEV
    6179-XX.DEV
    6180-102.DEV
    6180/10.DEV
    6180/11.DEV
    6181-101.DEV
    6186/20.DEV
    6186/30.DEV
    6186USB.DEV
    6187-103.DEV
    6188/13.DEV
    6188/14.DEV
    6188/15.DEV
    6188/16.DEV
    6188/17.DEV
    6188/18.DEV
    6190/10.DEV
    6190/40-101.DEV
    6193/32.DEV
    6194/11.DEV
    6194/12.DEV
    6194/13.DEV
    6194/14.DEV
    6194/15.DEV
    6194/16.DEV
    6194/17.DEV
    6195/21.DEV
    6195/22.DEV
    6195/24.DEV
    6195/25.DEV
    6195/26.DEV
    6196/20.DEV
    6196/40-101.DEV
    6196/41-101.DEV
    6196/42.DEV
    6196/43.DEV
    6196/80.DEV
    6196/82.DEV
    6197/22.DEV
    6197/40.DEV
    6198-101.DEV
    6198/JA.DEV
    6198ST.DEV
    6321-XX.DEV
    6322-XX-101.DEV
    6323-XX.DEV
    6324-XX.DEV
    6325-XX.DEV
    6326-XX-101.DEV
    6327-XX.DEV
    6010-25.PAC
    6020-XX.PAC
    6021-XX.PAC
    6108-U.PAC
    6109-U.PAC
    6110-U-101.PAC
    6114-U.PAC
    6115-XX-101.PAC
    6116-XX-101.PAC
    6117-XX-101.PAC
    6119/20.PAC
    6119/40.PAC
    6122-XX.PAC
    6123-XX.PAC
    6123USB-XX.PAC
    6124-XX.PAC
    6125-XX.PAC
    6126-XX.PAC
    6127-XX.PAC
    6127MF-XX.PAC
    6128-XX.PAC
    6129-XX.PAC
    6131-XX-102.PAC
    6132-XX-102.PAC
    6132-XX-102M.PAC
    6133-XX-101.PAC
    6133USB-XX.PAC
    6134-XX-102.PAC
    6134/10.PAC
    6135-XX-102.PAC
    6136-XX.PAC
    6136/30M.PAC
    6136/40-101.PAC
    6136/100C.PAC
    6136/100CB.PAC
    6136/100M.PAC
    6140-101.PAC
    6144/10-101.PAC
    6146.PAC
    6146-101.PAC
    6151EB.PAC
    6152EB-101.PAC
    6153EB.PAC
    6155EB-101.PAC
    6156EB.PAC
    6157EB.PAC
    6158EB.PAC
    6164/40.PAC
    6164U.PAC
    6172AG-101.PAC
    6173AG-101.PAC
    6174/10.PAC
    6174/11.PAC
    6174/12.PAC
    6174/13.PAC
    6174/14.PAC
    6174/15.PAC
    6174/16.PAC
    6174/17.PAC
    6174/18.PAC
    6174/19.PAC
    6174/20.PAC
    6174/21.PAC
    6179-XX.PAC
    6180-102.PAC
    6180/10.PAC
    6180/11.PAC
    6181-101.PAC
    6186/10.PAC
    6186/20.PAC
    6186/30.PAC
    6186AG.PAC
    6186USB.PAC
    6187-103.PAC
    6188/13.PAC
    6188/14.PAC
    6188/15.PAC
    6188/16.PAC
    6188/17.PAC
    6188/18.PAC
    6190/10.PAC
    6190/40-101.PAC
    6191/10.PAC
    6193/32.PAC
    6194/11.PAC
    6194/12.PAC
    6194/13.PAC
    6194/14.PAC
    6194/15.PAC
    6194/16.PAC
    6194/17.PAC
    6194/23.PAC
    6194/27.PAC
    6195/21.PAC
    6195/22.PAC
    6195/24.PAC
    6195/25.PAC
    6195/26.PAC
    6196/20.PAC
    6196/40-101.PAC
    6196/41-101.PAC
    6196/42.PAC
    6196/43.PAC
    6196/80.PAC
    6196/82.PAC
    6197/11-102.PAC
    6197/20.PAC
    6198-101.PAC
    6198/JA.PAC
    6198ST.PAC
    6321-XX.PAC
    6322-XX-101.PAC
    6323-XX.PAC
    6324-XX.PAC
    6325-XX.PAC
    6326-XX-101.PAC
    6327-XX.PAC

2009-12-01
  * e-sps.lbr: Eagle 5.6.2
    added:
    S7-1200_AC/DC/RELAIS.DEV
    S7-1200_DC/DC/DC.DEV
    SB_1223_DC/DC.DEV
    SB_1232AO1.DEV
    SM1222_DO_16X24VDC.DEV
    SM1222_DO_16XRELAIS.DEV
    SM_1221_DI_8X24VDC.DEV
    SM_1221_DI_16X24VDC.DEV
    SM_1223_DI-16X24VDC_DO-16X24VDC.DEV
    SM_1223_DI-16X24VDC_DO-16XRELAIS.DEV
    SM_1231_AI4X13BIT.DEV
    SM_1232_AQ2X14BIT.DEV
    SM_1234_AI4X13BIT-AQ2X14BIT.DEV
    S7-1200_AC/DC/RELAIS.PAC
    S7-1200_DC/DC/DC.PAC
    SB_1223_DC/DC.PAC
    SB_1232AO1.PAC
    SM1222_DO_16X24VDC.PAC
    SM1222_DO_16XRELAIS.PAC
    SM_1221_DI_8X24VDC.PAC
    SM_1221_DI_16X24VDC.PAC
    SM_1223_DI-16X24VDC_DO-16X24VDC.PAC
    SM_1223_DI-16X24VDC_DO-16XRELAIS.PAC
    SM_1231_AI4X13BIT.PAC
    SM_1232_AQ2X14BIT.PAC
    SM_1234_AI4X13BIT-AQ2X14BIT.PAC

2009-11-30
  * resistor-power.lbr: Eagle 5.6.2
    added:
    RMG100.DEV
    TO-247-2H.PAC
    TO-247-2V.PAC

2009-11-27
  * e-steckverbinder.lbr: Eagle 5.6.2
    set PREFIX: STECKVERBINDER_5-POL.DEV

2009-11-27
  * atmel.lbr: Eagle 5.6.2
    added:
    AT45DB642D.DEV
    28T-TSOP-1.PAC

2009-11-25
  * murata-filter.lbr: Eagle 5.6.2
    added:
    NFM.DEV
    NFM3DC.PAC
    NFM21C.PAC

2009-11-25
  * analog-devices.lbr: Eagle 5.6.2
    added:
    ADUM1300.DEV
    ADUM1301.DEV

2009-11-25
  * texas.lbr: Eagle 5.6.2
    added:
    SN74LVCR162245A.DEV
    DL_R-PDSO-G48.PAC

2009-11-24
  * analog-devices.lbr: Eagle 5.6.2
    added:
    AD1836.DEV

2009-11-23
  * transistor-fet.lbr: Eagle 5.6.2
    added:
    2SJ109.DEV
    2SK389.DEV
    2-10M1A.PAC

2009-11-17
  * allegro.lbr: Eagle 5.6.2
    added:
    A3982.DEV

2009-11-17
  * atmel.lbr: Eagle 5.6.2
    added:
    ATMEGA325P.DEV
    64M1.PAC

2009-11-17
  * allegro.lbr: Eagle 5.6.2
    added:
    A4983.DEV
    QFN28ET.PAC

2009-11-09
  * texas.lbr: Eagle 5.6.1
    added:
    TUSB2046BIRHB.DEV
    TUSB2046B.DEV
    VF_S-PQFP-G32.PAC
    RHB_S-PQFP-N32.PAC

2009-10-22
  * texas.lbr: Eagle 5.6.1
    added:
    TMS320VC5509.DEV

2009-10-22
  * texas.lbr: Eagle 5.6.1
    added:
    TMS320VC5509A.DEV
    GHH_S-PBGA-N179.PAC

2009-10-22
  * analog-devices.lbr: Eagle 5.6.1
    added:
    SSM2165.DEV
    SSM2166.DEV
    SSM2167.DEV
    SO14.PAC

2009-10-19
  * micro-intel.lbr: Eagle 5.6.1
    added:
    HL-PBGA304.PAC
    HL-PBGA352.PAC
    HL-PBGA432.PAC
    PBGA196.PAC
    PBGA208.PAC
    PBGA241.PAC
    PBGA256-17.PAC
    PBGA256-27.PAC
    PBGA304.PAC
    PBGA324.PAC
    PBGA421.PAC
    PBGA468.PAC
    PBGA544.PAC

2009-10-19
  * texas.lbr: Eagle 5.6.1
    added:
    OMAP-L138ZCE.DEV
    OMAP-L138ZWT.DEV
    ZCE_S-PBGA-N361.PAC
    ZEN_S-PBGA-N196.PAC
    ZWT_S-PBGA-N361.PAC

2009-10-15
  * rohm.lbr: Eagle 5.6.1
    added:
    BD623*F.DEV
    BD623*FP.DEV
    BD623*HFP.DEV
    BD6232FP.DEV
    HRP7.PAC
    HSOP25.PAC
    HSOP28.PAC
    SOP8.PAC

2009-10-14
  * texas.lbr: Eagle 5.6.1
    added:
    ADS1274.DEV

2009-10-12
  * gennum.lbr: Eagle 5.6.1
    added:
    GS2970.DEV
    GS2974.DEV
    GS4910B.DEV
    GS4911B.DEV
    GS4915.DEV
    LBGA100.PAC
    QFN16-4X4.PAC
    QFN40-6X6.PAC
    QFN64-9X9.PAC

2009-10-12
  * altera-stratix-iv.lbr: Eagle 5.6.1
    added:
    EP4S40G2F40ES1.DEV
    EP4S40G5H40ES1.DEV
    EP4S100G2F40ES1.DEV
    EP4S100G5F45ES1.DEV
    EP4S100G5H40ES1.DEV
    EP4SE230F29.DEV
    EP4SE360F35.DEV
    EP4SE360H29.DEV
    EP4SE530F43.DEV
    EP4SE530H35.DEV
    EP4SE530H40.DEV
    EP4SGX70DF29.DEV
    EP4SGX70HF35.DEV
    EP4SGX110DF29.DEV
    EP4SGX110FF35.DEV
    EP4SGX110HF35.DEV
    EP4SGX180DF29.DEV
    EP4SGX180FF35.DEV
    EP4SGX180HF35.DEV
    EP4SGX180KF40.DEV
    EP4SGX230DF29.DEV
    EP4SGX230FF35.DEV
    EP4SGX230HF35.DEV
    EP4SGX230KF40.DEV
    EP4SGX290FF35.DEV
    EP4SGX290FH29.DEV
    EP4SGX290HF35.DEV
    EP4SGX290KF40.DEV
    EP4SGX290KF43.DEV
    EP4SGX360FF35.DEV
    EP4SGX360FH29.DEV
    EP4SGX360HF35.DEV
    EP4SGX360KF40.DEV
    EP4SGX360KF43.DEV
    EP4SGX530HH35.DEV
    EP4SGX530KF43.DEV
    EP4SGX530KH40.DEV
    EP4SGX530NF45.DEV
    FBGA780.PAC
    FBGA1152.PAC
    FBGA1517.PAC
    FBGA1760.PAC
    FBGA1932.PAC

2009-10-12
  * burr-brown.lbr: Eagle 5.6.1
    added:
    INA163.DEV
    INA217.DEV
    PGA2500.DEV
    DB_R-PDSO-G28.PAC
    DW_RPDSO-G16.PAC

2009-10-12
  * linear.lbr: Eagle 5.6.1
    added:
    LM*18.DEV
    OPA725.DEV
    OPA726.DEV
    OPA2725.DEV
    OPA2726.DEV
    SA5534.DEV
    D_R-PDSO-G8.PAC
    LCCC20.PAC
    LCCC28.PAC
    PS_R-PDSO-G8.PAC

2009-10-12
  * texas.lbr: Eagle 5.6.1
    added:
    ADS1210.DEV
    ADS1211.DEV
    ADS1211E.DEV
    ADS1271.DEV
    ADS1278.DEV
    DIT4192-H.DEV
    DIT4192-S.DEV
    DIX4192.DEV
    ISO1050.DEV
    OMAP-L137.DEV
    PCM1792.DEV
    PCM1796.DEV
    PCM1804.DEV
    PCM4204.DEV
    PCM4220.DEV
    PCM4222.DEV
    SN65LVD*125.DEV
    SRC4382.DEV
    SRC4392.DEV
    TAS5261.DEV
    TL7660.DEV
    TMS320C64X_DSP.DEV
    TMS320C6474.DEV
    TMS320C6720*DH.DEV
    TMS320C6720RFP.DEV
    TMS320C6720RFP-EXPAD.DEV
    DBT_R-PDSO-G38.PAC
    DB_R-PDSO-G28.PAC
    DGK_S-PDSO-G8.PAC
    DKD_R-PDSO-G36.PAC
    DUB-R-PDSO-G8.PAC
    GDH_S-PBGA-N256.PAC
    GTS_S-PBGA-N288.PAC
    PAP_S-PQFP-G64.PAC
    PDIP-T24.PAC
    PDIP-T28.PAC
    PFB_S-PQFP-G48.PAC
    RFP_S-PQFP-G144-EXP.PAC
    RFP_S-PQFP-G144-EXPAD.PAC
    S-PQFP-G48.PAC
    TSSOP16.PAC
    ZDH_S-PBGA-N256.PAC
    ZKB_S-PBGA-N256.PAC
    ZUN_SPBGA-N561.PAC

2009-10-08
  * linear.lbr: Eagle 5.6.1
    added:
    OPA22*.DEV
    OPA222*.DEV
    OPA422*.DEV
    OPA2134.DEV
    OPA4134.DEV

2009-10-08
  * opto-trans-siemens.lbr: Eagle 5.6.1
    added:
    SFH303.DEV
    SFH303.PAC

2009-09-28
  * con-lumberg.lbr: Eagle 5.6.0
    corrected PIN/PAD connection:
    NEB1R.DEV
    NEB1R.PAC
    NEBJ21R.DEV
    NEBJ21R.PAC
    NEBJ21.DEV
    NEBJ21.PAC
    NEBJ25R.DEV
    NEBJ25R.PAC
    NEBJ25.DEV
    NEBJ25.PAC

2009-09-24
  * linear.lbr: Eagle 5.6.0
    corrected connection: DAC0808D.DEV

2009-09-24
  * con-molex.lbr: Eagle 5.6.0
    added:
    105081-0001.DEV
    105081-0001.PAC

2009-09-16
  * microchip.lbr: Eagle 5.6.0
    added:
    PIC16F688.DEV
    QFN16-4X4.PAC

2009-09-11
  * texas.lbr: Eagle 5.6.0
    added:
    TPS6108*.DEV

2009-09-10
  * texas.lbr: Eagle 5.6.0
    added:
    MSP430FG437.DEV

2009-08-26
  * nrj-semiconductor.lbr: Eagle 5.6.0
    added:
    NJU9207B.DEV
    qfp80-C1.PAC

2009-08-25
  * con-vg.lbr: Eagle 5.6.0
    added:
    FH11.DEV
    FH11.PAC

2009-08-25
  * infineon.lbr: Eagle 5.6.0
    added:
    TLE5205-2.DEV
    P-TO220-7-11.PAC
    P-TO220-7-12.PAC
    P-TO263-7-1.PAC

2009-08-17
  * transistor.lbr: Eagle 5.6.0
    corrected:
    *-NPN.DEV BC635, BC639, BC639 Packagevariant TO92-ECB

2009-08-13
  * allegro.lbr: Eagle 5.6.0
    added:
    A12*?.DEV
    A13*?.DEV
    A136*.DEV
    SIP3-UA.PAC
    SIP4-KT.PAC
    SOT23-W.PAC

2009-08-12
  * con-molex.lbr: Eagle 5.6.0
    added:
    87438-02.DEV
    87438-03.DEV
    87438-04.DEV
    87438-05.DEV
    87438-06.DEV
    87438-07.DEV
    87438-08.DEV
    87438-09.DEV
    87438-10.DEV
    87438-11.DEV
    87438-12.DEV
    87438-13.DEV
    87438-14.DEV
    87438-15.DEV
    87438-02.PAC
    87438-03.PAC
    87438-04.PAC
    87438-05.PAC
    87438-06.PAC
    87438-07.PAC
    87438-08.PAC
    87438-09.PAC
    87438-10.PAC
    87438-11.PAC
    87438-12.PAC
    87438-13.PAC
    87438-14.PAC
    87438-15.PAC

2009-08-06
  * led.lbr: Eagle 5.6.0
    added:
    F50360.DEV
    LZ1-00WW03.DEV
    LZ1-00WW05.DEV
    LZ4-00WW10.DEV
    LZC-00CW40.DEV
    W724C0.DEV
    W49180.DEV
    X42180.DEV
    X42182.DEV
    F50360.PAC
    LZ1-00WW03.PAC
    LZ4-00WW10.PAC
    LZC-00CW40.PAC
    W724C0.PAC
    Z-POWER-LED-DOME-TYPE.PAC
    Z-POWER-LED-PCB-TYPE.PAC

2009-08-06
  * texas.lbr: Eagle 5.6.0
    added:
    TPA3123D2.DEV
    PWP-TSSOP24.PAC

2009-08-03
  * advanced-test-technologies.lbr: Eagle 5.6.0
    added:
    64POL-SOCKED.DEV
    QFP-SOCKED-64.PAC

2009-08-03
  * relay.lbr: Eagle 5.6.0
    added:
    9802.DEV
    9814.DEV
    9852.DEV
    9802-00.PAC
    9802-20.PAC
    9814-00.PAC
    9814-20.PAC
    9852-00.PAC
    9852-20.PAC

2009-08-03
  * analog-devices.lbr: Eagle 5.6.0
    added:
    ADG608.DEV
    ADG609.DEV
    ADG658.DEV
    ADG659.DEV
    ADG1408YCPZ.DEV
    ADG1408YRUZ.DEV
    ADG1409YCPZ.DEV
    ADG1409YRUZ.DEV
    QSOP16.PAC
    TSSOP16.PAC

2009-07-28
  * pot.lbr: Eagle 5.6.0
    added:
    3223G.PAC
    3223J.PAC
    3223W.PAC

2009-07-16
  * maxim.lbr: Eagle 5.6.0
    added:
    DS2726.DEV
    TQFN32.PAC

2009-07-10
  * texas.lbr: Eagle 5.6.0
    added:
    TPA6132A2.DEV
    QFN16.PAC

2009-07-08
  * *.lbr: Eagle 5.6.0
    checked all LBR, changed >NAME, >PART, >GATE, >VALUE to proportional font

2009-07-08
  * con-lumberg.lbr: Eagle 5.6.0
    corrected pad coordinate PAD 'B':
    KLBR4.PAC

2009-07-06
  * led.lbr: Eagle 5.6.0
    added:
    NSSM038A.DEV
    NSSM038A.PAC

2009-06-29
  * texas.lbr: Eagle 5.6.0
    added:
    UC*637.DEV
    DIL18.PAC

2009-06-26
  * con-coax.lbr: Eagle 5.6.0
    added:
    LTI-SASF54GT.DEV
    LTI-SASF54GT.PAC

2009-06-24
  * con-lumberg.lbr: Eagle 5.6.0
    corrected connection/pad:
    KLBR4.DEV

2009-06-24
  * con-lumberg.lbr: Eagle 5.6.0
    corrected milling:
    1503_04.PAC

2009-06-23
  * allegro.lbr: Eagle 5.6.0
    added:
    ACS758*.DEV
    CB-PFF.PAC

2009-06-19
  * con-pulse.lbr: Eagle 5.6.0
    added:
    J1006F01P.DEV
    J1006F21.DEV
    J1011F.DEV
    J1012F21R.DEV
    J1026F.DEV
    J1026F01.DEV
    J11012F.DEV
    JP006821U.DEV
    JP011821U.DEV
    JP026851U.DEV
    J1.PAC
    JP.PAC

2009-06-18
  * atmel.lbr: Eagle 5.6.0
    added:
    XMEGA16A4.DEV
    XMEGA128A1.DEV

2009-06-18
  * display-hp.lbr: Eagle 5.6.0
    corrected: included missing Pin LEDSUP in PWR.SYM (HTIL311A.DEV)

2009-06-18
  * atmel.lbr: Eagle 5.6.0
    changed: Pin VCC1=VCC@1,  GND1=GND@2  (PAD 52/53) and visible both
    MEGA64.SYM
    MEGA64-M.SYM
    MEGA128.SYM
    MEGA128-M.SYM
    MEGA169.SYM
    MEGA169-M.SYM
    48-I/O-1.SYM

2009-06-16
  * trafo-bei.lbr: Eagle 5.6.0
    added: 2 holes at HDS28G2.PAC

2009-06-15
  * con-ebyelectro.lbr: Eagle 5.6.0
    added:
    5202-12-N-02.DEV
    5202-12-N-02.PAC

2009-06-09
  * cypress.lbr: Eagle 5.6.0
    added:
    CY8C2*345.DEV
    CY8C22545.DEV
    SOIC28-3.PAC
    TQFP44.PAC
    CY8C21234.DEV
    CY8C21334.DEV
    CY8C21434.DEV
    CY8C21534.DEV
    CY8C21634.DEV
    QFN32.PAC
    QFN32-MAX06.PAC
    QFN32-SAWN.PAC
    SOIC16.PAC
    SSOP20.PAC
    SSOP28.PAC

2009-06-09
  * con-hirose.lbr: Eagle 5.6.0
    corrected stop mask: FH28-50S-0.5SH(51)

2009-06-09
  * inductors.lbr: Eagle 5.6.0
    added:
    BL0.DEV
    BL01RN1A.PAC
    BL02RN1.PAC
    BL02RN2.PAC
    BL03RN2.PAC

2009-06-04
  * infineon.lbr: Eagle 5.6.0
    correct smd coordinate in package:
    PG-DSO-36.PAC
    PG-DSO-36PAD.PAC
    PG-DSO-36W.pac

2009-05-28
  * microchip.lbr: Eagle 5.6.0
    package changed TQFP100 to SQFP-S-12X12-100.PAC:
    PIC32MX320F128L.DEV
    PIC32MX360F256L.DEV
    PIC32MX360F512L.DEV
    PIC32MX440F128L.DEV
    PIC32MX460F256L.DEV
    PIC32MX460F512L.DEV

2009-05-25
  * microchip.lbr: Eagle 5.6.0
    deleted: Variant 8S0 (PIC16LF628SO)
    Variant doesn't exist.

2009-05-18
  * maxim.lbr: Eagle 5.6.0
    added:
    MAX312.DEV
    MAX313.DEV
    MAX314.DEV

2009-05-18
  * pinhead.lbr: Eagle 5.6.0
    added:
    1X22/90.PAC
    1X24/90.PAC
    2X22/90.PAC
    2X24/90.PAC
    2X25/90.PAC
    2X30/90.PAC
    Added variant '/90' to all devices.

2009-05-13
  * testpad.lbr: Eagle 5.6.0
    new: ATTRIBUTE >TP_SIGNAL_NAME in all devices

2009-05-04
  * e-sicherungen.lbr: Eagle 5.5.0
    added:
    FEHLER-STROM-SCHUTZSCHALTER_2-POL.DEV
    FEHLER-STROM-SCHUTZSCHALTER_4-POL.DEV
    FEHLER-STROM-SCHUTZSCHALTER_2-POL.PAC
    FEHLER-STROM-SCHUTZSCHALTER_4-POL.PAC

2009-04-27
  * con-coax.lbr: Eagle 5.5.0
    changed description (Distributor deleted) in:
    BU-SMA-H.PAC
    BU-SMA-H.DEV

2009-04-24
  * transistor-fet.lbr: Eagle 5.5.0
    added:
    FDD4141.DEV
    D2PACK.PAC

2009-04-24
  * trafo-bei.lbr: Eagle 5.5.0
    added:
    HDS.DEV
    HDS28G2.PAC

2009-04-21
  * relay.lbr: Eagle 5.4.8
    added:
    AZ8-FORM-A.DEV
    AZ8-FORM-C.DEV
    AZ8.PAC

2009-04-21
  * con-ebyelectro.lbr: Eagle 5.4.8
    added:
    5202-03-N-02.DEV
    5202-04-N-02.DEV
    5202-05-N-02.DEV
    5202-06-N-02.DEV
    5202-03-N-02.PAC
    5202-04-N-02.PAC
    5202-05-N-02.PAC
    5202-06-N-02.PAC

2009-04-20
  * transistor-fet.lbr: Eagle 5.4.8
    added:
    2N5950.DEV

2009-04-20
  * pinhead.lbr: Eagle 5.4.8
    added:
    PINHD-1X40.DEV
    1X40.PAC

2009-04-20
  * micro-philips.lbr: Eagle 5.4.8
    added from Christopher K. Johnson <chris@dirigo.net>:
    PCA9505.DEV
    PCA9506.DEV
    TSSOP56-6.PAC

2009-04-20
  * con-molex.lbr: Eagle 5.4.8
    added:
    71436-XX64.DEV
    71436-XX64.PAC

2009-04-16
  * linear.lbr: Eagle 5.4.8
    changed description: LM387.DEV
    Low Noise Dual Preamplifier

2009-04-08
  * nanotec.lbr: Eagle 5.4.8
    added:
    IMT-901.DEV
    SIL25.PAC

2009-03-23
  * e-elektro-zeichnungsrahmen.lbr: Eagle 5.4.6
    added:
    RAHMEN_A3_12Z-28S.DEV

2009-03-23
  * transistor-neu-to92.lbr: Eagle 5.4.6
    corrected symbol PNP:
    BDX54.DEV

2009-03-23
  * transistor.lbr: Eagle 5.4.6
    corrected symbol PNP:
    BDX54.DEV

2009-03-23
  * ftdichip.lbr: Eagle 5.4.4
    corrected pin directions: FT232R.SYM

2009-03-11
  * sharp.lbr: Eagle 5.4.4
    added:
    IR2D07.DEV
    IR2D20U.DEV
    IR2E49U6.DEV
    IR2E53Y7.DEV
    PQ6CB11X1CP.DEV
    DIL28-4.PAC
    HQFN052.PAC
    PQ6CB11X1CP.PAC
    VQFN036-P-0606.PAC
    WLP035-X-3636.PAC

2009-03-11
  * led.lbr: Eagle 5.4.4
    added:
    GM1BW76340A.DEV
    GM1BW78140A.DEV
    GM1WA55311A.DEV
    GM5BW96385A.DEV
    GM5WA94310A.DEV
    GM1BW78140A.PAC
    GM1WA55311A.PAC
    GM5BW96385A.PAC
    GM5WA94310A.PAC

2009-03-09
  * maxim.lbr: Eagle 5.4.3
    added:
    MAX10*.DEV
    MAX103*.DEV

2009-03-06
  * con-subd.lbr: Eagle 5.4.1
    added:
    M25-HD-20.DEV
    M25-HD-20.PAC
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

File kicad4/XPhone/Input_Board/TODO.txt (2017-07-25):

//------------------------------------------------------------------------------
// TODO
//------------------------------------------------------------------------------

Put the L1, L2, L3, L4 references inside their boxes.

Print the circuit on paper to make sure all looks right.

Copy circuit 4 times; generate BOM; order protopack from dirtypcbs;

//------------------------------------------------------------------------------
// DONE
//------------------------------------------------------------------------------
Add V_ENV_BIAS circuit.

Polish the F.Fab.

Add Text to indicate what the headers are.
Provide better numbers.
Maybe do this on the reverse side?

label power connector

Polish the silkscreen.

Think about how you are going to mount these in the XPhone case.
Adding mounting holes would be a good idea.

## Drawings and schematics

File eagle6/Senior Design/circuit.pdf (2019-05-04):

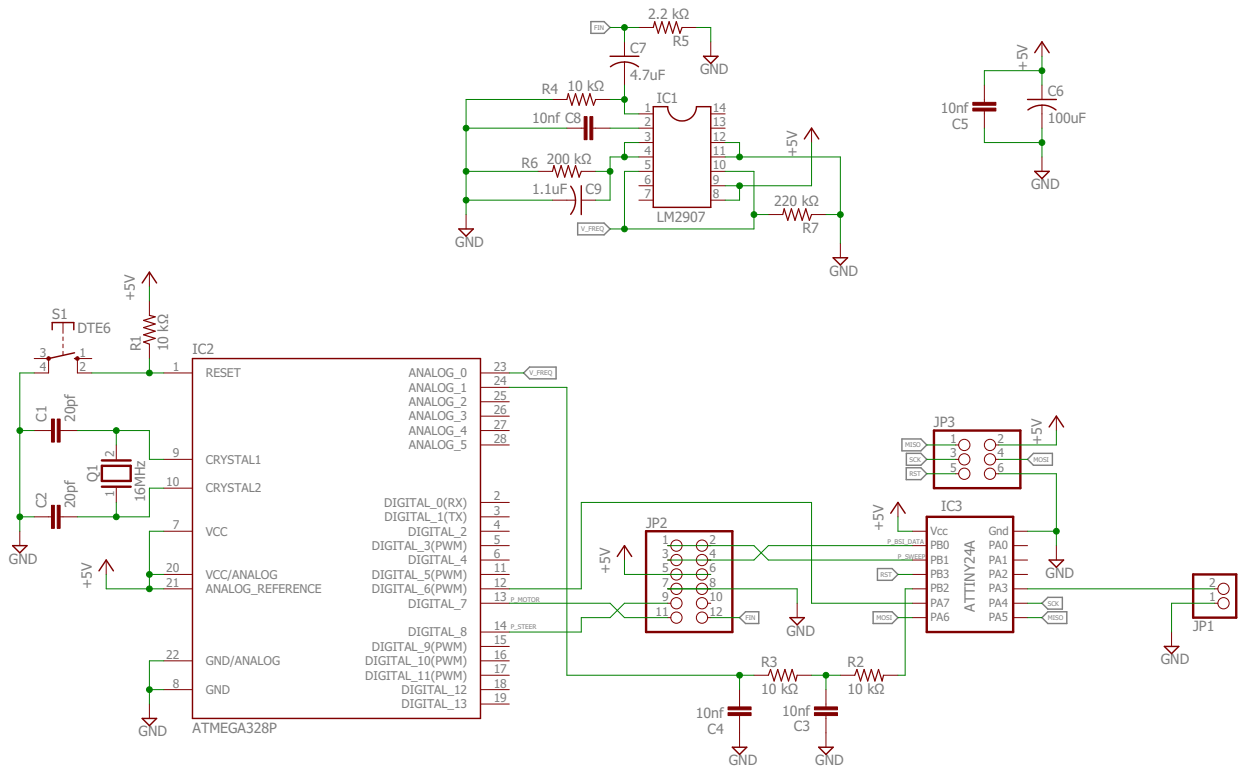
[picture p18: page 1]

ATTINY24A ATMEGA328P GND +5V +5V GND 16MHz +5V DTE6 10 kΩ +5V GND GND 20pf 20pf 10 kΩ 10 kΩ 10nf 10nf GND GND GND 10nf 100uF +5V GND+5V LM2907 4.7uF 10nf 1.1uF10 kΩ 2.2 kΩ 200 kΩ +5V GND GND GND 220 kΩ Vcc Gnd PB0 PB1 PB3 PB2 PA7 PA6 PA0 PA1 PA2 PA3 PA4 PA5 IC3 IC2 DIGITAL_13 19 CRYSTAL2 10 CRYSTAL1 9 GND 8 VCC 7 GND/ANALOG 22 ANALOG_REFERENCE 21 VCC/ANALOG 20 DIGITAL_12 18 DIGITAL_11(PWM) 17 DIGITAL_10(PWM) 16 DIGITAL_9(PWM) 15 DIGITAL_8 14 DIGITAL_7 13 DIGITAL_6(PWM) 12 DIGITAL_5(PWM) 11 DIGITAL_4 6 DIGITAL_3(PWM) 5 DIGITAL_2 4 DIGITAL_1(TX) 3 DIGITAL_0(RX) 2 ANALOG_5 28 ANALOG_4 27 ANALOG_3 26 ANALOG_2 25 ANALOG_1 24 ANALOG_0 23 RESET 1 JP21 2 3 4 5 6 7 8 9 10 11 12 2 1 Q1 S1 3 1 4 2 R1 C1 C2 JP112 R3 R2 C4 C3 C5 C6 JP31 2 3 4 5 6 IC1 1234567 891011121314 C7 C8 C9 R4 R5 R6 R7 P_BSI_DATA P_SWEEP P_MOTOR P_STEER RST RST MOSI MOSI SCK SCK MISO MISO V_FREQ V_FREQ FIN FIN

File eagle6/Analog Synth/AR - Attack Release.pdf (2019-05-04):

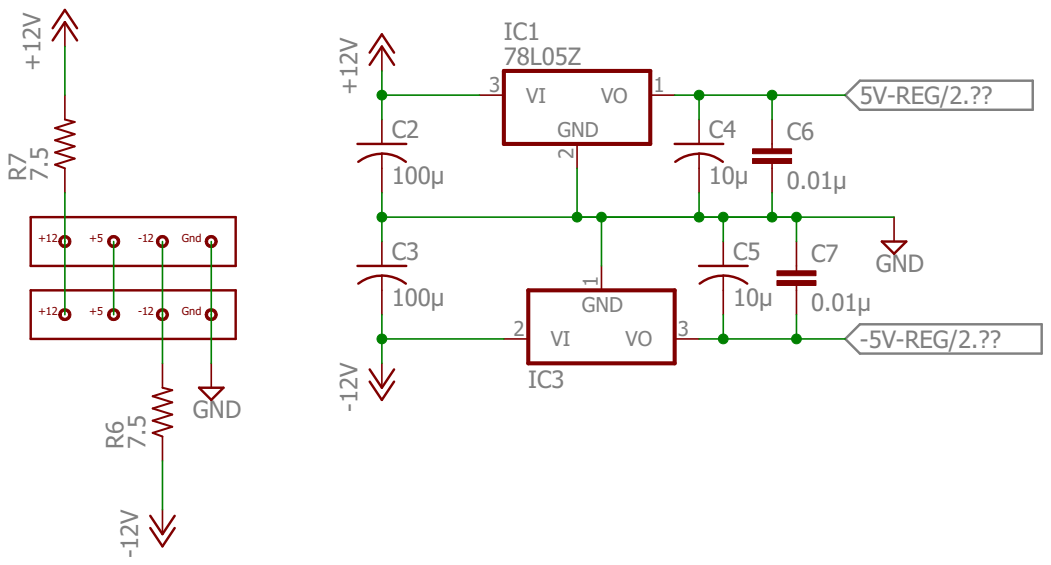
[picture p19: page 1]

-12V 7.5 7.5 +12V GND 100µ 100µ +12V -12V GND 78L05Z 10µ10µ 0.01µ 0.01µ R6 R7 C2C3 IC1 GND VI 3 2 VO 1 IC3 GND VI 2 1 VO 3 C4C5 C6C7 5V-REG/2.?? -5V-REG/2.?? +12 +5 -12 Gnd +12 +5 -12 Gnd

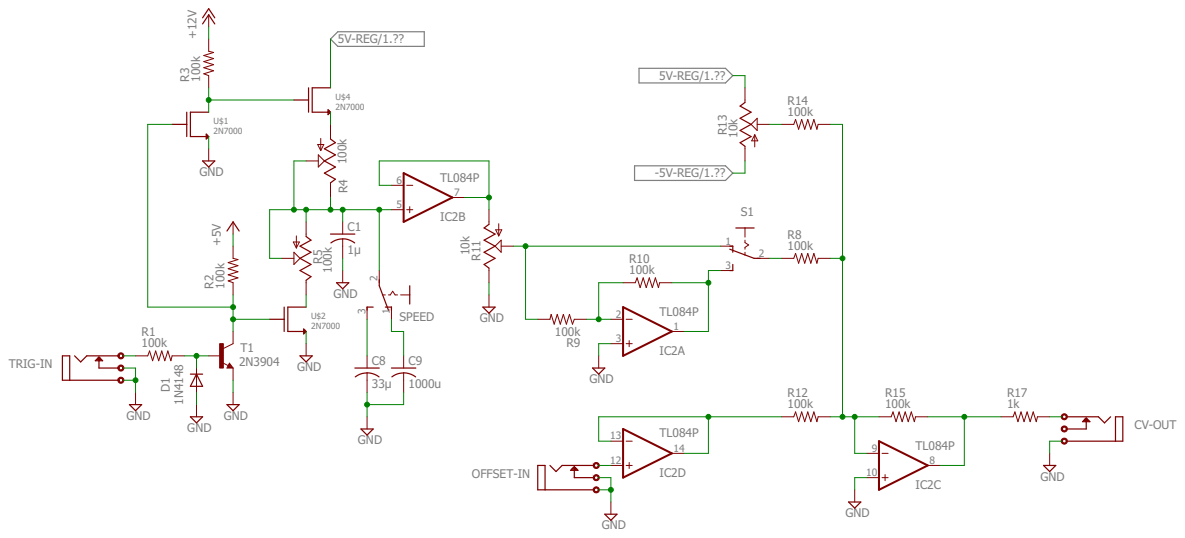
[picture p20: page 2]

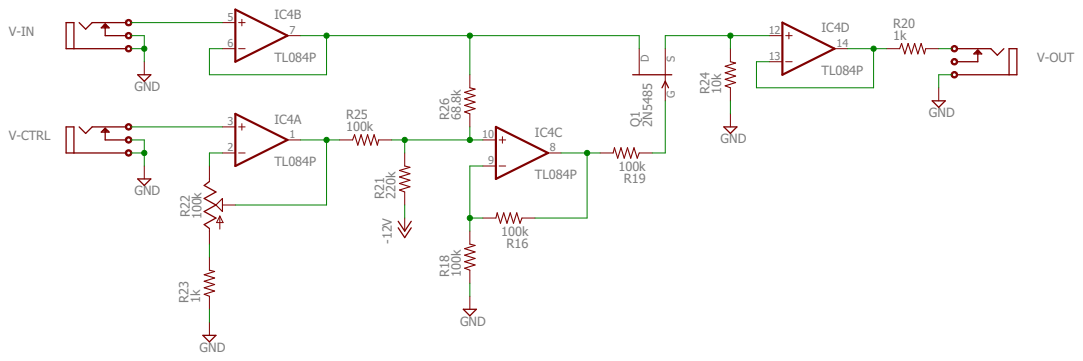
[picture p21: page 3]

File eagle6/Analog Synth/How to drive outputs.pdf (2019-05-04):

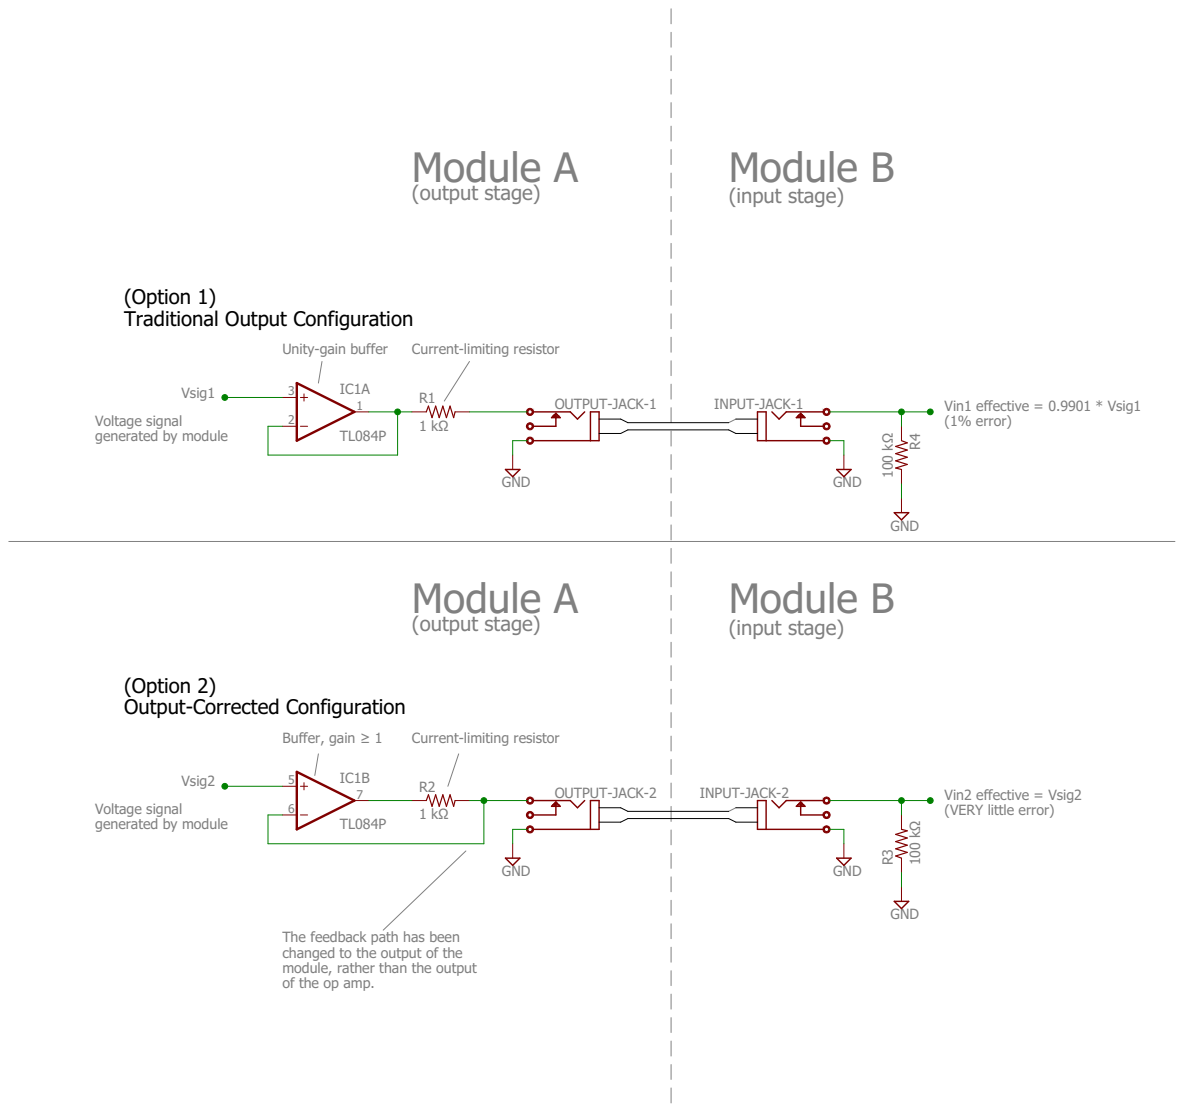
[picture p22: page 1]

The feedback path has been
changed to the output of the module, rather than the output of the op amp.

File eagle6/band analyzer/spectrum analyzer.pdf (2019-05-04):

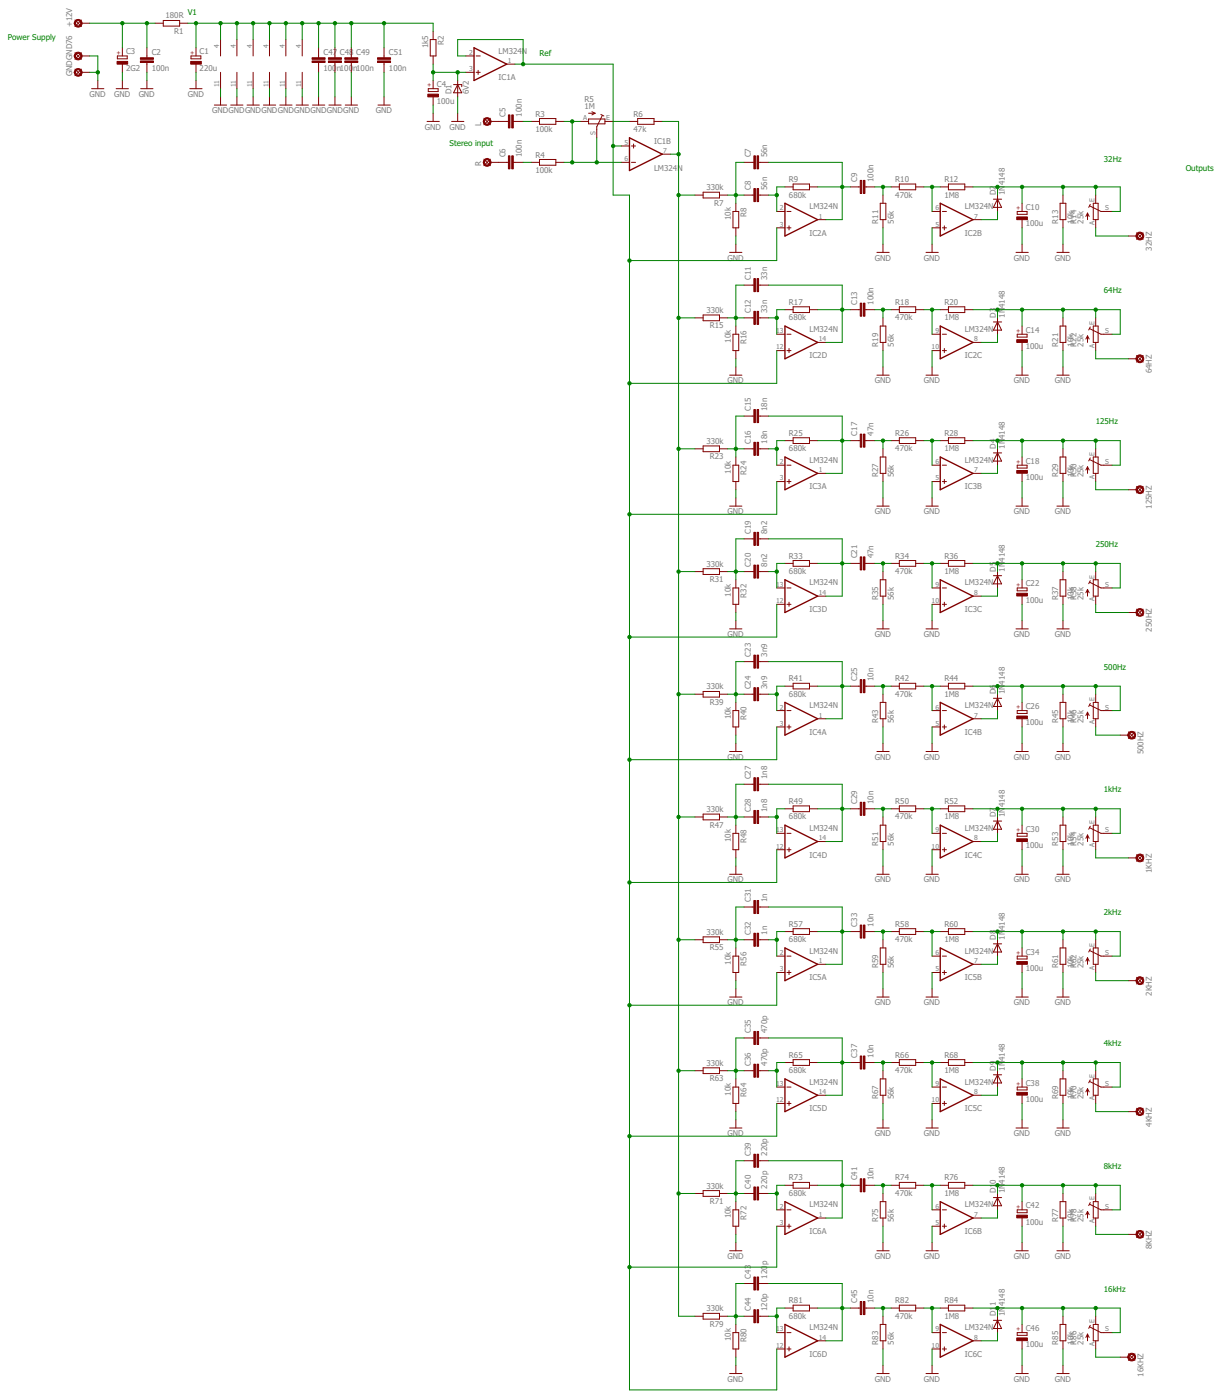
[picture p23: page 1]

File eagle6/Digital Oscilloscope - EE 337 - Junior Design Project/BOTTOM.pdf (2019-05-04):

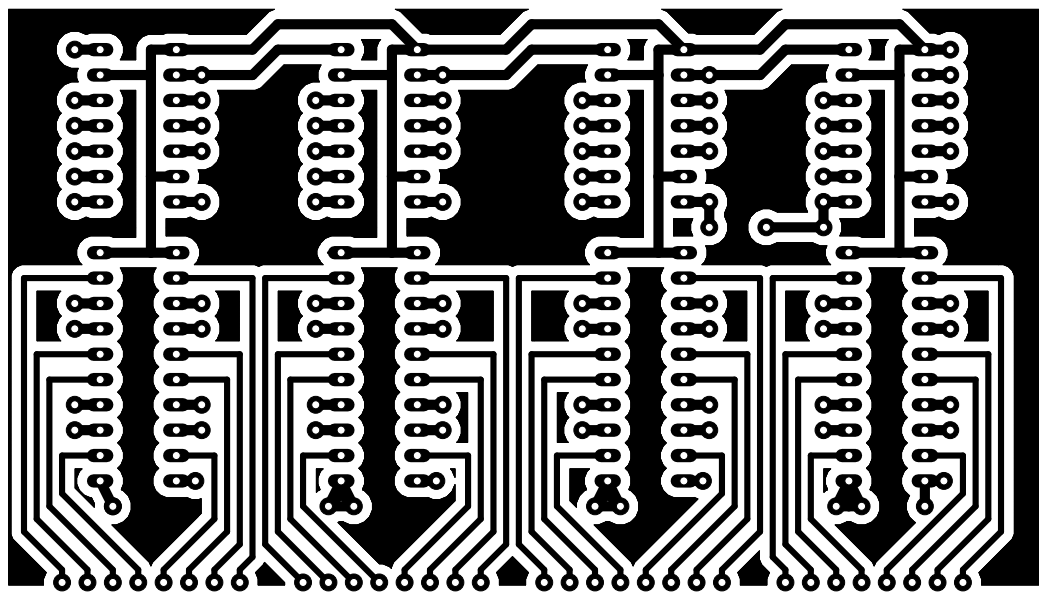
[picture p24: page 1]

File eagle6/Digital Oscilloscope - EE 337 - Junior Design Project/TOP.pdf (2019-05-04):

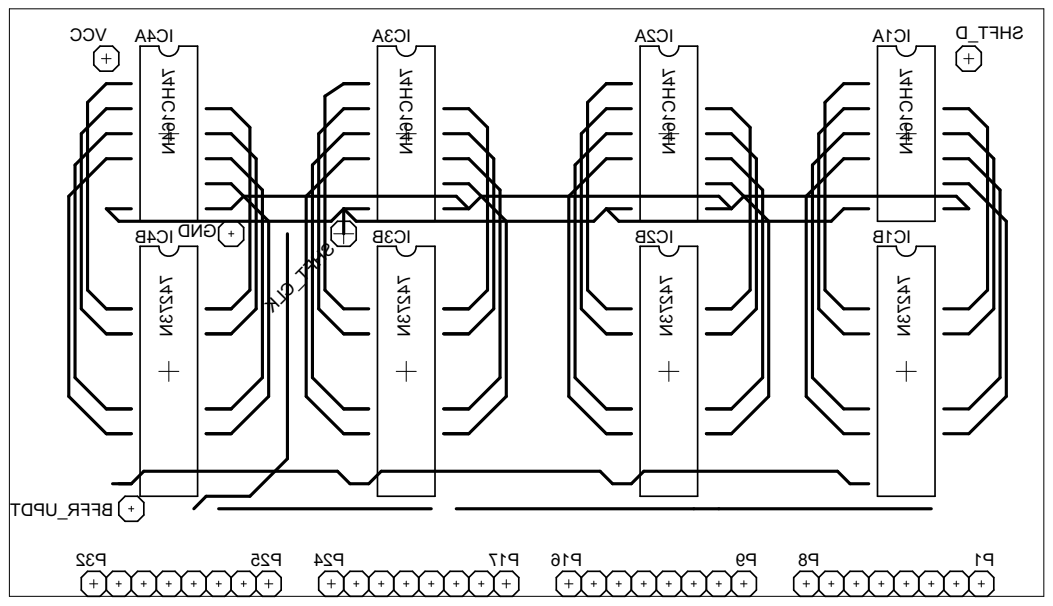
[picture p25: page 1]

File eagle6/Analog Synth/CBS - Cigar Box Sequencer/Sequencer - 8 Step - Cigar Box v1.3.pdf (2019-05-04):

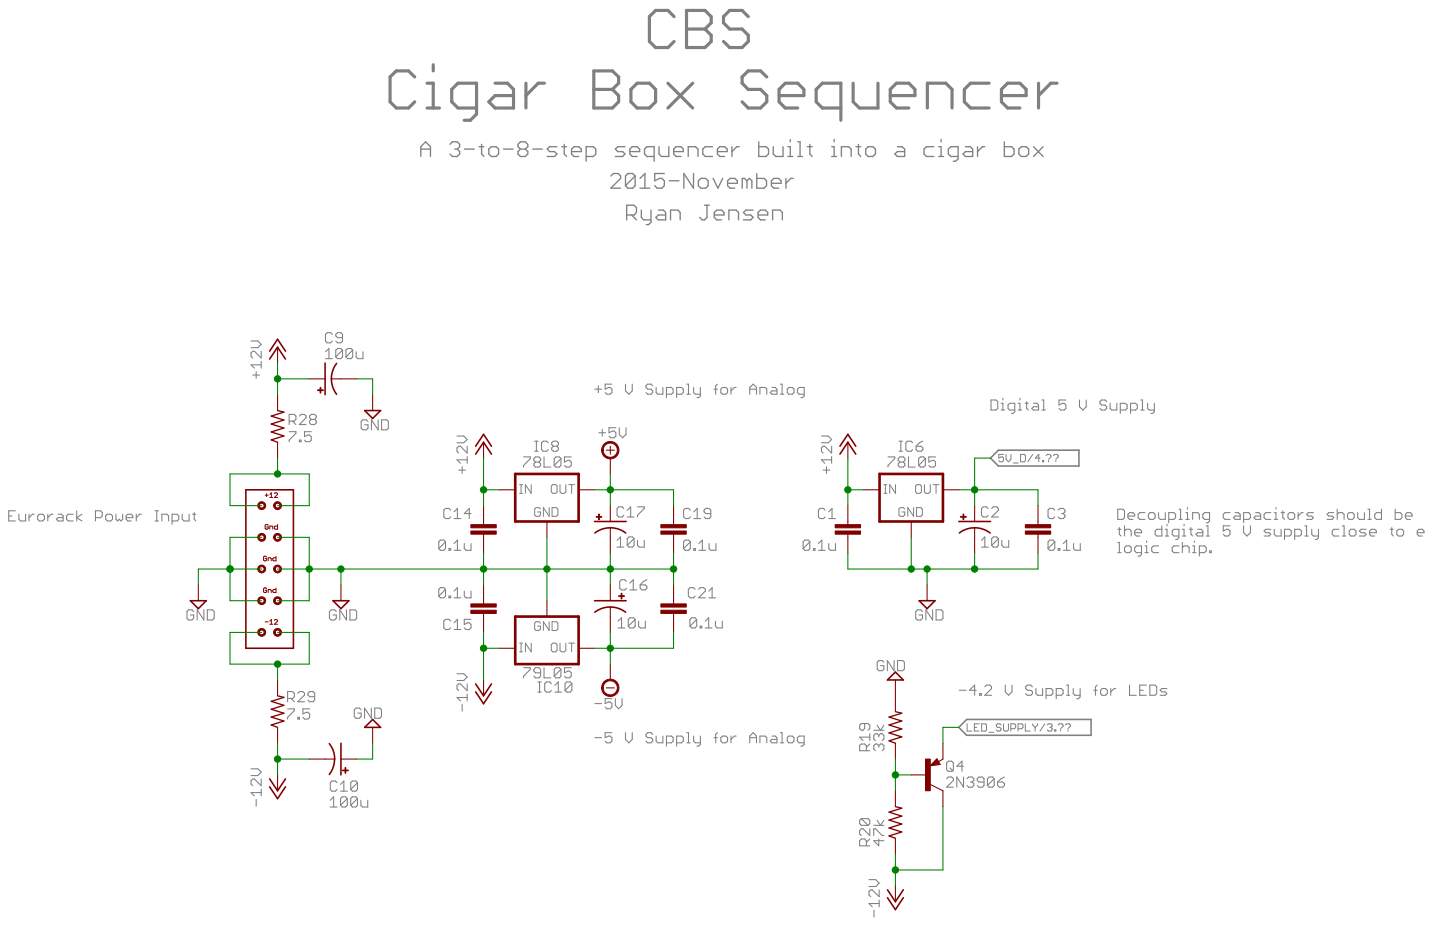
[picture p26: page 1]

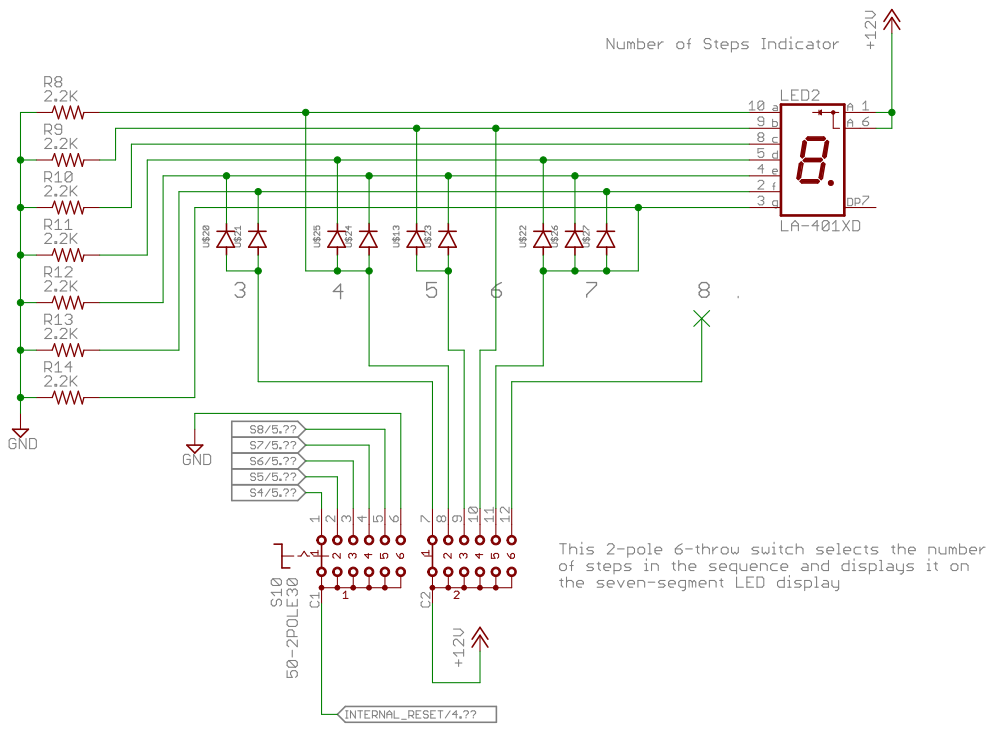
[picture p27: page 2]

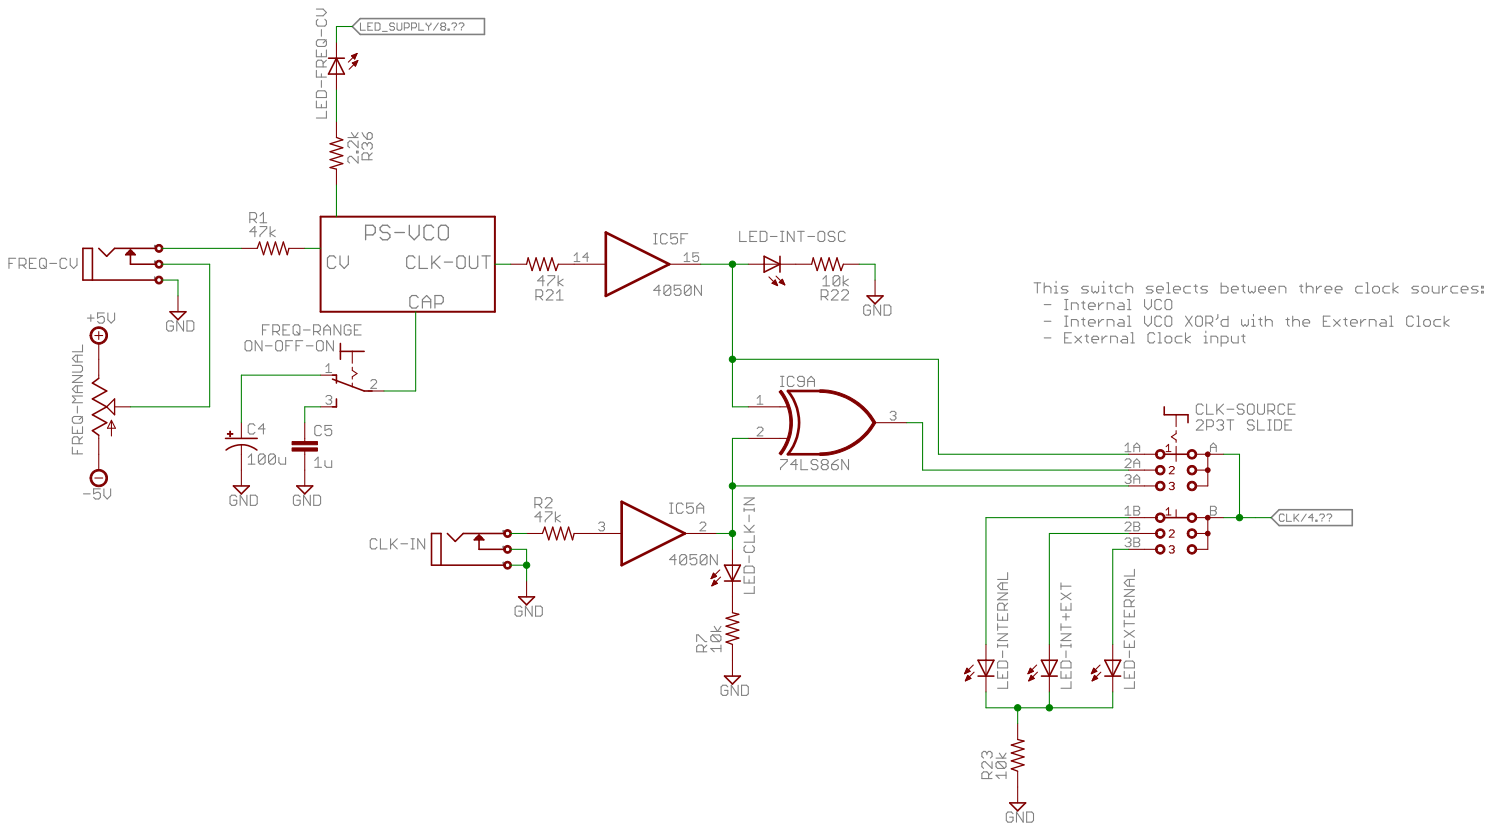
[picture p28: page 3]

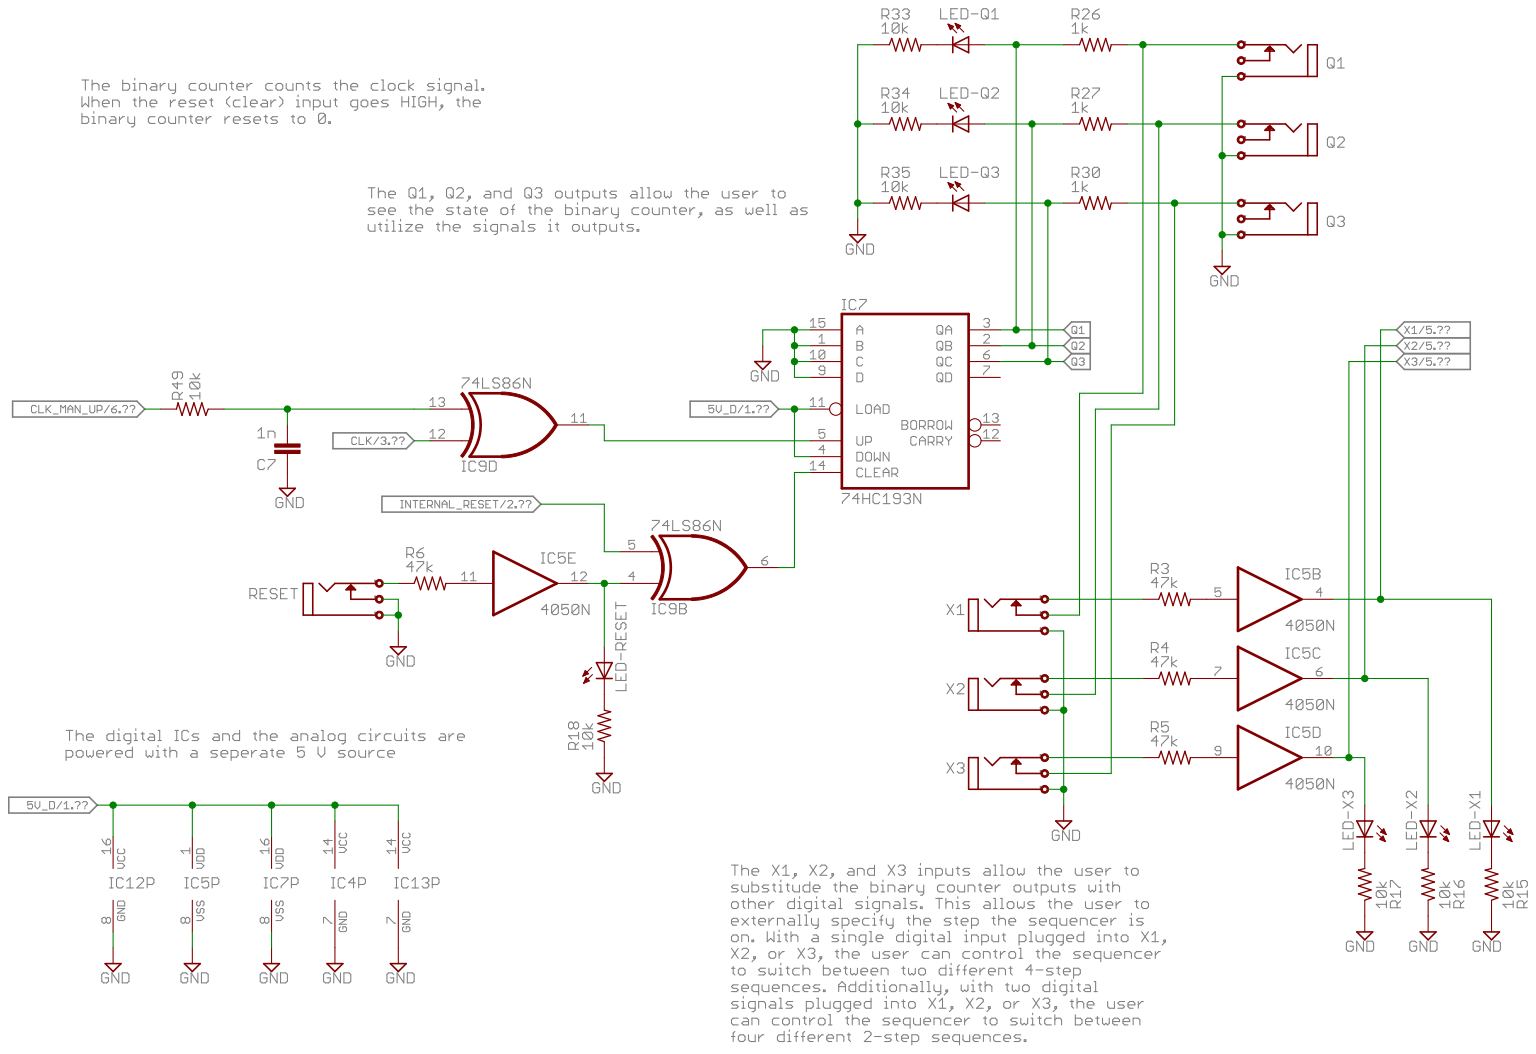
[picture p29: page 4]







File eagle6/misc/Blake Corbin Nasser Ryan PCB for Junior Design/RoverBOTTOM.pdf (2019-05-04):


nelli Gni br oC

i mj al Ar essaN

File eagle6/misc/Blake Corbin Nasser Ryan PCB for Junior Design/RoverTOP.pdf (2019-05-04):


E392L T713 IC1 2CIR1 R2 C1 S2 - LTOM +LTOM - RTOM +RTOM LF LB RF RB +LCNE DNGLCNE PI+PIGND ENCLENCR PROXECHO GI RTXORP GI SLCNE +RCNE DNGRCNE GI SRCNE +XORP TRIGSND DNSOHCE DNGXORP - TAB+TAB C2



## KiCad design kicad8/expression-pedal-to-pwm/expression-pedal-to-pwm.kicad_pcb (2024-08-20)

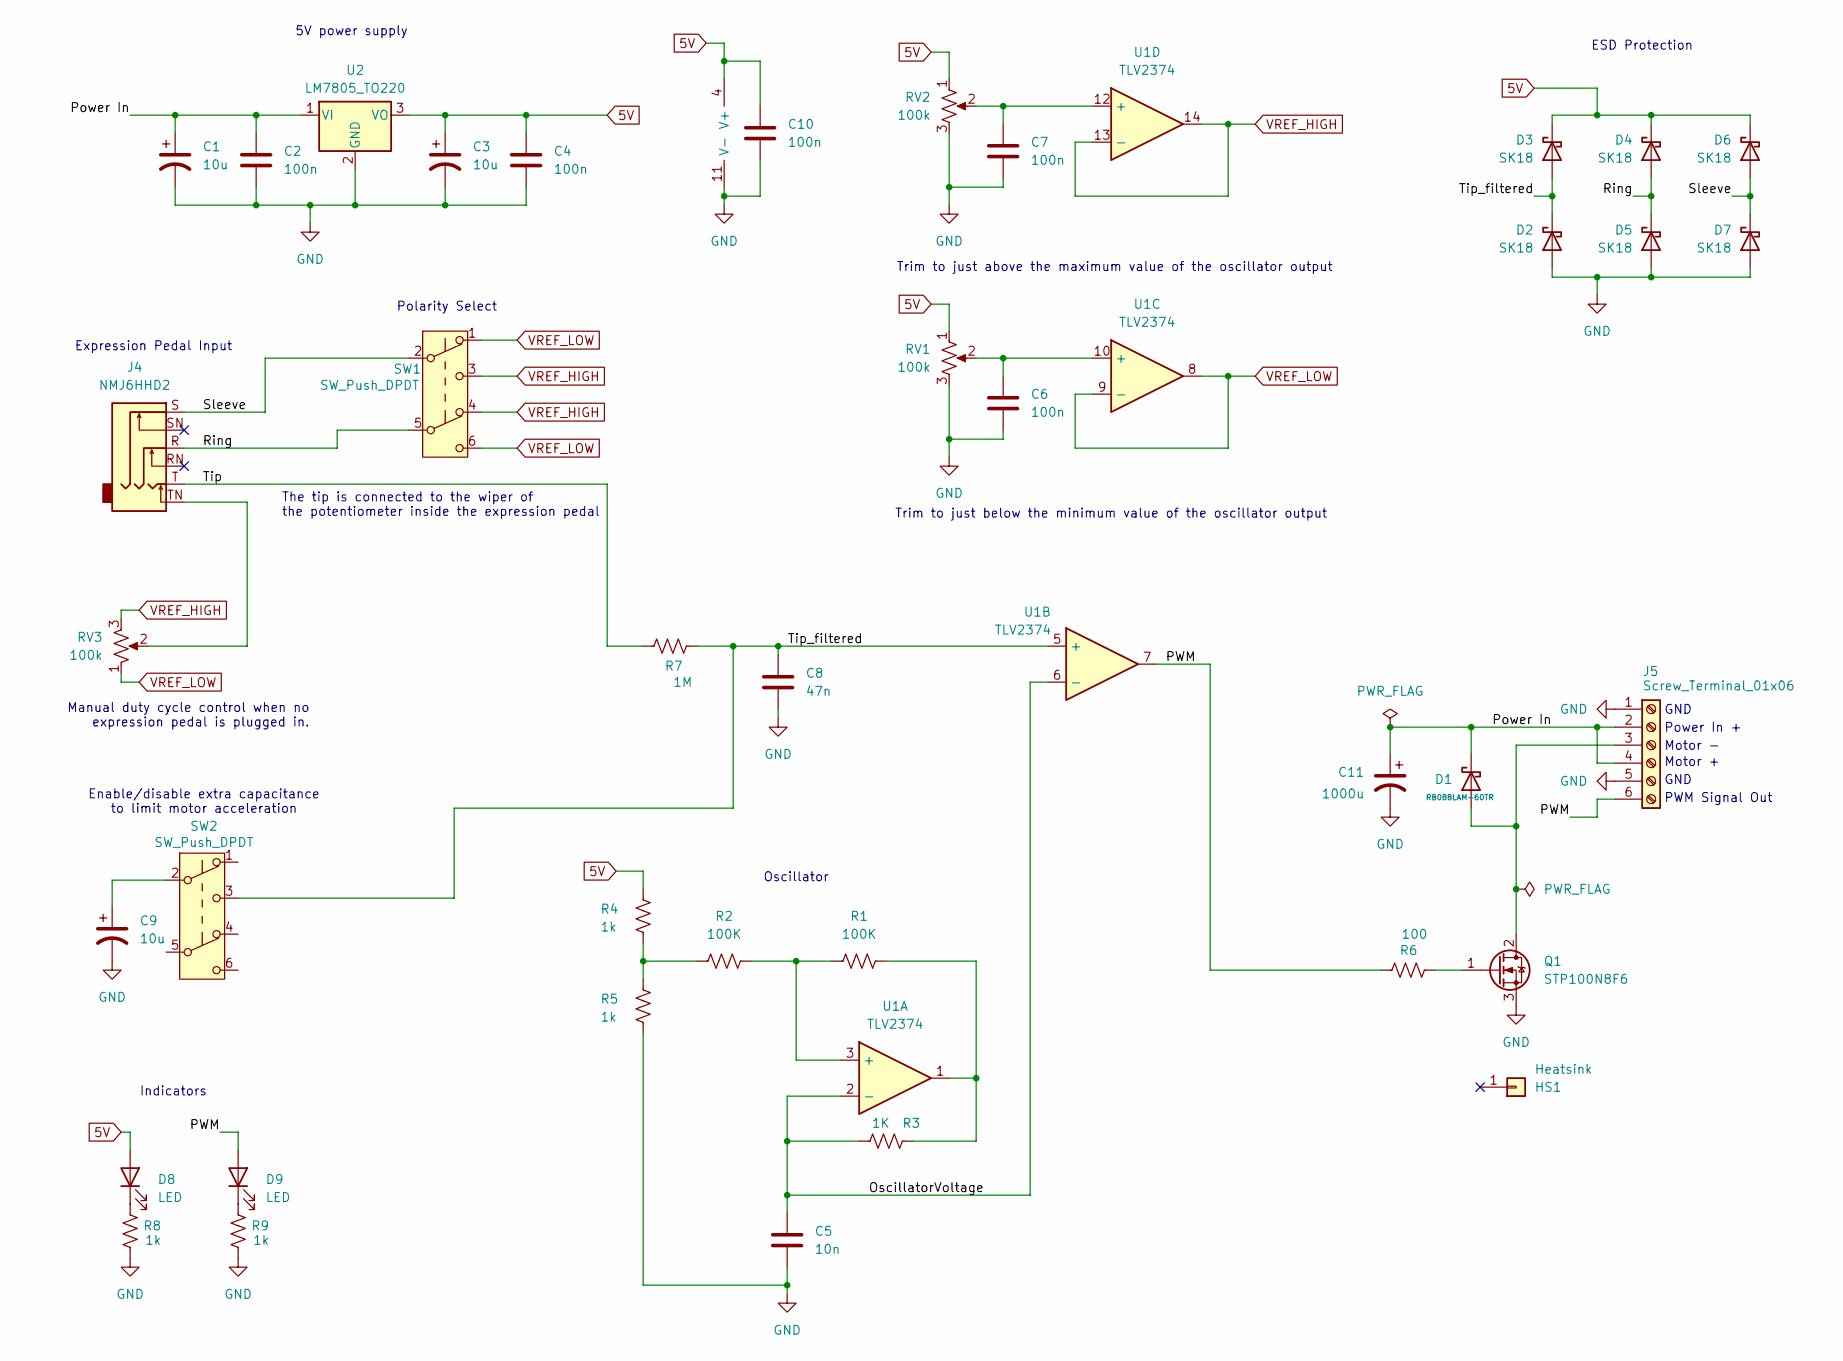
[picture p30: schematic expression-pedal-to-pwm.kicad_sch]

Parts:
C1, C3, C9: 10u; CP_Radial_D5.0mm_P2.50mm
C2, C4, C6, C7, C10: 100n; C_0603_1608Metric_Pad1.08x0.95mm_HandSolder
C5: 10n; C_0603_1608Metric_Pad1.08x0.95mm_HandSolder
C8: 47n; C_0603_1608Metric_Pad1.08x0.95mm_HandSolder
C11: 1000u; CP_Radial_D10.0mm_P5.00mm
D1: RB088LAM-60TR; D_SOD-128
D2, D3, D4, D5, D6, D7: SK18; D_SMA
D8, D9: LED; LED_D3.0mm_Horizontal_O3.81mm_Z6.0mm
HS1: Heatsink; Heatsink_Fischer_SK104-STCB_35x13mm__2xDrill3.5mm_ScrewM3
J4: NMJ6HHD2; Jack_6.35mm_Neutrik_NMJ6HHD2_Horizontal
J5: Screw_Terminal_01x06; TerminalBlock_MetzConnect_Type086_RT03406HBLC_1x06_P3.81mm_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
Q1: STP100N8F6; TO-220-3_Vertical
R1, R2: 100K; R_0603_1608Metric_Pad0.98x0.95mm_HandSolder
R3: 1K; R_0603_1608Metric_Pad0.98x0.95mm_HandSolder
R4, R5, R8, R9: 1k; R_0603_1608Metric_Pad0.98x0.95mm_HandSolder
R6: 100; R_0603_1608Metric_Pad0.98x0.95mm_HandSolder
R7: 1M; R_0603_1608Metric_Pad0.98x0.95mm_HandSolder
RV1, RV2: 100k; Potentiometer_Bourns_3296W_Vertical
RV3: 100k; Potentiometer_Piher_T-16H_Single_Horizontal
SW1, SW2: SW_Push_DPDT; SW_E-Switch_EG2219_DPDT_Angled
U1: TLV2374; SOIC-14_3.9x8.7mm_P1.27mm
U2: LM7805_TO220; TO-220-3_Vertical

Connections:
5V: C3.1, C4.1, C10.1, D3.1 (K), D4.1 (K), D6.1 (K), D8.2 (A), R4.2, RV1.1, RV2.1, U1.4 (V+), U2.3 (VO)
/OscillatorVoltage: C5.1, R3.2, U1.2 (-), U1.6 (-)
/PWM: D9.2 (A), J5.6, R6.1, U1.7
/Power In: C1.1, C2.1, C11.1, D1.1 (K), J5.2, J5.4, U2.1 (VI)
/Ring: D4.2 (A), D5.1 (K), J4.R, SW1.5 (B)
/Sleeve: D6.2 (A), D7.1 (K), J4.S, SW1.2 (B)
/Tip: J4.T, R7.2
/Tip_filtered: C8.1, D2.1 (K), D3.2 (A), R7.1, SW2.3 (C), U1.5 (+)
GND: C1.2, C2.2, C3.2, C4.2, C5.2, C6.2, C7.2, C8.2, C9.2, C10.2, C11.2, D2.2 (A), D5.2 (A), D7.2 (A), J5.1, J5.5, Q1.3 (S), R5.1, R8.1, R9.1, RV1.3, RV2.3, U1.11 (V-), U2.2 (GND)
unnamed: C9.1, SW2.2 (B)
unnamed: D1.2 (A), J5.3, Q1.2 (D)
unnamed: D8.1 (K), R8.2
unnamed: D9.1 (K), R9.2
unnamed: J4.TN, RV3.2
unnamed: Q1.1 (G), R6.2
unnamed: R1.2, R3.1, U1.1
unnamed: R2.1, R4.1, R5.2
unnamed: R1.1, R2.2, U1.3 (+)
unnamed: C6.1, RV1.2, U1.10 (+)
unnamed: C7.1, RV2.2, U1.12 (+)
VREF_HIGH: RV3.3, SW1.3 (C), SW1.4 (A), U1.13 (-), U1.14
VREF_LOW: RV3.1, SW1.1 (A), SW1.6 (C), U1.8, U1.9 (-)

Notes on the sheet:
ESD Protection
The tip is connected to the wiper of the potentiometer inside the expression pedal
GND
Power In +
Manual duty cycle control when no expression pedal is plugged in.
5V power supply
Indicators
Motor -
Motor +
Oscillator
Expression Pedal Input
PWM Signal Out
Trim to just above the maximum value of the oscillator output
Trim to just below the minimum value of the oscillator output
Polarity Select
Enable/disable extra capacitance to limit motor acceleration

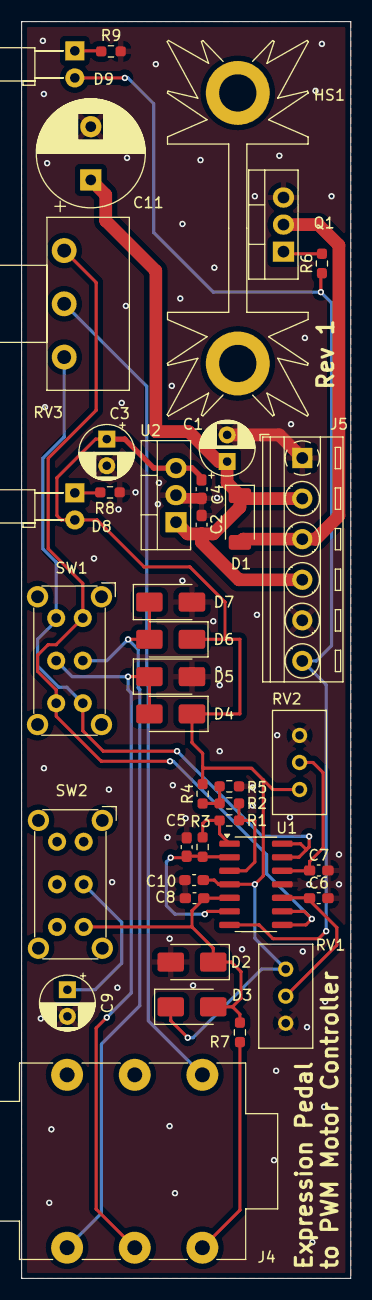
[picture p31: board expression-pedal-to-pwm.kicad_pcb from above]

Board: 2 copper layers, 30.9 x 118.0 mm, 40 parts (0 on the bottom side), 22 nets.

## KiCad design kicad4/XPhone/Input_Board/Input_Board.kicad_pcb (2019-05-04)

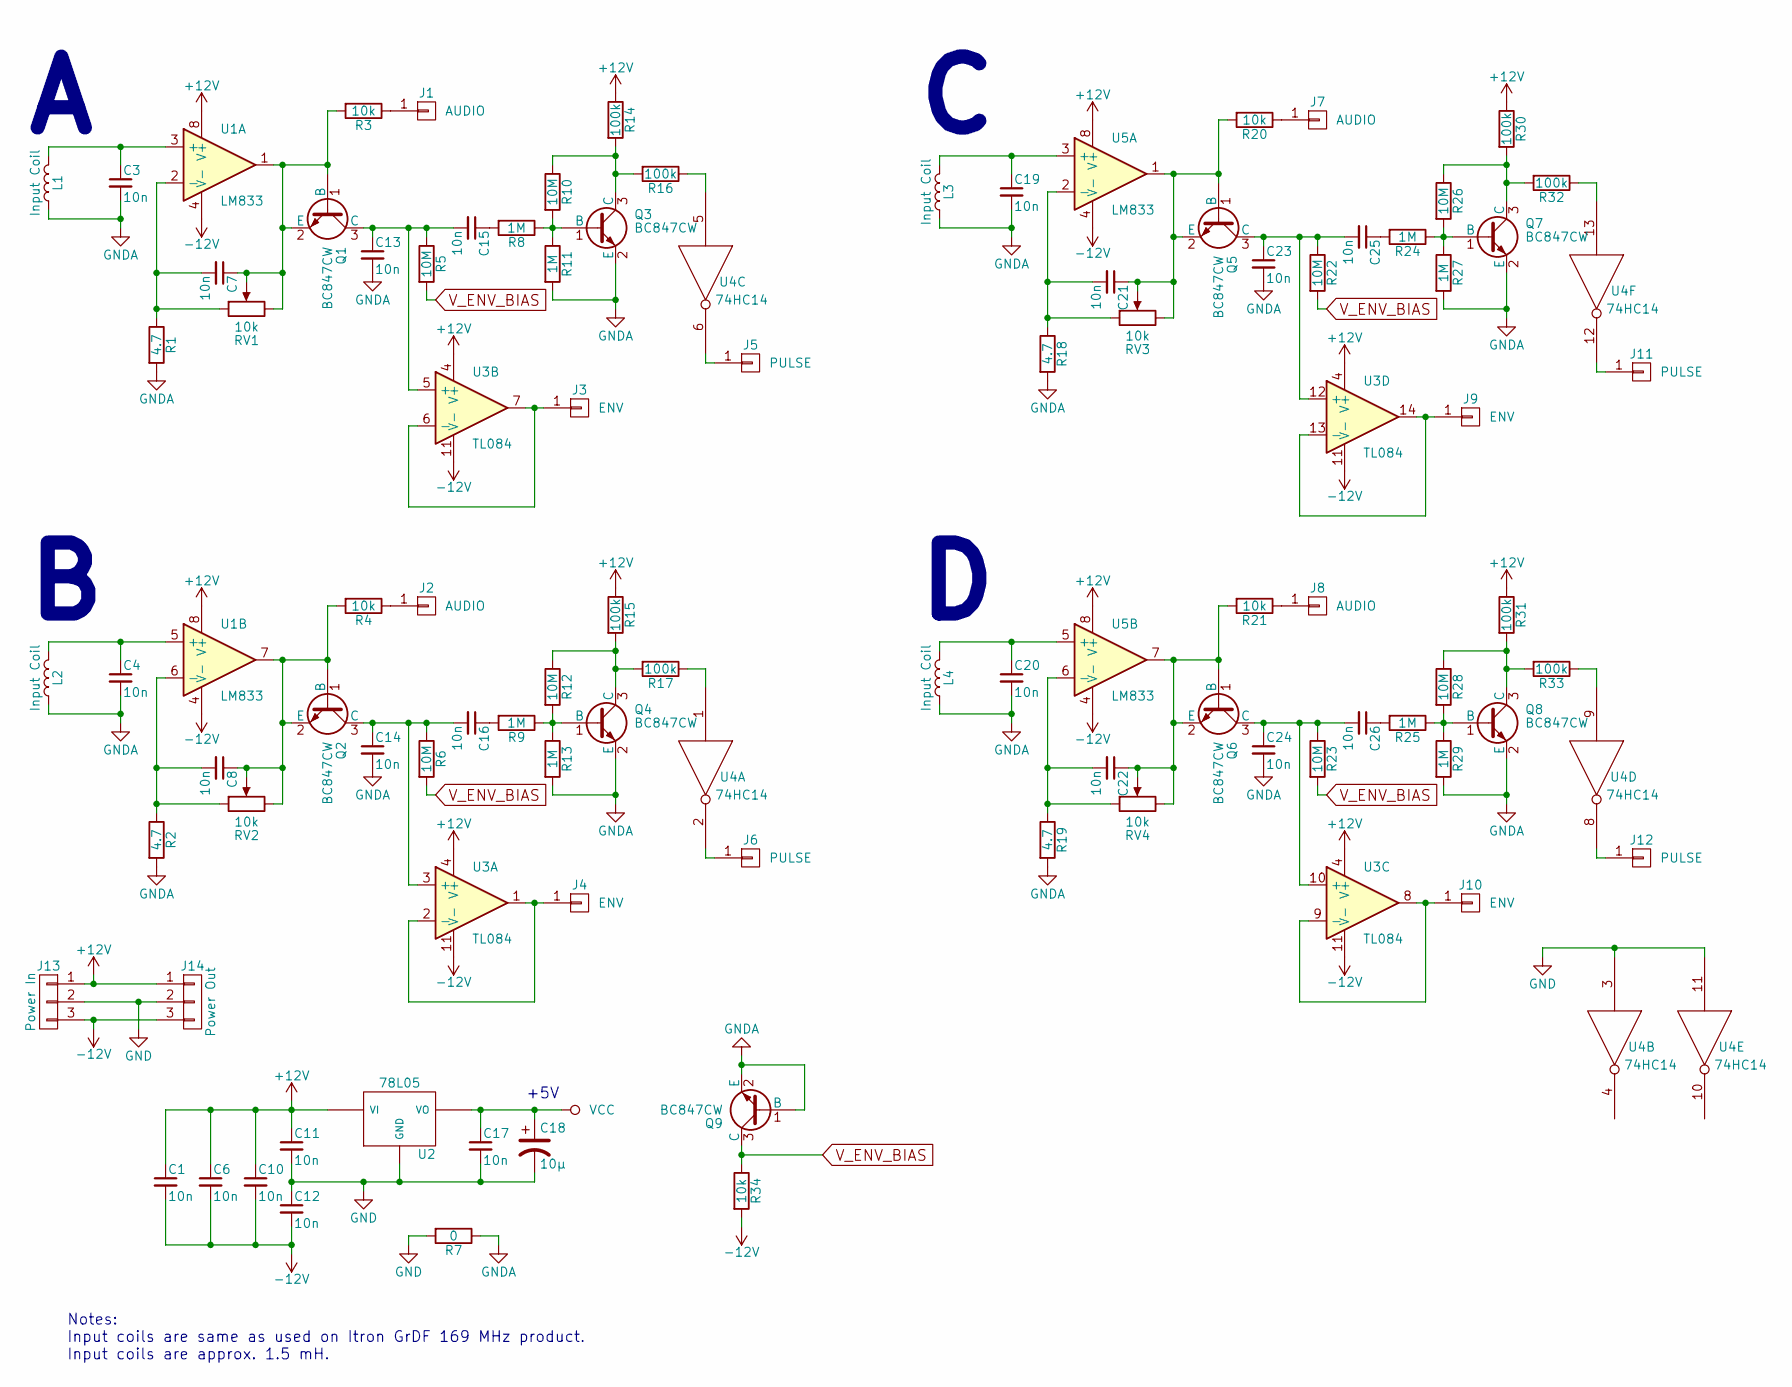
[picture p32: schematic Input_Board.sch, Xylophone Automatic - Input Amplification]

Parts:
C1, C3, C4, C6, C7, C8, C10, C11, C12, C13, C14, C15, C16, C17, C19, C20, C21, C22, C23, C24, C25, C26: 10n; C_0603_HandSoldering
C18: 10µ; CP_Tantalum_Case-B_EIA-3528-21_Wave
J1, J2, J7, J8: AUDIO; Pin_Header_Straight_1x01_Pitch2.54mm
J3, J4, J9, J10: ENV; Pin_Header_Straight_1x01_Pitch2.54mm
J5, J6, J11, J12: PULSE; Pin_Header_Straight_1x01_Pitch2.54mm
J13: Power In; Pin_Header_Straight_1x03_Pitch2.54mm
J14: Power Out; Pin_Header_Straight_1x03_Pitch2.54mm
L1, L2, L3, L4: Input Coil; Pin_Header_Straight_1x02_Pitch2.54mm
Q1, Q2, Q3, Q4, Q5, Q6, Q7, Q8, Q9: BC847CW; SOT-323_SC-70_Handsoldering
R1, R2, R18, R19: 4.7; R_0603_HandSoldering
R3, R4, R20, R21, R34: 10k; R_0603_HandSoldering
R5, R6, R10, R12, R22, R23, R26, R28: 10M; R_0603_HandSoldering
R7: 0; R_0603_HandSoldering
R8, R9, R11, R13, R24, R25, R27, R29: 1M; R_0603_HandSoldering
R14, R15, R16, R17, R30, R31, R32, R33: 100k; R_0603_HandSoldering
RV1, RV2, RV3, RV4: 10k; Potentiometer_Trimmer_Bourns_3296W
U1, U5: LM833; DIP-8_W7.62mm
U2: 78L05; TO-92_Inline_Wide
U3: TL084; SOIC-14_N
U4: 74HC14; DIP-14_W7.62mm

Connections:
+12V: C1.1, C6.1, C10.1, C11.1, J13.1, J14.1, R14.1, R15.1, R30.1, R31.1, U1.8 (V+), U2.3 (VI), U3.4 (V+), U5.8 (V+)
-12V: C1.2, C6.2, C10.2, C12.2, J13.3, J14.3, R34.2, U1.4 (V-), U3.11 (V-), U5.4 (V-)
GND: C11.2, C12.1, C17.2, C18.2, J13.2, J14.2, R7.2, U2.2 (GND), U4.3, U4.7 (GND), U4.11
GNDA: C3.2, C4.2, C13.2, C14.2, C19.2, C20.2, C23.2, C24.2, L1.1, L2.1, L3.1, L4.1, Q3.2 (E), Q4.2 (E), Q7.2 (E), Q8.2 (E), Q9.1 (B), Q9.2 (E), R1.2, R2.2, R7.1, R11.2, R13.2, R18.2, R19.2, R27.2, R29.2
unnamed: C3.1, L1.2, U1.3 (+)
unnamed: C4.1, L2.2, U1.5 (+)
unnamed: C7.1, Q1.1 (B), Q1.2 (E), R3.2, RV1.2, RV1.3, U1.1
unnamed: C7.2, R1.1, RV1.1, U1.2 (-)
unnamed: C8.1, Q2.1 (B), Q2.2 (E), R4.2, RV2.2, RV2.3, U1.7
unnamed: C8.2, R2.1, RV2.1, U1.6 (-)
unnamed: C13.1, C15.2, Q1.3 (C), R5.1, U3.5 (+)
unnamed: C14.1, C16.2, Q2.3 (C), R6.1, U3.3 (+)
unnamed: C15.1, R8.2
unnamed: C16.1, R9.2
unnamed: C19.1, L3.2, U5.3 (+)
unnamed: C20.1, L4.2, U5.5 (+)
unnamed: C21.1, Q5.1 (B), Q5.2 (E), R20.2, RV3.2, RV3.3, U5.1
unnamed: C21.2, R18.1, RV3.1, U5.2 (-)
unnamed: C22.1, Q6.1 (B), Q6.2 (E), R21.2, RV4.2, RV4.3, U5.7
unnamed: C22.2, R19.1, RV4.1, U5.6 (-)
unnamed: C23.1, C25.2, Q5.3 (C), R22.1, U3.12 (+)
unnamed: C24.1, C26.2, Q6.3 (C), R23.1, U3.10 (+)
unnamed: C25.1, R24.2
unnamed: C26.1, R25.2
unnamed: J1.1, R3.1
unnamed: J2.1, R4.1
unnamed: J3.1, U3.6 (-), U3.7
unnamed: J4.1, U3.1, U3.2 (-)
unnamed: J5.1, U4.6
unnamed: J6.1, U4.2
unnamed: J7.1, R20.1
unnamed: J8.1, R21.1
unnamed: J9.1, U3.13 (-), U3.14
unnamed: J10.1, U3.8, U3.9 (-)
unnamed: J11.1, U4.12
unnamed: J12.1, U4.8
unnamed: Q3.1 (B), R8.1, R10.2, R11.1
unnamed: Q3.3 (C), R10.1, R14.2, R16.2
unnamed: Q4.1 (B), R9.1, R12.2, R13.1
unnamed: Q4.3 (C), R12.1, R15.2, R17.2
unnamed: Q7.1 (B), R24.1, R26.2, R27.1
unnamed: Q7.3 (C), R26.1, R30.2, R32.2
unnamed: Q8.1 (B), R25.1, R28.2, R29.1
unnamed: Q8.3 (C), R28.1, R31.2, R33.2
unnamed: R16.1, U4.5
unnamed: R17.1, U4.1
unnamed: R32.1, U4.13
unnamed: R33.1, U4.9
VCC: C17.1, C18.1, U2.1 (VO), U4.14 (VCC)
V_ENV_BIAS: Q9.3 (C), R5.2, R6.2, R22.2, R23.2, R34.1

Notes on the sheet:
Notes: Input coils are same as used on Itron GrDF 169 MHz product. Input coils are approx. 1.5 mH.
+5V

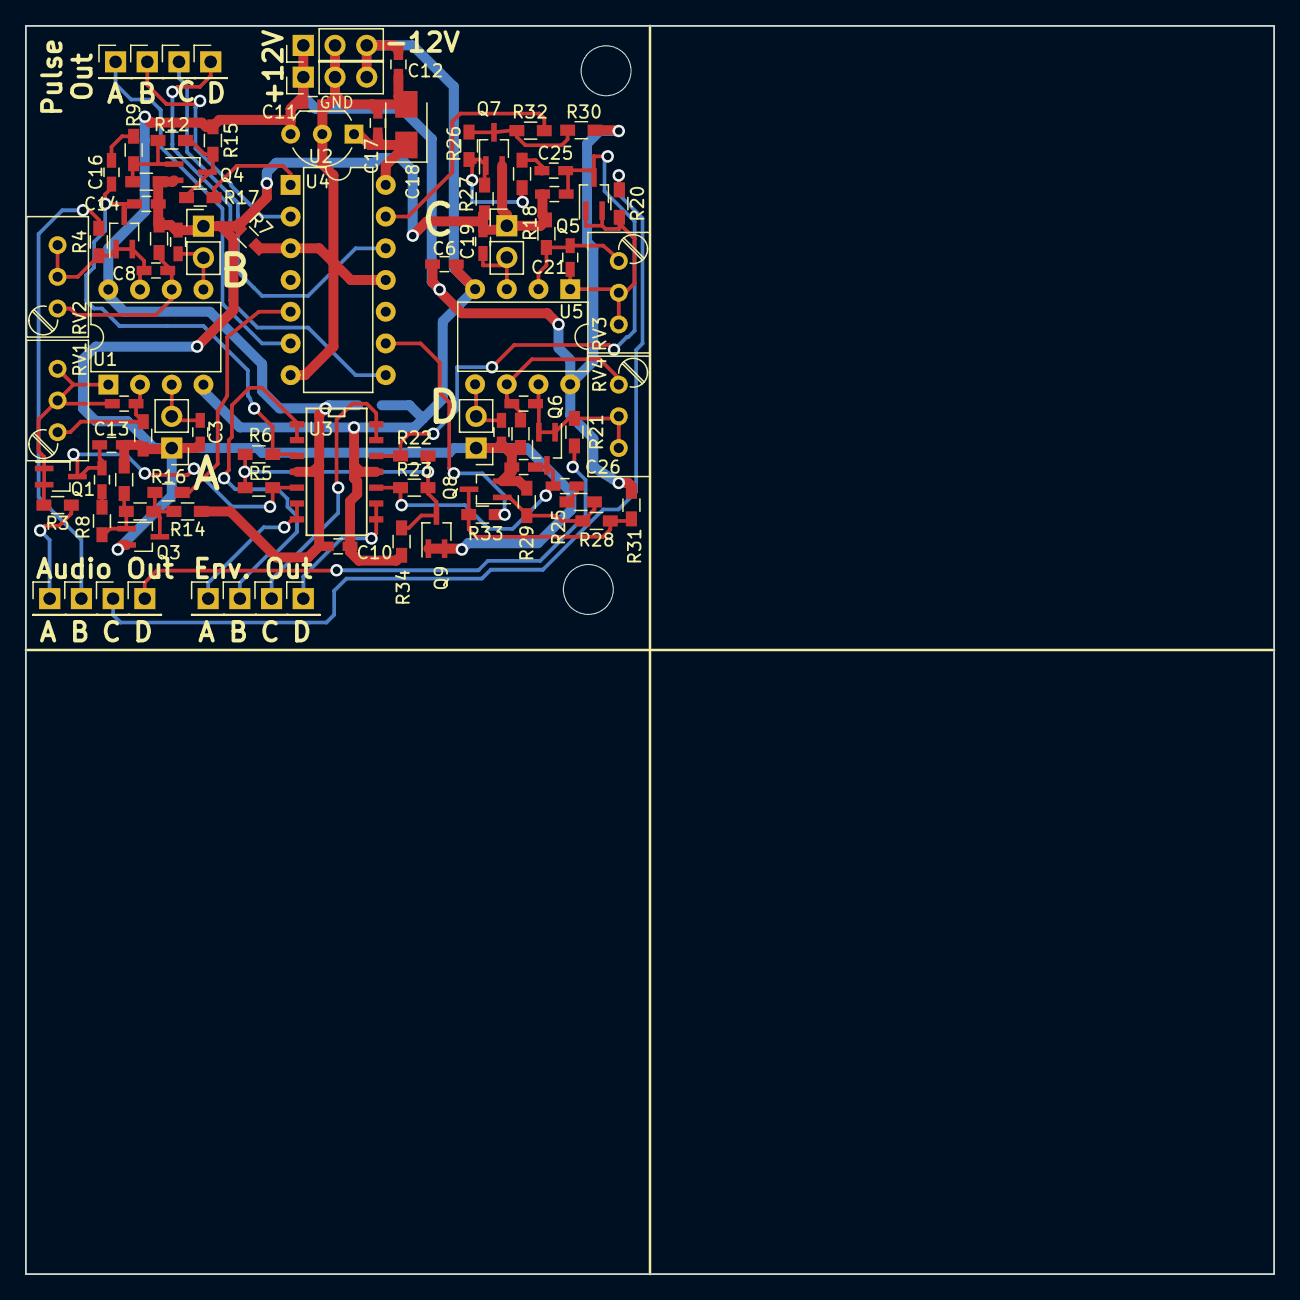
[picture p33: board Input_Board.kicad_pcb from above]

Board: 2 copper layers, 100.0 x 100.0 mm, 93 parts (1 on the bottom side), 50 nets.

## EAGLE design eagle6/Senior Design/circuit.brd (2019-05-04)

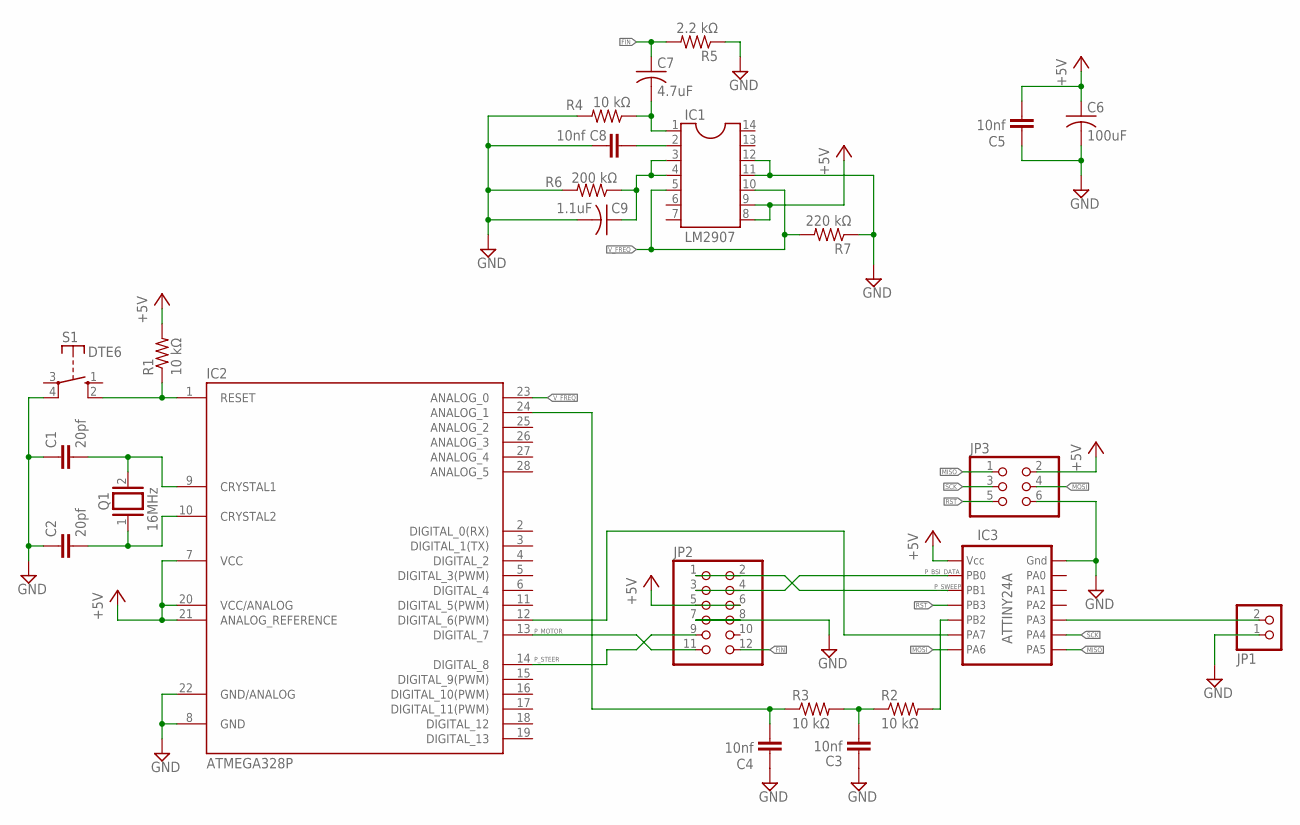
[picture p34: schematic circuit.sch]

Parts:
C1, C2: 20pf; C025-024X044
C3, C4, C5, C8: 10nf; C025-024X044
C6: 100uF; C025-050X050
C7: 4.7uF; C025-050X050
C9: 1.1uF; C025-050X050
IC1: LM2907; DIL14
IC2: ATMEGA328P; DIL28-3
IC3: ATTINY24A; TINY24A
JP1: PINHD-1X2; 1X02
JP2: PINHD-2X6; 2X06
JP3: PINHD-2X3; 2X03
Q1: 16MHz; QS
R1, R2, R3, R4: 10 kΩ; 0204V
R5: 2.2 kΩ; 0204V
R6: 200 kΩ; 0204V
R7: 220 kΩ; 0204V
S1: DTE6

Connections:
+5V: C5.2, C6.1, IC1.8, IC1.9, IC2.7 (VCC), IC2.20 (VCC/ANALOG), IC2.21 (ANALOG_REFERENCE), IC3.1, JP2.5, JP2.6, JP3.2, R1.2
DATA-READY: IC2.12 (DIGITAL_6(PWM)), IC3.6
FIN: C7.1, JP2.12, R5.2
GND: C1.1, C2.1, C3.1, C4.1, C5.1, C6.2, C8.1, C9.2, IC1.11, IC1.12, IC2.8 (GND), IC2.22 (GND/ANALOG), IC3.14, JP1.1, JP2.7, JP2.8, JP3.6, R4.2, R5.1, R6.2, R7.1, S1.4
LINE-POSITION: C4.2, IC2.24 (ANALOG_1), R3.1
MISO: IC3.8, JP3.1
MOSI: IC3.7, JP3.4
unnamed: C9.1, IC1.3, IC1.4, R6.1
unnamed: IC3.10, JP1.2
unnamed: IC3.5, R2.2
unnamed: C1.2, IC2.9 (CRYSTAL1), Q1.2
unnamed: C2.2, IC2.10 (CRYSTAL2), Q1.1
unnamed: C3.2, R2.1, R3.2
unnamed: IC2.1 (RESET), R1.1, S1.2 (S)
unnamed: C7.2, IC1.1, R4.1
unnamed: C8.2, IC1.2
P_BSI_DATA: IC3.2, JP2.3, JP2.4
P_MOTOR: IC2.13 (DIGITAL_7), JP2.11
P_STEER: IC2.14 (DIGITAL_8), JP2.9
P_SWEEP: IC3.3, JP2.1, JP2.2
RST: IC3.4, JP3.5
SCK: IC3.9, JP3.3
V_FREQ: IC1.5, IC1.10, IC2.23 (ANALOG_0), R7.2

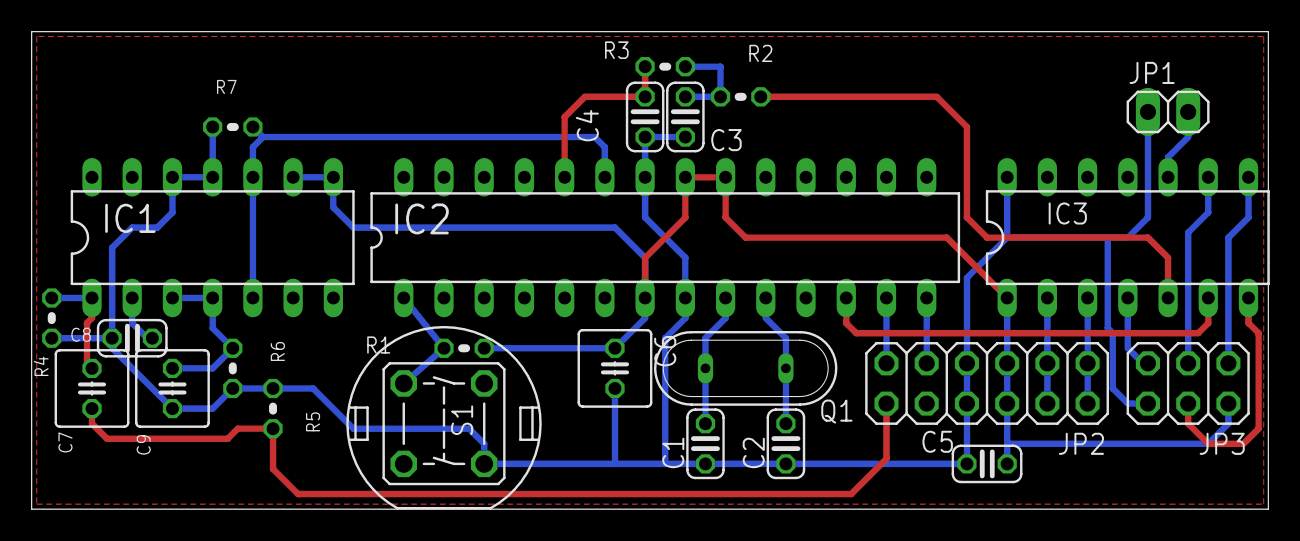
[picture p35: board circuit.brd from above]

Board: 2 copper layers, 78.1 x 30.1 mm, 24 parts (0 on the bottom side), 23 nets.

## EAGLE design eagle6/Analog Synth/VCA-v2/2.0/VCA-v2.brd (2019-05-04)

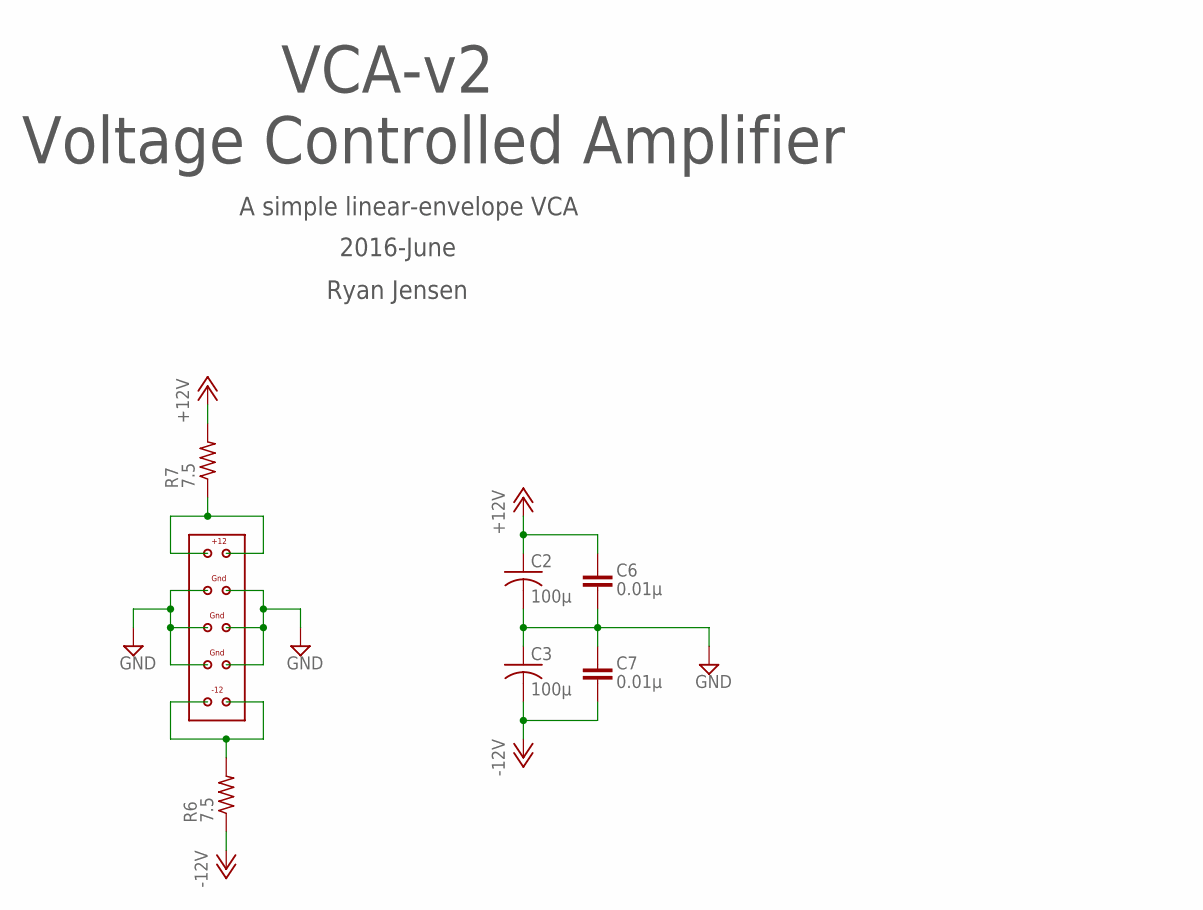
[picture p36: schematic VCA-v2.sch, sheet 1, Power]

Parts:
C2, C3: 100µ; C025-050X050
C6, C7: 0.01µ; C0603
R6, R7: 7.5; R0603
U$1: EURORACK-POWER

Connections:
+12V: C2.1, C6.1, R7.2; also elsewhere on the board
-12V: C3.2, C7.2, R6.1; also elsewhere on the board
GND: C2.2, C3.1, C6.2, C7.1, U$1.P$3, U$1.P$4, U$1.P$5, U$1.P$6, U$1.P$7, U$1.P$8; also elsewhere on the board
unnamed: R6.2, U$1.P$9, U$1.P$10
unnamed: R7.1, U$1.P$1, U$1.P$2

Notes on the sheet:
VCA-v2 Voltage Controlled Amplifier
A simple linear-envelope VCA
Ryan Jensen
2016-June

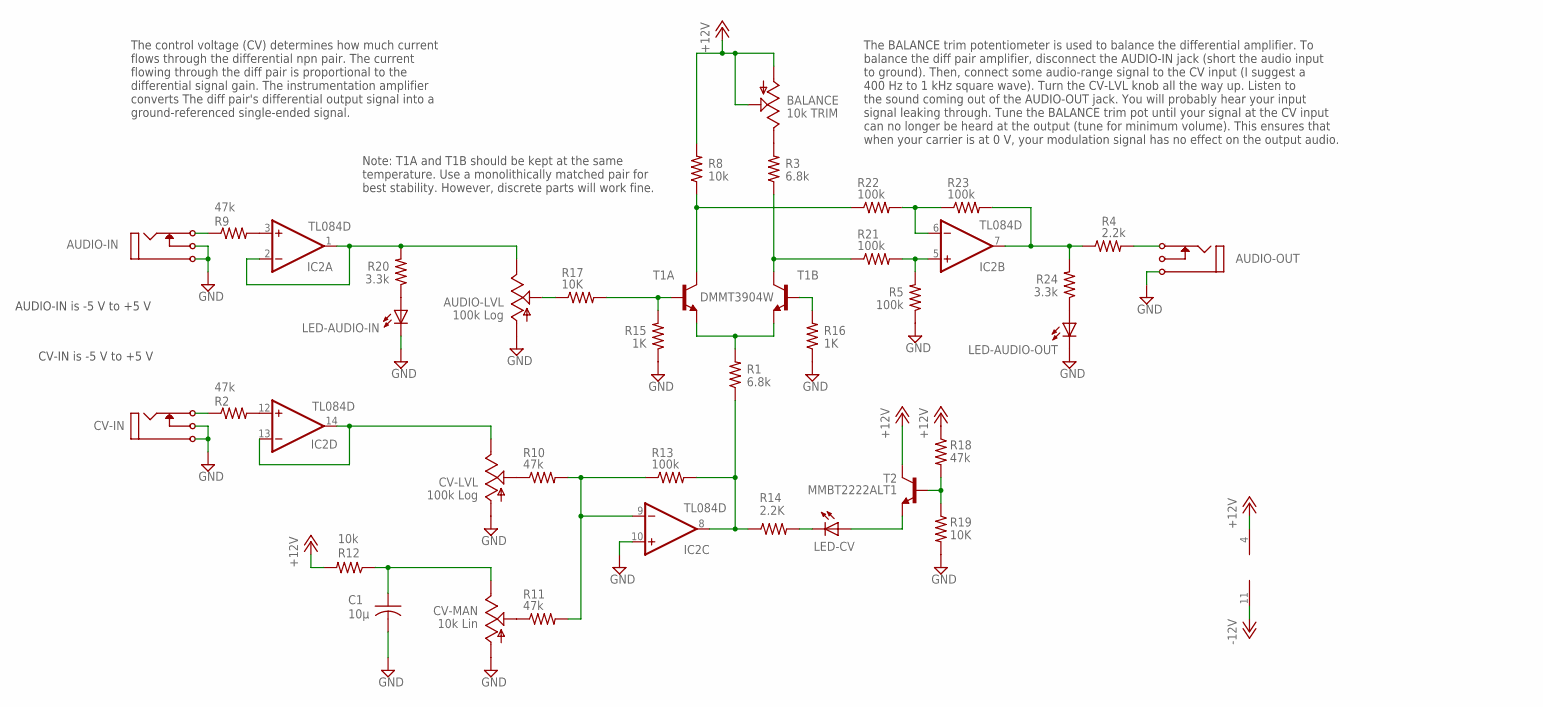
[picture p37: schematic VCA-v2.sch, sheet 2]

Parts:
AUDIO-IN: I/O; MONO_JACK
AUDIO-LVL: 100k Log; B64Y
AUDIO-OUT: I/O; MONO_JACK
BALANCE: 10k TRIM; B64Y
C1: 10µ; C025-050X050
CV-IN: I/O; MONO_JACK
CV-LVL: 100k Log; B64Y
CV-MAN: 10k Lin; B64Y
IC2: TL084D; SO14
LED-AUDIO-IN: TLLG4400; LED3MM
LED-AUDIO-OUT: TLLG4400; LED3MM
LED-CV: TLLG4400; LED3MM
R1, R3: 6.8k; R0603
R2, R9, R10, R11, R18: 47k; R0603
R4: 2.2k; R0603
R5, R13, R21, R22, R23: 100k; R0603
R8, R12: 10k; R0603
R14: 2.2K; R0603
R15, R16: 1K; R0603
R17, R19: 10K; R0603
R20, R24: 3.3k; R0603
T1: DMMT3904W; SOT363
T2: MMBT2222ALT1; SOT23-BEC

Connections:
+12V: BALANCE.A, BALANCE.S, IC2.4 (V+), R8.2, R12.2, R18.1, T2.C; also elsewhere on the board
-12V: IC2.11 (V-); also elsewhere on the board
GND: AUDIO-IN.P$1, AUDIO-IN.P$3 (P3), AUDIO-LVL.A, AUDIO-OUT.P$1, C1.2, CV-IN.P$1, CV-IN.P$3 (P3), CV-LVL.A, CV-MAN.A, IC2.10 (+IN), LED-AUDIO-IN.K (C), LED-AUDIO-OUT.K (C), R5.1, R15.1, R16.1, R19.2; also elsewhere on the board
LED_SUPPLY: LED-CV.A, T2.E
unnamed: IC2.8 (OUT), R1.1, R13.2, R14.1
unnamed: BALANCE.E, R3.2
unnamed: IC2.12 (+IN), R2.2
unnamed: CV-LVL.E, IC2.13 (-IN), IC2.14 (OUT)
unnamed: CV-IN.P$2 (P2), R2.1
unnamed: AUDIO-IN.P$2 (P2), R9.1
unnamed: IC2.3 (+IN), R9.2
unnamed: AUDIO-LVL.E, IC2.1 (OUT), IC2.2 (-IN), R20.2
unnamed: CV-LVL.S, R10.1
unnamed: LED-CV.K (C), R14.2
unnamed: CV-MAN.S, R11.1
unnamed: C1.1, CV-MAN.E, R12.1
unnamed: R1.2, T1.4 (E), T1.5 (E)
unnamed: R15.2, R17.2, T1.1 (B)
unnamed: IC2.9 (-IN), R10.2, R11.2, R13.1
unnamed: AUDIO-LVL.S, R17.1
unnamed: R16.2, T1.2 (B)
unnamed: R18.2, R19.1, T2.B
unnamed: LED-AUDIO-IN.A, R20.1
unnamed: LED-AUDIO-OUT.A, R24.1
unnamed: R8.1, R22.1, T1.6 (C)
unnamed: R3.1, R21.1, T1.3 (C)
unnamed: IC2.5 (+IN), R5.2, R21.2
unnamed: IC2.6 (-IN), R22.2, R23.1
unnamed: IC2.7 (OUT), R4.1, R23.2, R24.2
unnamed: AUDIO-OUT.P$2 (P2), R4.2

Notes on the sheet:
The control voltage (CV) determines how much current flows through the differential npn pair. The current flowing through the diff pair is proportional to the differential signal gain. The instrumentation amplifier converts The diff pair's differential output signal into a ground-referenced single-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
The BALANCE trim potentiometer is used to balance the differential amplifier. To balance the diff pair amplifier, disconnect the AUDIO-IN jack (short the audio input to ground). Then, connect some audio-range signal to the CV input (I suggest a 400 Hz to 1 kHz square wave). Turn the CV-LVL knob all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
Note: T1A and T1B should be kept at the same temperature. Use a monolithically matched pair for best stability. However, discrete parts will work fine.
AUDIO-IN is -5 V to +5 V
CV-IN is -5 V to +5 V

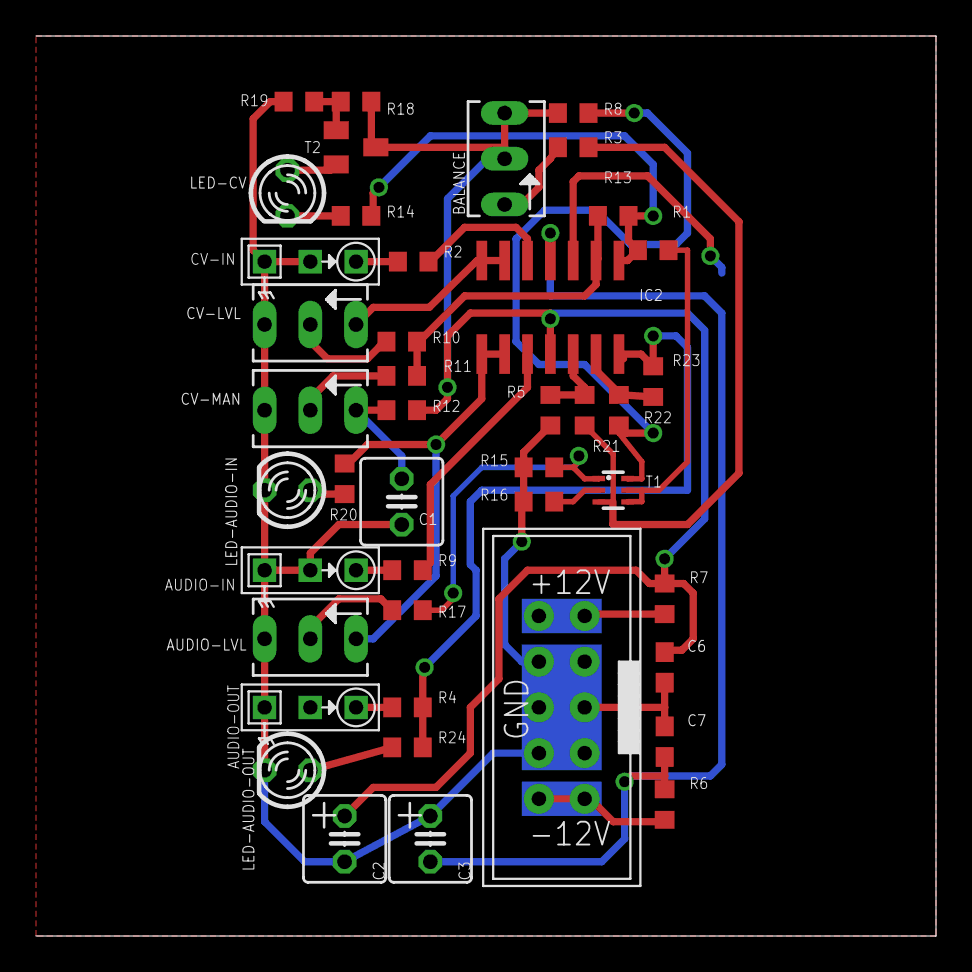
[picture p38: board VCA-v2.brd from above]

Board: 2 copper layers, 50.0 x 50.0 mm, 43 parts (0 on the bottom side), 32 nets.

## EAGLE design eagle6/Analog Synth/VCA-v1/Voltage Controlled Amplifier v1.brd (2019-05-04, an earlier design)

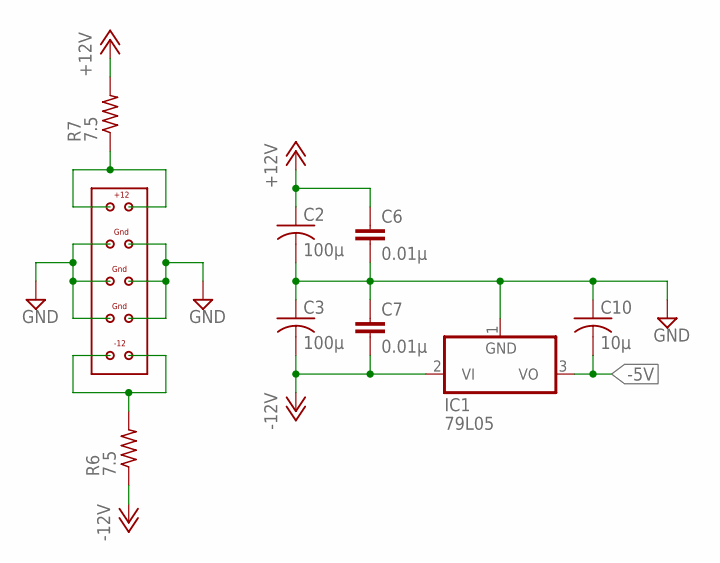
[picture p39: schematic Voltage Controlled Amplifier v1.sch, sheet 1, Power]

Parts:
C2, C3: 100µ; C025-050X050
C6, C7: 0.01µ; C2.5-2
C10: 10µ; C025-050X050
IC1: 79L05; TO92
R6, R7: 7.5; 0204/7
U$1: EURORACK-POWER

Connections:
+12V: C2.1, C6.1, R7.2; also elsewhere on the board
-5V: C10.2, IC1.3 (VO); also elsewhere on the board
-12V: C3.2, C7.2, IC1.2 (VI), R6.1; also elsewhere on the board
GND: C2.2, C3.1, C6.2, C7.1, C10.1, IC1.1 (GND), U$1.P$3, U$1.P$4, U$1.P$5, U$1.P$6, U$1.P$7, U$1.P$8; also elsewhere on the board
unnamed: R6.2, U$1.P$9, U$1.P$10
unnamed: R7.1, U$1.P$1, U$1.P$2

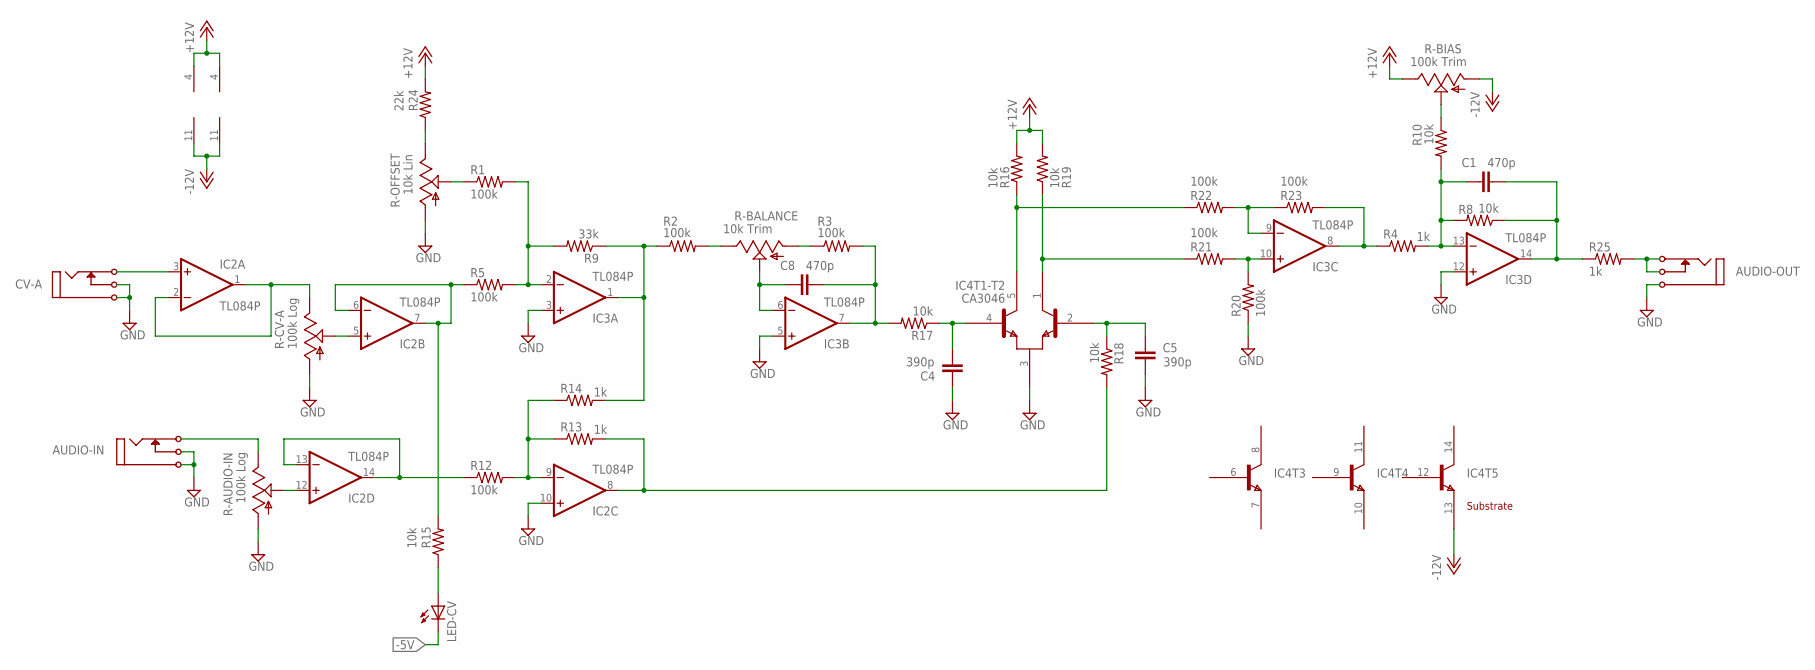
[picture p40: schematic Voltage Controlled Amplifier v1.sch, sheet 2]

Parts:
AUDIO-IN: I/O; MONO_JACK
AUDIO-OUT: I/O; MONO_JACK
C1, C8: 470p; C2.5-2
C4, C5: 390p; C2.5-2
CV-A: I/O; MONO_JACK
IC2, IC3: TL084P; DIL14
IC4: CA3046; DIL14
LED-CV: TLLG4400; LED3MM
R1, R2, R3, R5, R12, R20, R21, R22, R23: 100k; 0204V
R4, R13, R14: 1k; 0204V
R8, R10, R15, R16, R17, R19: 10k; 0204V
R9: 33k; 0204V
R18: 10k; 0204/7
R24: 22k; 0204V
R25: 1k; 0204/7
R-AUDIO-IN: 100k Log; B64Y
R-BALANCE: 10k Trim; B64Y
R-BIAS: 100k Trim; B64Y
R-CV-A: 100k Log; B64Y
R-OFFSET: 10k Lin; B64Y

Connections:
+12V: IC2.4 (V+), IC3.4 (V+), R16.2, R19.2, R24.2, R-BIAS.E; also elsewhere on the board
-5V: LED-CV.K (C); also elsewhere on the board
-12V: IC2.11 (V-), IC3.11 (V-), IC4.13 (E), R-BIAS.A; also elsewhere on the board
GND: AUDIO-IN.P$1, AUDIO-IN.P$3 (P3), AUDIO-OUT.P$1, C4.1, C5.2, CV-A.P$1, CV-A.P$3 (P3), IC2.10 (+IN), IC3.3 (+IN), IC3.5 (+IN), IC3.12 (+IN), IC4.3 (E), R20.1, R-AUDIO-IN.A, R-CV-A.A, R-OFFSET.A; also elsewhere on the board
unnamed: IC2.6 (-IN), IC2.7 (OUT), R5.1, R15.2
unnamed: C4.2, IC4.4 (B2), R17.1
unnamed: CV-A.P$2 (P2), IC2.3 (+IN)
unnamed: IC2.1 (OUT), IC2.2 (-IN), R-CV-A.E
unnamed: R2.2, R-BALANCE.E
unnamed: IC3.2 (-IN), R1.2, R5.2, R9.2
unnamed: R3.1, R-BALANCE.A
unnamed: AUDIO-IN.P$2 (P2), R-AUDIO-IN.E
unnamed: R10.1, R-BIAS.S
unnamed: LED-CV.A, R15.1
unnamed: R1.1, R-OFFSET.S
unnamed: IC2.5 (+IN), R-CV-A.S
unnamed: IC3.1 (OUT), R2.1, R9.1, R14.2
unnamed: IC2.13 (-IN), IC2.14 (OUT), R12.1
unnamed: IC2.12 (+IN), R-AUDIO-IN.S
unnamed: C1.1, IC3.13 (-IN), R4.2, R8.2, R10.2
unnamed: C5.1, IC4.2 (B1), R18.1
unnamed: IC2.9 (-IN), R12.2, R13.1, R14.1
unnamed: C8.2, IC3.7 (OUT), R3.2, R17.2
unnamed: IC4.5 (C2), R16.1, R22.1
unnamed: C8.1, IC3.6 (-IN), R-BALANCE.S
unnamed: IC4.1 (C1), R19.1, R21.1
unnamed: IC2.8 (OUT), R13.2, R18.2
unnamed: IC3.10 (+IN), R20.2, R21.2
unnamed: IC3.9 (-IN), R22.2, R23.1
unnamed: IC3.8 (OUT), R4.1, R23.2
unnamed: AUDIO-OUT.P$2 (P2), AUDIO-OUT.P$3 (P3), R25.2
unnamed: C1.2, IC3.14 (OUT), R8.1, R25.1
unnamed: R24.1, R-OFFSET.E

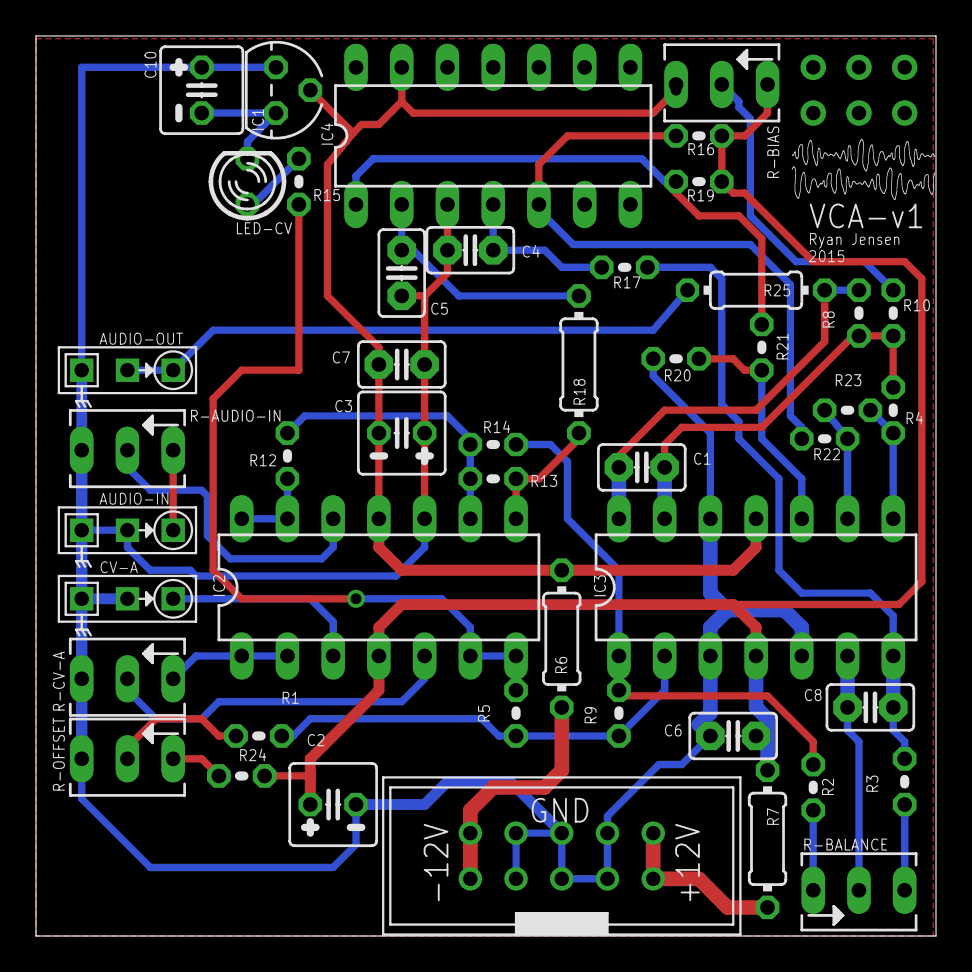
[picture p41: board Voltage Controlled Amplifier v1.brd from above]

Board: 2 copper layers, 50.0 x 50.0 mm, 47 parts (0 on the bottom side), 35 nets.

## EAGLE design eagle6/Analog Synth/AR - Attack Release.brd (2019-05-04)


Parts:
C2, C3: 100µ; C025-050X050
C4, C5: 10µ; C025-050X050
C6, C7: 0.01µ; C2.5-2
IC1: 78L05Z; TO92
IC3: 79L05Z; TO92
R6, R7: 7.5; 0204/7
U$3, U$7: POWER_CONNECTOR_4_RGBB

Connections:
5V-REG: C4.1, C6.1, IC1.1 (VO); also elsewhere on the board
+12V: C2.1, IC1.3 (VI), R7.2; also elsewhere on the board
-5V-REG: C5.2, C7.2, IC3.3 (VO); also elsewhere on the board
-12V: C3.2, IC3.2 (VI), R6.1; also elsewhere on the board
GND: C2.2, C3.1, C4.2, C5.1, C6.2, C7.1, IC1.2 (GND), IC3.1 (GND), U$3.GND, U$7.GND; also elsewhere on the board
unnamed: R7.1, U$3.+12, U$7.+12
unnamed: U$3.+5, U$7.+5
unnamed: R6.2, U$3.-12, U$7.-12


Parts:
C1: 1µ; C025-050X050
C8: 33µ; C025-050X050
C9: 1000u; C025-050X050
CV-OUT: I/O; MONO_JACK
D1: 1N4148; DO35-7
IC2: TL084P; DIL14
OFFSET-IN: I/O; MONO_JACK
R1, R2, R3, R8, R9, R10, R12, R14, R15: 100k; 0204/7
R4, R5: 100k; B64Y
R11, R13: 10k; B64Y
R17: 1k; 0204/7
S1: 255SB
SPEED: 255SB
T1: 2N3904; TO92
TRIG-IN: I/O; MONO_JACK
U$1, U$2, U$4: 2N7000

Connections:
5V-REG: R13.E, U$4.D; also elsewhere on the board
+5V: R2.2
+12V: R3.2; also elsewhere on the board
+12V1: C8.1, SPEED.3 (S)
-5V-REG: R13.A; also elsewhere on the board
GND: C1.2, C8.2, C9.2, CV-OUT.P$1, D1.A, IC2.3 (+IN), IC2.10 (+IN), OFFSET-IN.P$1, OFFSET-IN.P$3 (P3), R11.E, T1.3 (E), TRIG-IN.P$1, TRIG-IN.P$3 (P3), U$1.S, U$2.S; also elsewhere on the board
unnamed: R1.1, TRIG-IN.P$2 (P2)
unnamed: D1.C, R1.2, T1.2 (B)
unnamed: R2.1, T1.1 (C), U$1.G, U$2.G
unnamed: R3.1, U$1.D, U$4.G
unnamed: IC2.6 (-IN), IC2.7 (OUT), R11.A
unnamed: R5.E, U$2.D
unnamed: C1.1, IC2.5 (+IN), R4.E, R4.S, R5.A, R5.S, SPEED.2
unnamed: R4.A, U$4.S
unnamed: IC2.13 (-IN), IC2.14 (OUT), R12.1
unnamed: IC2.1 (OUT), R10.2, S1.3 (S)
unnamed: R9.2, R11.S, S1.1 (O)
unnamed: IC2.2 (-IN), R9.1, R10.1
unnamed: R8.1, S1.2
unnamed: IC2.9 (-IN), R8.2, R12.2, R14.2, R15.1
unnamed: R13.S, R14.1
unnamed: IC2.8 (OUT), R15.2, R17.1
unnamed: CV-OUT.P$2 (P2), R17.2
unnamed: C9.1, SPEED.1 (O)
unnamed: IC2.12 (+IN), OFFSET-IN.P$2 (P2)
V+: IC2.4 (V+); also elsewhere on the board
V-: IC2.11 (V-); also elsewhere on the board


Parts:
IC4: TL084P; DIL14
Q1: 2N5485; TO92-
R16, R18, R19, R25: 100k; 0204/7
R20, R23: 1k; 0204/7
R21: 220k; 0204/7
R22: 100k; B64Y
R24: 10k; 0204/7
R26: 68.8k; 0204/7
V-CTRL: I/O; MONO_JACK
V-IN: I/O; MONO_JACK
V-OUT: I/O; MONO_JACK

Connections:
-12V: R21.1; also elsewhere on the board
GND: R18.1, R23.1, R24.1, V-CTRL.P$1, V-CTRL.P$3 (P3), V-IN.P$1, V-IN.P$3 (P3), V-OUT.P$1; also elsewhere on the board
unnamed: IC4.2 (-IN), R22.E
unnamed: IC4.1 (OUT), R22.S, R25.1
unnamed: IC4.9 (-IN), R16.2, R18.2
unnamed: IC4.8 (OUT), R16.1, R19.2
unnamed: Q1.1 (G), R19.1
unnamed: R20.2, V-OUT.P$2 (P2)
unnamed: R22.A, R23.2
unnamed: IC4.5 (+IN), V-IN.P$2 (P2)
unnamed: IC4.6 (-IN), IC4.7 (OUT), Q1.3 (D), R26.2
unnamed: IC4.3 (+IN), V-CTRL.P$2 (P2)
unnamed: IC4.12 (+IN), Q1.2 (S), R24.2
unnamed: IC4.10 (+IN), R21.2, R25.2, R26.1
unnamed: IC4.13 (-IN), IC4.14 (OUT), R20.1
V+: IC4.4 (V+); also elsewhere on the board
V-: IC4.11 (V-); also elsewhere on the board

Board: 2 copper layers, 55 parts (0 on the bottom side), 43 nets, no tracks yet.

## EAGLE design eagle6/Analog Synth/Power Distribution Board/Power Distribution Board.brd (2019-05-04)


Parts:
JP1, JP2, JP3, JP4, JP5, JP6, JP7, JP8, JP9, JP10, JP11, JP12, JP13, JP14, JP15, JP16, JP17, JP18, JP19, JP20, JP21, JP22, JP23, JP24, JP25, JP26, JP27, JP28, JP29, JP30: PINHD-2X5; 2X05

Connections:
+12V: JP1.1, JP1.2, JP2.1, JP2.2, JP3.1, JP3.2, JP4.1, JP4.2, JP5.1, JP5.2, JP6.1, JP6.2, JP7.1, JP7.2, JP8.1, JP8.2, JP9.1, JP9.2, JP10.1, JP10.2, JP11.1, JP11.2, JP12.1, JP12.2, JP13.1, JP13.2, JP14.1, JP14.2, JP15.1, JP15.2, JP16.1, JP16.2, JP17.1, JP17.2, JP18.1, JP18.2, JP19.1, JP19.2, JP20.1, JP20.2, JP21.1, JP21.2, JP22.1, JP22.2, JP23.1, JP23.2, JP24.1, JP24.2, JP25.1, JP25.2, JP26.1, JP26.2, JP27.1, JP27.2, JP28.1, JP28.2, JP29.1, JP29.2, JP30.1, JP30.2
-12V: JP1.9, JP1.10, JP2.9, JP2.10, JP3.9, JP3.10, JP4.9, JP4.10, JP5.9, JP5.10, JP6.9, JP6.10, JP7.9, JP7.10, JP8.9, JP8.10, JP9.9, JP9.10, JP10.9, JP10.10, JP11.9, JP11.10, JP12.9, JP12.10, JP13.9, JP13.10, JP14.9, JP14.10, JP15.9, JP15.10, JP16.9, JP16.10, JP17.9, JP17.10, JP18.9, JP18.10, JP19.9, JP19.10, JP20.9, JP20.10, JP21.9, JP21.10, JP22.9, JP22.10, JP23.9, JP23.10, JP24.9, JP24.10, JP25.9, JP25.10, JP26.9, JP26.10, JP27.9, JP27.10, JP28.9, JP28.10, JP29.9, JP29.10, JP30.9, JP30.10
GND: JP1.3, JP1.4, JP1.5, JP1.6, JP1.7, JP1.8, JP2.3, JP2.4, JP2.5, JP2.6, JP2.7, JP2.8, JP3.3, JP3.4, JP3.5, JP3.6, JP3.7, JP3.8, JP4.3, JP4.4, JP4.5, JP4.6, JP4.7, JP4.8, JP5.3, JP5.4, JP5.5, JP5.6, JP5.7, JP5.8, JP6.3, JP6.4, JP6.5, JP6.6, JP6.7, JP6.8, JP7.3, JP7.4, JP7.5, JP7.6, JP7.7, JP7.8, JP8.3, JP8.4, JP8.5, JP8.6, JP8.7, JP8.8, JP9.3, JP9.4, JP9.5, JP9.6, JP9.7, JP9.8, JP10.3, JP10.4, JP10.5, JP10.6, JP10.7, JP10.8, JP11.3, JP11.4, JP11.5, JP11.6, JP11.7, JP11.8, JP12.3, JP12.4, JP12.5, JP12.6, JP12.7, JP12.8, JP13.3, JP13.4, JP13.5, JP13.6, JP13.7, JP13.8, JP14.3, JP14.4, JP14.5, JP14.6, JP14.7, JP14.8, JP15.3, JP15.4, JP15.5, JP15.6, JP15.7, JP15.8, JP16.3, JP16.4, JP16.5, JP16.6, JP16.7, JP16.8, JP17.3, JP17.4, JP17.5, JP17.6, JP17.7, JP17.8, JP18.3, JP18.4, JP18.5, JP18.6, JP18.7, JP18.8, JP19.3, JP19.4, JP19.5, JP19.6, JP19.7, JP19.8, JP20.3, JP20.4, JP20.5, JP20.6, JP20.7, JP20.8, JP21.3, JP21.4, JP21.5, JP21.6, JP21.7, JP21.8, JP22.3, JP22.4, JP22.5, JP22.6, JP22.7, JP22.8, JP23.3, JP23.4, JP23.5, JP23.6, JP23.7, JP23.8, JP24.3, JP24.4, JP24.5, JP24.6, JP24.7, JP24.8, JP25.3, JP25.4, JP25.5, JP25.6, JP25.7, JP25.8, JP26.3, JP26.4, JP26.5, JP26.6, JP26.7, JP26.8, JP27.3, JP27.4, JP27.5, JP27.6, JP27.7, JP27.8, JP28.3, JP28.4, JP28.5, JP28.6, JP28.7, JP28.8, JP29.3, JP29.4, JP29.5, JP29.6, JP29.7, JP29.8, JP30.3, JP30.4, JP30.5, JP30.6, JP30.7, JP30.8


Board: 2 copper layers, 100.0 x 101.3 mm, 30 parts (0 on the bottom side), 3 nets.

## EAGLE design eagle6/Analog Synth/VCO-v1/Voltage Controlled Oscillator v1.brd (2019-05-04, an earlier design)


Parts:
C3, C4: 10 µF; C025-060X050
C6, C8, C11, C12, C13: 0.1 µF; C5B2.5
C9, C10: 100 µF; C025-060X050
IC7: 78L05; TO92
IC8: 79L05; TO92
R28, R29: 7.5 Ω; 0204/7
U$1, U$2: POWER_CONNECTOR_4_RGBB

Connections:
5V: C3.1, IC7.1 (VO); also elsewhere on the board
-5V: C4.2, IC8.3 (VO); also elsewhere on the board
GND: C3.2, C4.1, C8.1, C9.1, C10.2, C11.2, IC7.2 (GND), IC8.1 (GND), U$1.GND, U$2.GND; also elsewhere on the board
unnamed: U$1.+5, U$2.+5
unnamed: R28.2, U$1.+12, U$2.+12
unnamed: R29.1, U$1.-12, U$2.-12
V+: C6.1, C10.1, C11.1, C12.1, C13.1, IC7.3 (VI), R28.1; also elsewhere on the board
V-: C6.2, C8.2, C9.2, C12.2, C13.2, IC8.2 (VI), R29.2; also elsewhere on the board


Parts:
CV-A: I/O; MONO_JACK
CV-B: I/O; MONO_JACK
IC1: TL084P; DIL14
R20, R21, R22, R23: 100 kΩ; 0204/7
R-CV-A-MAN: 100 kΩ; B64Y
R-CV-B-ATTN: 100 kΩ; B64Y

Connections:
5V: R-CV-A-MAN.A; also elsewhere on the board
-5V: R-CV-A-MAN.E; also elsewhere on the board
CV-A: IC1.1 (OUT), IC1.2 (-IN), R21.2; also elsewhere on the board
CV-B: IC1.8 (OUT), IC1.9 (-IN), R20.2; also elsewhere on the board
CV-COMBINED: IC1.14 (OUT), R22.1; also elsewhere on the board
GND: CV-A.P$1, CV-B.P$1, CV-B.P$3 (P3), R23.1, R-CV-B-ATTN.A; also elsewhere on the board
unnamed: IC1.10 (+IN), R-CV-B-ATTN.S
unnamed: CV-A.P$2 (P2), IC1.3 (+IN)
unnamed: CV-A.P$3 (P3), R-CV-A-MAN.S
unnamed: IC1.12 (+IN), R20.1, R21.1
unnamed: IC1.13 (-IN), R22.2, R23.2
unnamed: CV-B.P$2 (P2), IC1.5 (+IN)
unnamed: IC1.6 (-IN), IC1.7 (OUT), R-CV-B-ATTN.E
V+: IC1.4 (V+); also elsewhere on the board
V-: IC1.11 (V-); also elsewhere on the board

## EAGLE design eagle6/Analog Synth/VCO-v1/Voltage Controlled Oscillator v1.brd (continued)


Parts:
C16, C18: 18 nF; C2.5-2
C17: 0.1 µF; C5B2.5
C19: 33 nF; C2.5-2
C23: 1 µF; C025-060X050
IC0: CA3046; DIL14
IC2: TL084P; DIL14
Q5, Q6: 2N7000
R53: 3.9 kΩ; 0204/7
R54: 100 kΩ; 0204/7
R55, R59: 22 kΩ; 0204/7
R56, R64: 47 kΩ; 0204/7
R57: 33 kΩ; 0204/7
R58, R60, R61: 10 kΩ; 0204/7
R63: 1 kΩ; 0204/7
R76, R77, R78, R79: 470 Ω; 0204/7
R80, R81, R82: 2.2 kΩ; 0204/7
R-CV-FREQ-SCALE: 10 kΩ; B64Y
R-MIRROR-BIAS: 10 kΩ; B64Y
S1: 255SB
T2: 2N3906-PNP-TO92-EBC; TO92-EBC

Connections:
CV-COMBINED: R-CV-FREQ-SCALE.E, R-CV-FREQ-SCALE.S; also elsewhere on the board
GND: C16.2, C17.1, C18.1, IC0.4 (B2), IC2.3 (+IN), R59.1, R61.1; also elsewhere on the board
unnamed: IC0.3 (E), R53.2
unnamed: IC2.14 (OUT), R53.1
unnamed: C17.2, IC2.10 (+IN), R54.1, R59.2
unnamed: IC2.9 (-IN), R60.2
unnamed: IC2.8 (OUT), R55.2
unnamed: R55.1, R-MIRROR-BIAS.A
unnamed: C16.1, IC0.1 (C1), IC2.13 (-IN), R-MIRROR-BIAS.E, R-MIRROR-BIAS.S
unnamed: C18.2, IC2.12 (+IN), R60.1, R61.2
unnamed: IC2.5 (+IN), R56.1, R57.2, R58.1
unnamed: IC2.1 (OUT), R63.1
unnamed: IC2.2 (-IN), R63.2, R64.1
unnamed: R64.2, R-CV-FREQ-SCALE.A
unnamed: IC2.7 (OUT), Q6.G
unnamed: Q6.D, R76.2, R77.2, R78.2, R79.2, R80.2
unnamed: R80.1, T2.B
unnamed: Q5.G, R56.2, R81.1, R82.1, T2.C
unnamed: C23.2, S1.1 (O)
RAMP-DOWN-RAW: C19.1, IC0.5 (C2), IC2.6 (-IN), Q5.S, S1.2; also elsewhere on the board
V+: C19.2, C23.1, IC2.4 (V+), Q5.D, R54.2, R58.2, R76.1, R77.1, R78.1, R79.1, T2.E; also elsewhere on the board
V-: IC2.11 (V-), Q6.S, R57.1, R81.2, R82.2; also elsewhere on the board


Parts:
C5: 1 nF; C2.5-2
D1, D2: 1N4004; DO41-10
Q3: 2N3906; TO92
R1, R3, R38: 220 kΩ; 0204/7
R5: 10 kΩ; 0204/7
R6: 1 kΩ; 0204/7
R-RESET-LVL: 10 kΩ; B64Y
RESET: I/O; MONO_JACK
T1, T3, T4, T5: 2N3904; TO92

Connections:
47393747: Q3.1 (C), R6.1
GND: C5.1, D1.A, D2.A, R-RESET-LVL.E, R-RESET-LVL.S, RESET.P$1, RESET.P$3 (P3), T1.3 (E), T3.3 (E), T5.3 (E); also elsewhere on the board
unnamed: R38.1, T5.2 (B)
unnamed: C5.2, D2.C, R3.1, T3.2 (B)
unnamed: R5.2, T1.1 (C)
unnamed: R1.2, R3.2, R38.2, RESET.P$2 (P2)
unnamed: D1.C, R1.1, T1.2 (B), T3.1 (C)
unnamed: Q3.2 (B), R5.1
unnamed: R6.2, R-RESET-LVL.A, T4.2 (B)
RAMP-DOWN-RAW: T4.3 (E); also elsewhere on the board
RESET: T5.1 (C); also elsewhere on the board
V+: Q3.3 (E), T4.1 (C); also elsewhere on the board


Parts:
C20: 100 pF; C2.5-2
D3, D4: 4148; DIODE-0204/5
IC3: TL084P; DIL14
IC5: LM833N; DIL08
R67, R68: 100 kΩ; 0204/7
R69, R70, R75: 1 kΩ; 0204/7
R-RAMP-BIAS: 100 kΩ; B64Y
R-RAMP-GAIN: 100 kΩ; B64Y
R-TRI-BIAS: 100 kΩ; B64Y
R-TRI-GAIN: 100 kΩ; B64Y
RAMP_DOWN: I/O; MONO_JACK
RAMP_UP: I/O; MONO_JACK
TRIANGLE: I/O; MONO_JACK

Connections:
ASASDFASDF: IC3.7 (OUT), IC3.10 (+IN), R67.1, R69.1, R-RAMP-GAIN.A
GND: IC3.12 (+IN), R-RAMP-GAIN.E, R-TRI-GAIN.A, RAMP_DOWN.P$1, RAMP_UP.P$1, TRIANGLE.P$1; also elsewhere on the board
unnamed: IC5.5 (+IN), R-TRI-BIAS.S
unnamed: IC3.1 (OUT), IC3.2 (-IN), R-RAMP-BIAS.E
unnamed: IC3.6 (-IN), R-RAMP-GAIN.S
unnamed: IC3.13 (-IN), R67.2, R68.1
unnamed: D4.ANODE, IC3.8 (OUT)
unnamed: D3.ANODE, IC5.1 (OUT)
unnamed: D3.CATHODE, D4.CATHODE, IC3.9 (-IN), IC5.2 (-IN), R-TRI-BIAS.A
unnamed: C20.2, IC5.6 (-IN), R-TRI-GAIN.S
unnamed: R75.2, TRIANGLE.P$2 (P2), TRIANGLE.P$3 (P3)
unnamed: IC3.5 (+IN), R-RAMP-BIAS.S
RAMP-DOWN-RAW: IC3.3 (+IN); also elsewhere on the board
RAMP-UP-RAW: IC3.14 (OUT), IC5.3 (+IN), R68.2, R70.1; also elsewhere on the board
RAMP_DOWN1: R69.2, RAMP_DOWN.P$2 (P2), RAMP_DOWN.P$3 (P3)
RAMP_UP2: R70.2, RAMP_UP.P$2 (P2), RAMP_UP.P$3 (P3)
TRIANGLE-RAW: C20.1, IC5.7 (OUT), R75.1, R-TRI-GAIN.E; also elsewhere on the board
V+: IC3.4 (V+), IC5.8 (V+); also elsewhere on the board
V-: IC3.11 (V-), IC5.4 (V-), R-RAMP-BIAS.A, R-TRI-BIAS.E; also elsewhere on the board


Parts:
CV-PWM: I/O; MONO_JACK
IC4: TL084P; DIL14
IC9, IC10: TL082P; DIL08
PWM: I/O; MONO_JACK
R2, R4: 1 kΩ; 0204/7
R34, R35, R36, R37: 100 kΩ; 0204/7
R-CV-PWM-MAN: 100 kΩ; B64Y
R-PWM-GAIN: 10 kΩ; B64Y
R-SQUARE-GAIN: 10 kΩ; B64Y
SQUARE2: I/O; MONO_JACK

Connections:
5V: R-CV-PWM-MAN.E; also elsewhere on the board
83NF8Q8FJA: IC9.1 (OUT), IC9.2 (-IN), R35.2
-5V: R-CV-PWM-MAN.A; also elsewhere on the board
CV-B: IC9.6 (-IN), IC9.7 (OUT), R34.2; also elsewhere on the board
CV-PWM: IC10.1 (OUT), IC10.5 (+IN), R36.1; also elsewhere on the board
GND: CV-PWM.P$1, CV-PWM.P$3 (P3), IC4.3 (+IN), PWM.P$1, R37.1, R-PWM-GAIN.E, R-SQUARE-GAIN.E, SQUARE2.P$1; also elsewhere on the board
unnamed: IC4.5 (+IN), R-SQUARE-GAIN.S
unnamed: IC4.1 (OUT), R-SQUARE-GAIN.A
unnamed: R2.2, SQUARE2.P$2 (P2), SQUARE2.P$3 (P3)
unnamed: IC4.10 (+IN), R-PWM-GAIN.S
unnamed: IC10.7 (OUT), R-PWM-GAIN.A
unnamed: PWM.P$2 (P2), PWM.P$3 (P3), R4.2
unnamed: CV-PWM.P$2 (P2), IC9.3 (+IN)
unnamed: IC10.3 (+IN), R34.1, R35.1
unnamed: IC10.2 (-IN), R36.2, R37.2
PWM-RAW: IC4.8 (OUT), IC4.9 (-IN), R4.1; also elsewhere on the board
RAMP-UP-RAW: IC4.2 (-IN), IC10.6 (-IN); also elsewhere on the board
SQUARE-RAW: IC4.6 (-IN), IC4.7 (OUT), R2.1; also elsewhere on the board
V+: IC4.4 (V+), IC9.8 (V+), IC10.8 (V+); also elsewhere on the board
V-: IC4.11 (V-), IC9.4 (V-), IC10.4 (V-); also elsewhere on the board


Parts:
C1: 150 pF; C2.5-2
C2: 1.5 nF; C2.5-2
IC6: TL084P; DIL14
Q1, Q2: 2N3904; TO92
R7, R8: 2.2 kΩ; 0204/7
R9: 390 Ω; 0204/7
R10: 18 kΩ; 0204/7
R11, R12, R13, R14, R19: 10 kΩ; 0204/7
R18: 22 kΩ; 0204/7
R24: 1 kΩ; 0204/7
R-SINE-AMPL: 100 kΩ; B64Y
R-SINE-ROUND: 100 kΩ; B64Y
R-SINE-SYMM: 10 kΩ; B64Y
SINE: I/O; MONO_JACK

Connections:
GND: C2.1, IC6.5 (+IN), IC6.12 (+IN), R7.2, R8.2, R13.1, SINE.P$1; also elsewhere on the board
unnamed: IC6.6 (-IN), R-SINE-AMPL.S
unnamed: Q1.2 (B), R7.1, R-SINE-ROUND.E
unnamed: Q2.2 (B), R8.1
unnamed: Q1.3 (E), R9.1, R-SINE-SYMM.A
unnamed: Q2.3 (E), R9.2, R-SINE-SYMM.E
unnamed: R10.1, R-SINE-SYMM.S
unnamed: IC6.2 (-IN), Q1.1 (C), R11.1, R14.1
unnamed: IC6.1 (OUT), R14.2, R-SINE-AMPL.A
unnamed: IC6.3 (+IN), Q2.1 (C), R12.1, R13.2
unnamed: IC6.7 (OUT), R18.1, R-SINE-AMPL.E
unnamed: C1.2, R18.2, R19.1
unnamed: C2.2, IC6.10 (+IN), R19.2
unnamed: IC6.13 (-IN), IC6.14 (OUT)
RAMP_UP1: R24.2, SINE.P$2 (P2), SINE.P$3 (P3)
SINE-RAW: C1.1, IC6.8 (OUT), IC6.9 (-IN), R24.1; also elsewhere on the board
TRIANGLE-RAW: R-SINE-ROUND.A, R-SINE-ROUND.S; also elsewhere on the board
V+: IC6.4 (V+), R11.2, R12.2; also elsewhere on the board
V-: IC6.11 (V-), R10.2; also elsewhere on the board


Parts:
LED-CV-A: LED3MM
LED-CV-B: LED3MM
LED-CV-PWM: LED3MM
LED-PWM: LED3MM
LED-RAMP-DOWN: LED3MM
LED-RAMP-UP: LED3MM
LED-RESET: LED3MM
LED-SINE: LED3MM
LED-SQUARE: LED3MM
LED-TRIANGLE: LED3MM
R15, R16, R17, R26, R27, R30, R31, R32, R33: 4.7 kΩ; 0204/7
R25: 22 kΩ; 0204/7

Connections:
-5V: R15.2, R16.2, R17.2, R26.2, R27.2, R30.2, R31.2, R32.2, R33.2; also elsewhere on the board
CV-A: LED-CV-A.A; also elsewhere on the board
CV-B: LED-CV-B.A; also elsewhere on the board
CV-PWM: LED-CV-PWM.A; also elsewhere on the board
unnamed: LED-RESET.A, R25.1
unnamed: LED-CV-A.K (C), R15.1
unnamed: LED-CV-B.K (C), R16.1
unnamed: LED-CV-PWM.K (C), R17.1
unnamed: LED-RAMP-DOWN.K (C), R26.1
unnamed: LED-RAMP-UP.K (C), R27.1
unnamed: LED-TRIANGLE.K (C), R30.1
unnamed: LED-SINE.K (C), R31.1
unnamed: LED-SQUARE.K (C), R32.1
unnamed: LED-PWM.K (C), R33.1
PWM-RAW: LED-PWM.A; also elsewhere on the board
RAMP-DOWN-RAW: LED-RAMP-DOWN.A; also elsewhere on the board
RAMP-UP-RAW: LED-RAMP-UP.A; also elsewhere on the board
RESET: LED-RESET.K (C); also elsewhere on the board
SINE-RAW: LED-SINE.A; also elsewhere on the board
SQUARE-RAW: LED-SQUARE.A; also elsewhere on the board
TRIANGLE-RAW: LED-TRIANGLE.A; also elsewhere on the board
V+: R25.2; also elsewhere on the board

Board: 2 copper layers, 142 parts (0 on the bottom side), 98 nets, no tracks yet.

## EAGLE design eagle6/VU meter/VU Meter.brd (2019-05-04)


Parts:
GND: PINHD-1X1; 1X01
IC1, IC2, IC3, IC4: LM324N; DIL14
JP4: PINHD-1X16; 1X16
R1, R2, R3, R4, R5, R6, R7, R8, R9, R10, R11, R12, R13, R14, R15, R16, R17: 10k; 0204/7
VCC: PINHD-1X1; 1X01
VIN: PINHD-1X1; 1X01
VREF: PINHD-1X1; 1X01

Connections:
AGND: GND.1, IC1.11 (V-), IC2.11 (V-), IC3.11 (V-), IC4.11 (V-), R17.2
unnamed: IC4.9 (-IN), R14.1, R15.2
unnamed: IC1.3 (+IN), IC1.5 (+IN), IC1.10 (+IN), IC1.12 (+IN), IC2.3 (+IN), IC2.5 (+IN), IC2.10 (+IN), IC2.12 (+IN), IC3.3 (+IN), IC3.5 (+IN), IC3.10 (+IN), IC3.12 (+IN), IC4.3 (+IN), IC4.5 (+IN), IC4.10 (+IN), IC4.12 (+IN), VIN.1
unnamed: IC3.13 (-IN), R13.1, R14.2
unnamed: IC3.9 (-IN), R12.1, R13.2
unnamed: IC2.13 (-IN), R11.1, R12.2
unnamed: IC2.9 (-IN), R10.1, R11.2
unnamed: IC1.13 (-IN), R9.1, R10.2
unnamed: IC4.13 (-IN), R15.1, R16.2
unnamed: IC4.2 (-IN), R1.2, R17.1
unnamed: IC4.6 (-IN), R1.1, R2.2
unnamed: IC3.2 (-IN), R2.1, R3.2
unnamed: IC3.6 (-IN), R3.1, R4.2
unnamed: IC2.2 (-IN), R4.1, R5.2
unnamed: IC2.6 (-IN), R5.1, R6.2
unnamed: IC1.2 (-IN), R6.1, R7.2
unnamed: IC1.6 (-IN), R7.1, R8.2
unnamed: IC1.9 (-IN), R8.1, R9.2
unnamed: R16.1, VREF.1
unnamed: IC4.14 (OUT), JP4.1
unnamed: IC4.8 (OUT), JP4.2
unnamed: IC3.14 (OUT), JP4.3
unnamed: IC3.8 (OUT), JP4.4
unnamed: IC2.14 (OUT), JP4.5
unnamed: IC2.8 (OUT), JP4.6
unnamed: IC1.14 (OUT), JP4.7
unnamed: IC1.8 (OUT), JP4.8
unnamed: IC1.7 (OUT), JP4.9
unnamed: IC1.1 (OUT), JP4.10
unnamed: IC2.7 (OUT), JP4.11
unnamed: IC4.1 (OUT), JP4.16
unnamed: IC4.7 (OUT), JP4.15
unnamed: IC3.1 (OUT), JP4.14
unnamed: IC3.7 (OUT), JP4.13
unnamed: IC2.1 (OUT), JP4.12
V+: IC1.4 (V+), IC2.4 (V+), IC3.4 (V+), IC4.4 (V+)


Board: 2 copper layers, 102.5 x 41.9 mm, 26 parts (0 on the bottom side), 36 nets.

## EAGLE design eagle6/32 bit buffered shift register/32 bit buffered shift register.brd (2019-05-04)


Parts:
BFFR_UPDT: PINHD-1X1; 1X01
GND: PINHD-1X1; 1X01
IC1A, IC2A, IC3A, IC4A: 74HC164N; DIL14
IC1B, IC2B, IC3B, IC4B: 74273N; DIL20
P1, P2, P3, P4, P5, P6, P7, P8, P9, P10, P11, P12, P13, P14, P15, P16, P17, P18, P19, P20, P21, P22, P23, P24, P25, P26, P27, P28, P29, P30, P31, P32: PINHD-1X1; 1X01
SHFT_CLK: PINHD-1X1; 1X01
SHFT_D: PINHD-1X1; 1X01
VCC: PINHD-1X1; 1X01

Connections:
GND: GND.1, IC1A.7 (GND), IC1B.10 (GND), IC2A.7 (GND), IC2B.10 (GND), IC3A.7 (GND), IC3B.10 (GND), IC4A.7 (GND), IC4B.10 (GND)
unnamed: IC1B.2 (Q1), P1.1
unnamed: IC1B.5 (Q2), P2.1
unnamed: IC1B.6 (Q3), P3.1
unnamed: IC1B.9 (Q4), P4.1
unnamed: IC1B.12 (Q5), P5.1
unnamed: IC1B.15 (Q6), P6.1
unnamed: IC1B.16 (Q7), P7.1
unnamed: IC1B.19 (Q8), P8.1
unnamed: IC2B.2 (Q1), P9.1
unnamed: IC2B.5 (Q2), P10.1
unnamed: IC2B.6 (Q3), P11.1
unnamed: IC2B.9 (Q4), P12.1
unnamed: IC2B.12 (Q5), P13.1
unnamed: IC2B.15 (Q6), P14.1
unnamed: IC2B.16 (Q7), P15.1
unnamed: IC2B.19 (Q8), P16.1
unnamed: IC3B.2 (Q1), P17.1
unnamed: IC3B.5 (Q2), P18.1
unnamed: IC3B.6 (Q3), P19.1
unnamed: IC3B.9 (Q4), P20.1
unnamed: IC3B.12 (Q5), P21.1
unnamed: IC3B.15 (Q6), P22.1
unnamed: IC3B.16 (Q7), P23.1
unnamed: IC3B.19 (Q8), P24.1
unnamed: IC4B.2 (Q1), P25.1
unnamed: IC4B.5 (Q2), P26.1
unnamed: IC4B.6 (Q3), P27.1
unnamed: IC4B.9 (Q4), P28.1
unnamed: IC4B.12 (Q5), P29.1
unnamed: IC4B.15 (Q6), P30.1
unnamed: IC4B.16 (Q7), P31.1
unnamed: IC4B.19 (Q8), P32.1
unnamed: IC1A.3 (QA), IC1B.3 (D1)
unnamed: IC1A.4 (QB), IC1B.4 (D2)
unnamed: IC1A.5 (QC), IC1B.7 (D3)
unnamed: IC1A.6 (QD), IC1B.8 (D4)
unnamed: IC1A.10 (QE), IC1B.13 (D5)
unnamed: IC1A.11 (QF), IC1B.14 (D6)
unnamed: IC1A.12 (QG), IC1B.17 (D7)
unnamed: IC1A.13 (QH), IC1B.18 (D8), IC2A.1 (A)
unnamed: IC2A.3 (QA), IC2B.3 (D1)
unnamed: IC2A.4 (QB), IC2B.4 (D2)
unnamed: IC2A.5 (QC), IC2B.7 (D3)
unnamed: IC2A.6 (QD), IC2B.8 (D4)
unnamed: IC2A.10 (QE), IC2B.13 (D5)
unnamed: IC2A.11 (QF), IC2B.14 (D6)
unnamed: IC2A.13 (QH), IC2B.18 (D8), IC3A.1 (A)
unnamed: IC3A.3 (QA), IC3B.3 (D1)
unnamed: IC3A.4 (QB), IC3B.4 (D2)
unnamed: IC3A.5 (QC), IC3B.7 (D3)
unnamed: IC3A.6 (QD), IC3B.8 (D4)
unnamed: IC3A.10 (QE), IC3B.13 (D5)
unnamed: IC3A.11 (QF), IC3B.14 (D6)
unnamed: IC3A.12 (QG), IC3B.17 (D7)
unnamed: IC3A.13 (QH), IC3B.18 (D8), IC4A.1 (A)
unnamed: IC4A.3 (QA), IC4B.3 (D1)
unnamed: IC4A.4 (QB), IC4B.4 (D2)
unnamed: IC4A.5 (QC), IC4B.7 (D3)
unnamed: IC4A.6 (QD), IC4B.8 (D4)
unnamed: IC4A.10 (QE), IC4B.13 (D5)
unnamed: IC4A.11 (QF), IC4B.14 (D6)
unnamed: IC4A.12 (QG), IC4B.17 (D7)
unnamed: IC4A.13 (QH), IC4B.18 (D8)
unnamed: BFFR_UPDT.1, IC1B.11 (CLK), IC2B.11 (CLK), IC3B.11 (CLK), IC4B.11 (CLK)
unnamed: IC1A.1 (A), SHFT_D.1
unnamed: IC1A.8 (CLK), IC2A.8 (CLK), IC3A.8 (CLK), IC4A.8 (CLK), SHFT_CLK.1
unnamed: IC2A.12 (QG), IC2B.17 (D7)
VCC: IC1A.2 (B), IC1A.9 (CLR), IC1A.14 (VCC), IC1B.1 (CLR), IC1B.20 (VCC), IC2A.2 (B), IC2A.9 (CLR), IC2A.14 (VCC), IC2B.1 (CLR), IC2B.20 (VCC), IC3A.2 (B), IC3A.9 (CLR), IC3A.14 (VCC), IC3B.1 (CLR), IC3B.20 (VCC), IC4A.2 (B), IC4A.9 (CLR), IC4A.14 (VCC), IC4B.1 (CLR), IC4B.20 (VCC), VCC.1


Board: 2 copper layers, 105.1 x 59.7 mm, 45 parts (0 on the bottom side), 69 nets.

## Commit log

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2014-11-28 Working on analog synth stuff. Also just started the schematic for senior design (really just making the ATtiny24A symbol and package)
    [16-Step Dual Sequencer.brd, 8-Step Sequencer.sch, 8-step Sequencer.brd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]
2015-01-23 added pad-per-hole strip protoype board, updated VCO v1, did some gerber stuff
    [8-Step Sequencer.sch, CV.sch, How to drive outputs.sch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]
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2015-01-25 working on VCO-v1. optimizing circuit. removing resistors in favor of better pot placement.
    [Voltage Controlled Oscillator v1.brd, Voltage Controlled Oscillator v1.sch]
2015-01-26 added reset circuitry to VCO-v1
    [Voltage Controlled Oscillator v1.brd, Voltage Controlled Oscillator v1.sch]
2015-01-26 fixed capacitor values
    [Voltage Controlled Oscillator v1.brd, Voltage Controlled Oscillator v1.sch]
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2015-01-27 fixed stupid error with op amp inputs for frequency generation.
    [Voltage Controlled Oscillator v1.brd, Voltage Controlled Oscillator v1.sch]
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2015-01-31 fixed Reset LED configuration
    [Voltage Controlled Oscillator v1.brd, Voltage Controlled Oscillator v1.sch]
2015-02-05 VCO-v1 had SOMETHING done to it. What was done, I know not.
    [Voltage Controlled Oscillator v1.brd, Voltage Controlled Oscillator v1.sch]
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2015-02-15 added Attack-Release schematic with a JFET-based VCA that won't work. I will need to modify the schematic for a bual board.
    [AR - Attack Release.brd, AR - Attack Release.sch]
2015-02-17 Added Voltage Controlled Amplifier v1. The thing actually works to some degree!!
    [Voltage Controlled Amplifier v1.brd, Voltage Controlled Amplifier v1.sch]
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2015-03-06 working on Power Distribution and VCA.
    When playing with my VCA on my bench, I discovered it can be used as an AM radio to pick up a local station on 1420 kHz (KTOE in Mankato)
    [Power Distribution Board.brd, Voltage Controlled Amplifier v1.brd, Voltage Controlled Amplifier v1.sch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]
2015-03-06 Working on VCA-v1 more. I need to add LED driving circuitry (LEDs, resistors, and a -5V source). Also, the silkscreen for the audio in/out jacks is on the back layer instead of the front. Fix this.
    [Voltage Controlled Amplifier v1.brd, Voltage Controlled Amplifier v1.sch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]
2015-03-07 working on VCA more. added caps to filter RF by shunting high frequencies to ground.
    [Voltage Controlled Amplifier v1.brd, Voltage Controlled Amplifier v1.sch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]
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2015-03-08 started schematic for analog switch. also changed a diode in a standard library
    [Quad Analog Switch.sch]
2015-03-09 revamped the analog switch circuit. two op amps, two transistors (a diode, and some resistors)
    [Bidirectional Analog Switch.sch, Quad Analog Switch.sch]
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2015-03-21 Updated the analog switch so that it doesn't suck so much. - Removed transistor and resistors. - Replaced with a diode to the gate of the JFET. - Changed grounding resistor from 330k to 56k. This was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
    [Analog Switch.sch]
2015-03-23 working on VCA front panel.
    -CV at the top (with attenuation proceeded by offset adjustment)
    - Audio In in the middle (with attenuation)
    - Audio Out at the bottom.
    [VCA-v1.brd]
2015-03-24 changed a single trace placement with the Senior Design project.(it was too close to the edge of the board) Also exported gerbers for OSHpark
    [circuit.brd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]
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2015-09-14 working on the Echo Chamber schematic; PT2399 was added to \!synth_sch library
    [Echo Chamber.brd, Echo Chamber.sch]
2015-09-14 fixed little bug with the Echo Chamber schematic
    [Echo Chamber.brd, Echo Chamber.sch]
2015-09-14 added some guide information to the schematic for the LEDs and the diodes, as well as referencing the data sheet as the source of the basic design of the PT2399 circuit
    [Echo Chamber.sch]
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2015-09-20 I realized that I have more work to do on the schematic than I do have to do on the Panel. The circuit needs to be figured out exactly first. But that shouldn't take long. The filter may pose a sligh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
    [Dual Sequencer.brd]
2015-10-10 working on VCO-v2 schematic; added a library part for CA3096 transistor array into that library that some other guy started
    [Echo Chamber.sch, VCO-v2.sch]
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2015-10-10 VCO-v2 - power supply. Also, I need to change those integration caps to be polarized types in the schematic and on the pcb...
    [VCO-v2.brd, VCO-v2.sch]
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2015-10-13 VCO-v2 - version 2.1 released! I changed a few things with the triangle-to-freq converter; I made the LEDs go into a bjt voltage source rather than the +5 V and -5 V regulated supplies, because conne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
    [VCO-v2.brd, VCO-v2.sch]
2015-10-17 fixed error in VCO-v2 schematic - CV sum had a tuner going to -5 V instead of -9 V
    [VCO-v2.brd, VCO-v2.sch]
2015-10-18 VCO-v2 - increased size of resistors around the triangle-wave x2 gain stage
    [VCO-v2.brd, VCO-v2.sch]
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2015-11-03 PS-VCO still working on PCB - making gerbers. proof reading. Need to add an LED for the CV signal
    [PS-VCO.GBL, PS-VCO.GBO, PS-VCO.GBS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]
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2015-11-05 PS-VCO updating schematic. made it look cleaner. Added information about theory of operation and instructions for building.
    [PS-VCO.GBL, PS-VCO.GBO, PS-VCO.GBS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]
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2015-11-08 CBS - Cigar Box Sequencer - 8 step - starting to put together a schematic for it
    [Sequencer - 8 Step - Cigar Box.sch, VCO-v2.brd]
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2015-11-12 CBS: still working on schematic. I need to make sure I understand how I thought this was supposed to work BEFORE I start soldering things together
    [Sequencer - 8 Step - Cigar Box.sch]
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2015-11-14 CBS: added the switches for the GATE output that replaces the clock output
    [Sequencer - 8 Step - Cigar Box.sch]
2015-11-14 CBS: renamed the CLK_OUT jack to GATE_OUT, as I decided to substitude and effective clock output for the combination of gates.
    [CBS - Cigar Box Sequencer - 8 step.brd]
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2015-11-15 CBS: fixed output resistor values
    [Sequencer - 8 Step - Cigar Box.sch]
2015-11-15 CBS: fixed output resistor values - other ones
    [Sequencer - 8 Step - Cigar Box.sch]
2015-11-15 CBS: fixed output jack ground issue
    [Sequencer - 8 Step - Cigar Box.sch]
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2015-11-15 CBS: fixed the CV-OUT resistor value from 2.2k to 1k
    [Sequencer - 8 Step - Cigar Box.sch]
2015-11-16 CBS: changed the binary input/output bypass connections so that the user cannot short the outputs of the 193 binary counter.
    [Sequencer - 8 Step - Cigar Box.sch]
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2015-12-01 CBS: fixed missing potentiometer value for output CV filter
    [Sequencer - 8 Step - Cigar Box.sch]
2016-02-22 PS-VCO: updating documentation and schematic. rendered pdfs for schematic and pcb. generated a BOM
    [12 things spaced evenly inside 7 inches.brd, PS-VCO.brd, PS-VCO.sch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]
2016-02-25 updating PS-VCO. Changed a resistor value to get closer to 50% duty cycle. It is still very approximate, but before the duty cycle was around 25% or 30% or something really obviously not balanced.
    [PS-VCO.brd, PS-VCO.sch]
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2016-04-23 FreqCount84 adding Input Stage (AC / DC coupling and Amplification); updated resistor and capacitor libraries so that the values and names are on the same side of the symbol rather than opposite sides
    [FreqCount84.brd, FreqCount84.sch]
2016-04-25 added the FTDI USB->RS232 chip into the schematic because I am using it now.
    [FreqCount84.brd, FreqCount84.sch]
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2016-06-06 adding VCA-v2 initial stuff to the repo. SCH is not really created yet, I just copied VCA-v1
    [VCA-v2.brd, VCA-v2.sch]
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2017-07-14 ^XPhone Input Board layout; +bug record
    [Input Board.kicad_pcb, Input Board.sch]
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2017-07-19 fixed -12V symbol (used to have +12V pin name which automatically connected it with the +12 V supply. BAD. Updated XPhone/Input_Board too
    [Input Board.kicad_pcb, Input Board.sch]
2017-07-19 XPhone/Input_Board - fixed bug - +12V and -12V were the same net. Not any more
    [Input Board.kicad_pcb]
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2017-07-20 XPhone/Input_Board fixed L orientation (not a big deal, but it bugged me)
    [Input Board.kicad_pcb]
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2017-07-24 XPhone/Input_Board +mounting holes; ^silkscreen; +bug picture
    [Input Board.kicad_pcb]
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2017-07-25 fixed generation of panel
    [Input Board Panel.kicad_pcb, Input Board.kicad_pcb]
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2017-07-26 XPhone/Input_Board fixing up the F.Fab layer
    [Input Board-B.Cu.gbr, Input Board-B.Fab.gbr, Input Board-B.Mask.gbr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]
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2019-05-04 deleted: references, bugs, and Test_Project
    [Test_Project.kicad_pcb, Test_Project.sch]
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2022-06-17 silent susan v5.5 - fixed bolt hole; got Path looking good; generate first G-code; added G-code cheat sheet web page"
    [silent susan v5.5.step, silent susan v5.FCStd]
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2022-06-19 changed washer clearance to 100 thou on each side to avoid interference.
    [silent susan v5.FCStd]
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2022-08-26 fixed napkin holder 2.2
    [napkin holder v2.2.FCStd]
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2024-08-20 Add fixed TerminalBlock_MetzConnect footprints
2024-08-20 Fix expression pedal Terminal Block
    [BOM.csv, BOM.ods, expression-pedal-to-pwm.kicad_pcb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]
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

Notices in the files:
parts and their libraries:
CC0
